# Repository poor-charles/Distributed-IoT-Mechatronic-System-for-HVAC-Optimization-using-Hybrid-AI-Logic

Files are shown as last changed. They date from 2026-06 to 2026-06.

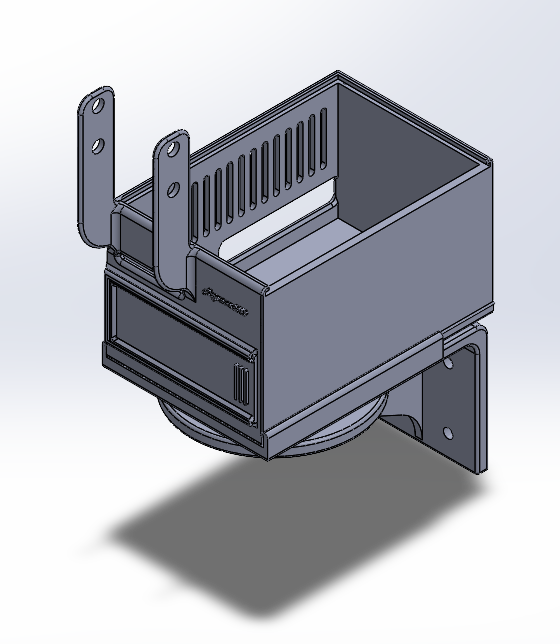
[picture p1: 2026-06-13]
Hardware System Files/Enclosures/Raspberry Pi 5/Raspberry Pi 5 Enclosure Assembly.png

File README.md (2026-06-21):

# Distributed-IoT-Mechatronic-System-for-HVAC-Optimization-using-Hybrid-AI-Logic
A Bayesian Optimized Random Forest model integrated with deterministic physics based safety guardrails to control HVAC operation modes, hunting for the operational settings that minimizes energy consumption while maintaining comfort based on ASHRAE 55 Standards.

--> The Repo contains all the necessary files, programs, and data along with instructions to replicate the system. 

--> Necessary adjustments in the programs such as file locations/directories indicated in the program globals MUST BE CHANGED accordingly.

[AI Model Files]
- To be updated & managed by Charles Vincent Mayaman

[Digital Twin Model Files]
- To be updated & managed by Rissby Arne Cerna

[Hardware System Files]
- Updated & Managed by Paolo Renomeron

General Note: To be updated...

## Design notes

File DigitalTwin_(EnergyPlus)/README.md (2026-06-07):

# Digital Twin (EnergyPlus) Framework for HVAC Energy Performance Assessment

## Overview

This repository contains the complete implementation of an EnergyPlus-based Digital Twin developed for HVAC energy performance assessment through virtual parallel operation. The framework integrates Building Energy Modeling (BEM), Bayesian calibration, independent validation, MQTT-based real-time telemetry, and operational dashboard visualization.

The Digital Twin was developed to reproduce the operational behavior of the target conference room and enable continuous comparison between measured and simulated building performance. The framework supports both energy-performance assessment and comfort-related evaluation through real-time monitoring of indoor temperature, relative humidity, and Predicted Mean Vote (PMV).

---

## Technologies Used

* EnergyPlus 25.1
* Python
* Eppy
* Pandas
* NumPy
* Scikit-Optimize (Bayesian Optimization)
* MQTT
* Streamlit
* SQLite

---

## Digital Twin Development Workflow

### Script 1 – Data Preprocessing

Prepares and cleans the measured datasets collected from the physical building. Sensor data are synchronized, formatted, and converted into analysis-ready datasets.

### Script 2 – EnergyPlus Schedule Generation

Generates occupancy, thermostat setpoint, and workshop temperature schedules required for EnergyPlus simulation.

### Script 3 – Baseline Model Assessment

Evaluates the performance of the uncalibrated Building Energy Model by comparing simulated results against measured building data.

### Script 4 – Bayesian Optimization Parameter Space Definition

Defines the calibration parameters and allowable search ranges used by the Bayesian optimization framework.

### Script 5 – EnergyPlus Parameter Injection and Simulation Run

Automatically modifies EnergyPlus model parameters based on candidate solutions generated by the optimizer and executes simulation runs.

### Script 6 – Calibration Scoring and Model Performance Evaluation

Calculates calibration metrics including RMSE, CV(RMSE), and NMBE for HVAC energy consumption, indoor temperature, and relative humidity.

### Script 7 – Bayesian Calibration Optimization Loop

Implements Gaussian Process Regression (GPR)-based Bayesian Optimization to identify the parameter set that best matches measured building performance.

### Script 8 – Calibration Results Extraction and Visualization

Extracts the champion calibrated model and generates calibration comparison plots, scatter plots, and residual analyses.

### Script 9 – Independent Validation Data Preparation

Processes unseen operational data and prepares validation schedules and measured datasets.

### Script 10 – Independent Validation Simulation

Executes the calibrated Digital Twin using independent validation data.

### Script 11 – Validation Results Analysis and Visualization

Calculates validation metrics and generates validation time-series plots, scatter plots, and residual histograms.

### Script 12 – Operational Digital Twin Dashboard

Provides a Streamlit-based dashboard for real-time visualization of building performance and Digital Twin outputs.

### Script 13 – Real-Time Operational Digital Twin Engine

Implements live synchronization between the physical asset and EnergyPlus through MQTT communication, enabling real-time virtual parallel assessment.

### Operational Digital Twin Launcher

Automatically launches the Operational Digital Twin Dashboard and Real-Time Digital Twin Engine to support deployment and real-time virtual parallel assessment.

---

## Calibration and Validation Metrics

Calibration Performance:

* HVAC Energy CV(RMSE): 29.96%
* HVAC Energy NMBE: 9.96%

Validation Performance:

* HVAC Energy CV(RMSE): 28.23%
* HVAC Energy NMBE: 7.64%

Both calibration and validation satisfied the ASHRAE Guideline 14 acceptance criteria for hourly energy calibration.

---

## Operational Digital Twin Capabilities

The operational Digital Twin supports:

* Real-time occupancy integration
* Real-time thermostat updates
* Indoor temperature monitoring
* Indoor relative humidity monitoring
* PMV monitoring
* HVAC energy assessment
* Virtual parallel assessment
* Dashboard-based visualization

---

## Research Contribution

This work demonstrates the feasibility of developing a calibrated and validated EnergyPlus-based Digital Twin using open-source technologies for building energy performance assessment, operational monitoring, and future intelligent building applications.

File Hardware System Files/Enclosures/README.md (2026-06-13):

eto yung mga enclosures and shii

mor instructions inside

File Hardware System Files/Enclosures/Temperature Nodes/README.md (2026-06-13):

ESP 1 (Dynamic Inside Sensor) and ESP 3 (Outside Sensor) Enclosure Folder:

-----------------------------------------------------------------------------------

Use the attached .gcode to directly print the enclosure and and its covers.

Feel free to modify the .SLDPRT version if you want to add or edit features.

-----------------------------------------------------------------------------------

Setting:
  Bambu Lab A1 Mini, PLA Lite

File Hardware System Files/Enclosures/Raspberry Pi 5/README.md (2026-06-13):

Raspberry Pi 5 Enclosure and Platform Folder:

-----------------------------------------------------------------------------------

Refer to the .png file included for the enclosure assembly.

Use the attached .gcode to directly print the enclosure and its platform.

Feel free to modify the .SLDPRT version if you want to add or edit features.

-----------------------------------------------------------------------------------

Setting:
  Bambu Lab A1 Mini, PLA Lite

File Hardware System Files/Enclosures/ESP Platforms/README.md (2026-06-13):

ESP Node Platform Folder:

-----------------------------------------------------------------------------------

Setting:
  Bambu Lab A1 Mini, PLA Lite

  ESP 2, ESP 4, and ESP 5 uses Stand v1
  
  ESP 3 uses Stand v3
  
  ESP 1 does not need a platform

-----------------------------------------------------------------------------------

Refer to the .png files included for the platform orientation.

Use the attached .gcode to directly print the enclosure and and its covers.

Feel free to modify the .SLDPRT version if you want to add or edit features.

-----------------------------------------------------------------------------------

Setting:
  Bambu Lab A1 Mini, PLA Lite

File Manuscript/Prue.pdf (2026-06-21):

DEVELOPMENT OF A DISTRIBUTED IOT MECHATRONIC SYSTEM FOR HVAC OPTIMIZATION USING HYBRID AI LOGIC

A Thesis Manuscript
Presented to the Faculty of the Department of Mechanical Engineering Visayas State University
Visca, Baybay City, Leyte

In Partial Fulfillment
of the Requirements for the Degree of Bachelor of Science in Mechanical Engineering

RISBBY ARNE P. CERNA
CHARLES VINCENT MAYAMAN
PAOLO L. RENOMERON
June 2026

i

APPROVAL SHEET

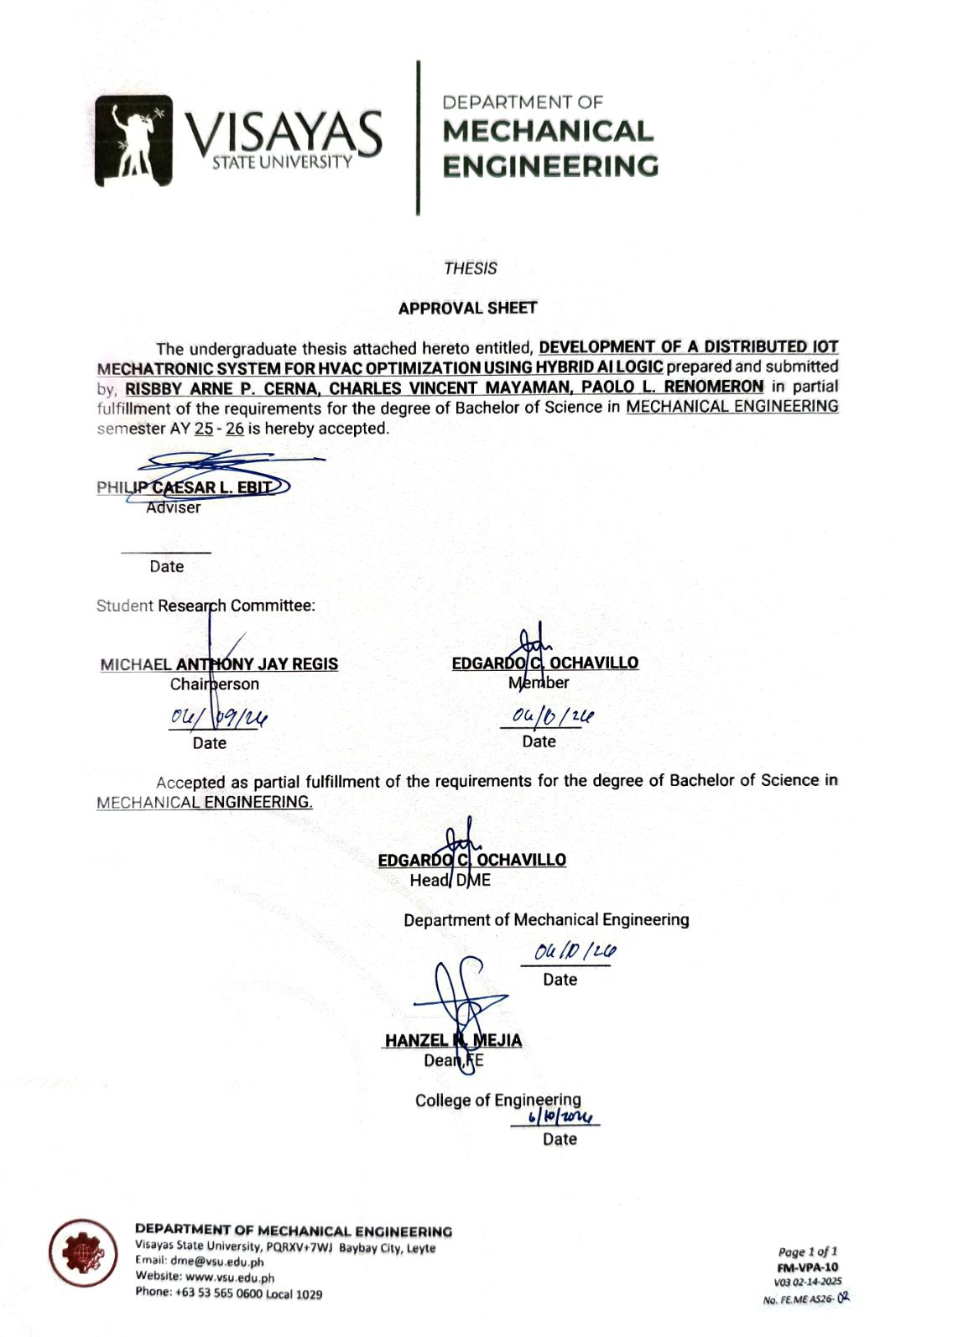
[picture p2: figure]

ii

ENGLISH CRITIC CERTIFICATION

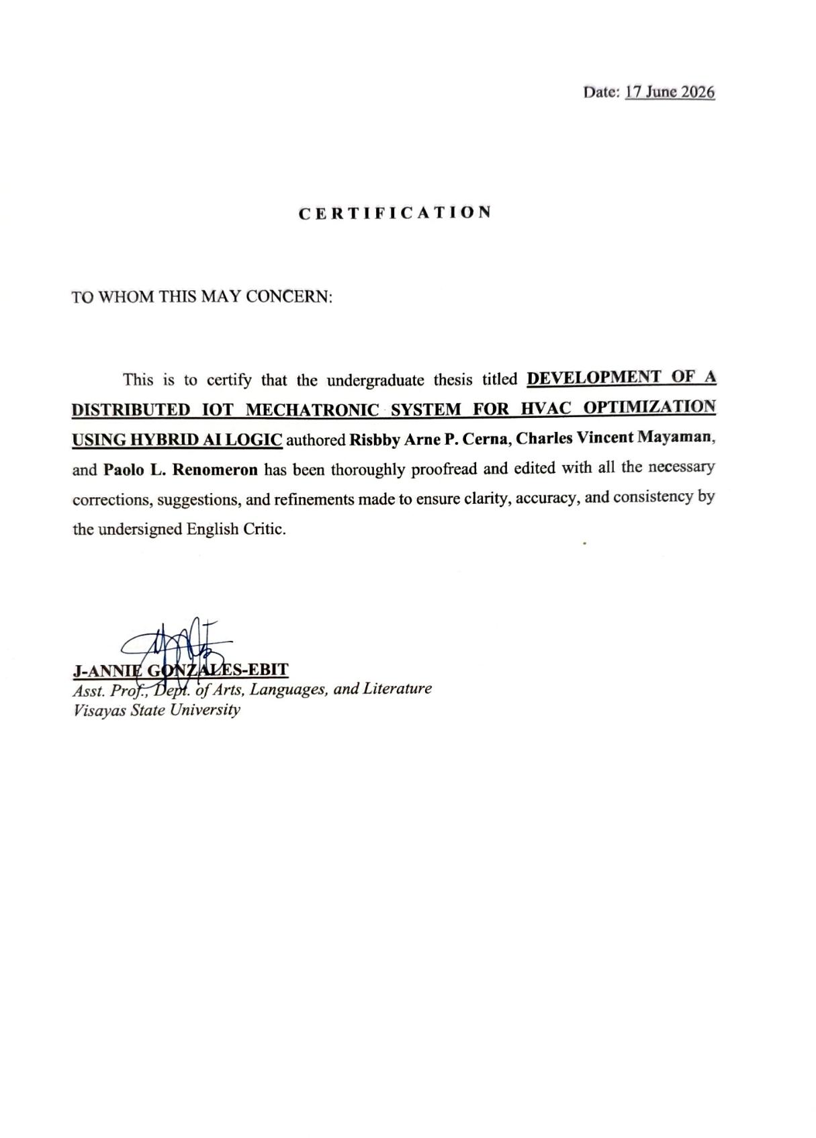
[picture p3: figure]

iii

ACKNOWLEDGMENT

The successful completion of this manuscript would not have been possible

without the invaluable support, guidance, and participation of the following individuals.

The authors would like to take this opportunity to express their sincerest gratitude.

First and foremost, the authors express their deepest gratitude to their research

adviser, Engr. Philip Caesar L. Ebit, and to the chairperson of the Student Research

Committee (SRC), Mr. Michael Anthony Jay Regis, for the invaluable technical

insights, academic mentorship, and profound knowledge they generously shared

throughout this study. Their guidance was instrumental in transforming this research

concept into a reality.

The authors gratefully acknowledge the Department of Science and Technology

- Science Education Institute (DOST-SEI) for providing financial and academic support

to the scholar within the research group, which proved vital to the development of this

project under the RA 7687 Science and Technology Scholarship Act.

Special thanks are due to JASCad for their technical assistance during the

fabrication phase. Their expertise in designing and manufacturing the custom printed

circuit boards (PCBs) is highly appreciated, as these high-fidelity modules ensured

hardware node stability and minimized environmental signal noise during data

collection.

The authors extend their appreciation to the research participants, specifically

the PSME-VSUSC officers and members, whose consistent presence and active

iv

utilization of the target study room facilitated the reliable aggregation of dynamic

occupancy and environmental data. Their cooperation was essential to the completion

of the physical field testing.

Heartfelt thanks go to the researchers’ peers and friends who assisted in various

logistical tasks, ranging from data organization to providing moral support throughout

the data-gathering phase.

The authors are profoundly thankful to their families for their unwavering

patience, understanding, and encouragement during periods of intense academic

pressure. Their constant support and sacrifices served as a vital source of inspiration

throughout this journey.

Above all, the authors offer their ultimate praise and gratitude to the Almighty

God for providing spiritual strength, wisdom, and clarity during moments of

uncertainty, and for granting the grace and guidance necessary to bring this endeavor

to a successful completion.

v

TABLE OF CONTENTS

vi

Multi-Objective Optimization and Digital Twin Applications | 37
The Role of BEM in Digital Twin Architecture | 39
Edge-Hosted Digital Twins | 41
Machine Learning and Data-Driven Optimization | 41
Implementing Digital Twin to Quantify Energy Consumption | 43
Open-Source Building Energy Modeling | 45
OpenStudio Software | 45
OpenStudio Plugin | 46
EnergyPlus Engine | 48
HVAC System in EnergyPlus Engine | 50
Calibration Frameworks | 52
Automated Parametric Calibration in Building Energy Modeling | 53
Why Bayesian Calibration Method? | 54
Derivative-Free Search via Bayesian Optimization | 56
Surrogate Modeling Using Gaussian Processes | 58
ASHRAE Guideline 14 | 59
Automated Frameworks for Quantitative Evaluation | 61
Standardization of Evaluation Metrics for Environmental Variables | 62
International Organization for Standardization (ISO) 13786:2017 | 63
Dynamic Thermal Characterization of Building Components | 64
Theoretical Framework of ISO 13786:2017 | 64
International Organization for Standardization (ISO) 15099:2003 | 66
Thermodynamic Characterization of Fenestration Systems | 66
Thermodynamic Algorithms | 67
International Organization for Standardization (ISO) 6946:2017 | 68
Thermodynamic Characterization of Interstitial Air Cavities | 69

vii

Thermodynamic Mechanics | 69
IoT Architecture in HVAC Systems | 71
HVAC Automation and Control System Architectures | 71
Internet of Things (IoT) Integration in HVAC Systems | 74
Performance Evaluation of IoT-Based HVAC Controllers | 75
Energy Consumption Measurement Methods | 76
Reliability and Communication Performance Metrics | 77
Control Accuracy Assessment | 78
Scalability Analysis of Distributed IoT Systems | 78
Techno-Economic Evaluation of HVAC IoT Controllers | 79
Economic Performance Metrics | 80
METHODOLOGY | 82
Research Workflow | 82
Planning and Design of the System | 84
Thermodynamic Disturbances and Thermal Loads | 86
Exogenous Thermal Loads (Building Envelope Heat Transfer) | 87
Metabolic Heat Generation (Occupancy Load) | 88
Internal Equipment Loads (Parasitic Heat Gains) | 88
Thermal Comfort Optimization Method Using ASHRAE 55 | 89
Headless Occupancy Detection and Counting (YOLOv8n) | 97
Data Acquisition and Machine Learning Training | 101
Variable Classification and Measurement Parameters | 102
Telemetry Architecture and Data Aggregation | 103
Experimental Boundary Scenarios | 103
Dataset Finalization | 104
Machine Learning Framework and Model Training (BORF) | 105

viii

The Supervisory Controller [Raspberry Pi 5] | 109
Operating System Installation and Configuration | 111
Python Environment and Version Control | 112
Virtual Environment (venv) Initialization | 112
Dependency and Library Installation | 112
MQTT Broker System Integration | 113
The Main Program | 116
The Data Managing Program | 120
The Decision Maker Program | 122
Hybrid Predictive Control and Deterministic Guardrails | 123
Transient Response and Steady-State Monitoring | 125
Dynamic Actuation Timeout Windows | 125
ML Re-Evaluation and Directional Guardrails | 126
Hard-Coded Corrective Actuation | 126
Steady-State Maintenance and Energy Optimization | 127
Weather-Normalized Energy Evaluation (ASHRAE Guideline 14 - CDH) | 127
Experimental Control of Exogenous Heat Loads | 129
Digital Twin Architecture | 130
Site Survey and Architectural Data Acquisition | 132
Acquisition of Archival Blueprints | 132
On-Site Geometric Verification and Manual Auditing | 133
Geometrical and Envelope Modeling | 133
Simulation Environment | 136
Meteorological Data and Environmental Boundary Conditions | 137
Extraction and Temporal Alignment of Simulation Outputs | 138
Control Parameters | 139

ix

Internal Thermal Loads | 140
HVAC System Configuration | 141
Computational Environment Setup and Empirical Data Processing | 143
Software Environment and Dependency Configuration | 144
Empirical Data Acquisition and Pre-processing Pipeline | 144
Temporal Aggregation for Statistical Calibration Validation | 146
Annualization and Formatting of Empirical Boundary Schedules | 146
Automated Parametric Mutation and Simulation Execution | 149
Programmatic IDF Manipulation via eppy | 149
Dynamic Boundary Condition Mapping | 150
Headless Simulation Execution | 151
Parameterization and Definition of the Optimization Search Space | 152
Algorithmic Constraints and Physical Realism | 152
Selection and Justification of Calibration Variables | 153
Search Space Initialization | 154
Statistical Indices for Calibration and Validation | 155
Composite Scoring and Model Selection | 156
Bayesian Optimization Framework and Automated Calibration Loop | 157
Algorithmic Selection: Gaussian Process Minimization | 158
The Iterative Execution Pipeline | 158
ASHRAE Guideline 14 Validation and Early Stopping Criteria | 159
Preparation of Unseen Empirical Data for Model Validation | 160
Purpose of Independent Data Validation | 161
Ingestion and Temporal Synchronization of Unseen Data | 161
Annualization of Validation Boundary Conditions | 162
Formatting Target Ground Truth Data for Scoring | 163

x

Execution of Independent Model Validation and Performance Verification .........164

Integration of Validation Boundaries into the Calibrated Model | 164
Simulation Execution and Output Extraction | 165
Statistical Verification Against Industry Standards | 166
Automated Reporting and Graphical Analysis | 166
Deployment of the Operational Digital Twin for Real-Time Simulation | 167
Architecture of the Co-Simulation Framework and Session Archival | 169
Asynchronous IoT Telemetry and Concurrent State Management | 170
Pre-Run State Synchronization and the Eradication of Data Starvation | 171
Thermodynamic Warmup Stabilization and Boundary Control | 172
Fractional Load Transformation and Dynamic HVAC Translation | 173
Strict Temporal Pacing and Bivariate Data Extraction | 174
Automated Interruption and Diagnostic Performance Reporting | 175

Development of the Real-Time Graphical User Interface and Visualization

Dashboard | 176
Architectural Framework and Dynamic Session Synchronization | 176
Asynchronous Data Ingestion and Operational Shift Aggregation | 177

Programmatic Geometry Parsing and 3D Colorimetric Thermal Mapping.......178

Comparative Interface Topology and Real-Time Delta Tracking | 180
High-Fidelity Time-Series Analytics and Visual Aggregation | 181
Distributed IoT Mechatronic Controller | 182
Main Hub | 183
ESP32 Nodes | 186
Dynamic Inside Sensor and Outside Sensor | 188
Static Inside Sensor | 190
ACU Power Monitoring Nodes | 192

xi

Prototype Testing for Technoeconomic Analysis | 195
Technical Evaluation | 197
Economic Assessment | 199
RESULTS AND DISCUSSIONS | 205
Machine Learning (B.O.R.F.) Training | 205
Comparative Performance Evaluation: BORF vs. Manual Operation | 214
Test A | 215
Test B | 221
Test C | 224
Test N | 228
Test D | 230
Drivers of Energy Savings | 235
Dynamic Actuation of Native HVAC Modes | 236
Partial Loading of Air-Conditioning System | 240
Performance Assessment of the Digital Twin | 242
Baseline Model Assessment Prior to Bayesian Calibration | 243
Times Series Assessment of Baseline Model | 244
Correlation Analysis of Baseline Model | 248
Performance of the Calibrated Model | 251
Correlation Analysis of Calibrated Model | 260
Residual Error Analysis of the Calibrated Model | 263
Validation Performance Metrics Using Unseen Operational Data | 267
Validation Correlation Analysis | 271
Operational Digital Twin Dashboard | 275
Operational Performance Assessment | 277
Technoeconomic Analysis | 281

xii

Technical Metrics | 281
Computational Performance | 282
Communication Reliability | 288
Energy Consumption | 295
System Stability | 300
Economic Analysis | 303
CapEx Calculation | 303
OpEX Calculation | 308
Annual Energy Savings | 309
Payback Period (PBP) and Return of Investment (ROI) | 310
CONCLUSIONS AND RECOMMENDATIONS | 314
Conclusions | 314
Hybrid Machine Learning Model System | 314
Digital Twin | 315
Distributed IoT-Mechatronic Controller | 318
Recommendations | 320
LITERATURE CITED | 326
APPENDICES | 339

xiii

LIST OF TABLES

Table 1. Metabolic rates for typical tasks by ASHRAE 55 | 96
Table 2. YOLOv8n configuration values | 101
Table 3. Bayesian training search range and optimization factors | 107
Table 4. Thermo-physical properties | 135
Table 5. Structural composition of the materials | 136
Table 6. Control Parameters | 140
Table 7. Year-on-Year Inflation Rates by Commodity Group: NCR | 201
Table 8. Bayesian Optimized Random Forest model highest score parameters........207 Table 9. Sample scores hunted by Bayesian Optimizer across different parameters.209
Table 10. Test A Results Summary | 218
Table 11. Test B Results Summary | 222
Table 12. Test C Results Summary | 225
Table 13. Test N Results Summary | 228
Table 14. Test D Results Summary | 230
Table 15. Consolidation of hybrid system’s energy saving performance | 234
Table 16. Baseline Performance Metrics | 244
Table 17. Ten Highest-Performing Parameter Combination | 252
Table 18. Ten Highest-Performing Metrics | 254
Table 19. Interpretation Baseline Assumptions and Final Parameter Values | 257
Table 20. Physical Value | 259
Table 21. Validation Performance Metrics | 267
Table 22. Operational Performance Metrics | 277
Table 23. Excerpt of CPU Utilization % Dataset | 282
Table 24. CPU Utilization Data Summary | 283
Table 25. Excerpt of CPU Temperature (°C) Dataset | 284
Table 26. CPU Temperature Data Summary | 285
Table 27. Excerpt of CPU Utilization % Dataset | 286
Table 28. RAM Percentage and Usage Data Summary | 287
Table 29. Excerpt of Network Load Dataset | 289
Table 30. Network Load Data Summary | 290
Table 31. Excerpt of Latency (ms) Dataset | 291
Table 32. Latency Data Summary | 292
Table 33. Excerpt of Rate of Packet Loss (%) Dataset | 293
Table 34. Packet Loss Data Summary | 293
Table 35. Excerpt of Raspberry Pi 5 Power Dataset | 295
Table 36. Raspberry Pi 5 Power Metrics Summary | 296
Table 37. Excerpt of ESP Nodes Power Dataset | 297
Table 38. ESP Nodes Power Metrics Summary | 298
Table 39. ESP Nodes Power Metrics Summary | 299
Table 40. Logging Completeness Summary | 301
Table 41. Total Equipment Costs | 304
Table 42. Total Deployment Costs | 307
Table 43. Electricity Costs | 308
Table 44. Annual Energy Savings | 310

xiv

LIST OF FIGURES

Figure 1. PID Logic of ACU Systems (Sahu et al., 2025) | 3
Figure 2. Multi-Dimensional System of HVAC Optimization | 4
Figure 3. Conventional Inverter ACU Control Logic | 5
Figure 4. Applied Hybrid AI Predictive Control Logic | 7
Figure 5. Overview of the DME Workshop | 14
Figure 6. DME Conference Room (Room of Study) | 14
Figure 7. Air-conditioning Unit Specifications | 15
Figure 8. Samsung 1.5 HP 1 Ton Inverter | 16
Figure 9. General Royal 1.5 HP 1 Ton Inverter | 16
Figure 10. Digital Twin Maturity Model | 39
Figure 11. Real-time IoT Telemetry and Physics-Based BEM Engines | 42
Figure 12. EnergyPlus Application Programming Interface (API) | 43
Figure 13. OpenStudio Software | 46
Figure 14. Building Energy Modeling (BEM) Digital Twin | 47
Figure 15. EnergyPlus Packaged Terminal Air Conditioning Design | 52
Figure 16. DC Power Monitoring via a Shunt Resistor (Masdani, et al., 2018) | 76
Figure 17. Research Workflow | 83
Figure 18. Locations of Each Node Relative to Test Room | 84
Figure 19. System Architecture | 84
Figure 20. System Design and Communication Protocol | 86
Figure 21. PMV Adjustment Workflow | 91
Figure 22. Thermal Comfort Index – PMV | 92
Figure 23. Derived PMV Parameters | 93
Figure 24. Clothing Factors by ASHRAE 55 Standards | 96
Figure 25. Raspberry Pi Cam 3 Wide Specifications | 98
Figure 26. Image Processing Flowchart | 98
Figure 27. Sample Live View of Calibrated YOLOv8n | 100
Figure 28. Detailed Camera Location | 101
Figure 29. Bayesian Optimized Random Forest Model | 105
Figure 30. BORF Training Chart | 106
Figure 31. Raspberry Pi 5 8Gb | 110
Figure 32. Raspberry Pi 5 Specifications | 110
Figure 33. Main Program Process Flowchart | 114
Figure 34. Hybrid AI Model Decision Process | 117
Figure 35. Detailed Logic Flow for Main Program | 119
Figure 36. Data Managing Program Logic Flow | 120
Figure 37. Machine Learning Algorithm | 122
Figure 38. Deterministic Guardrails for AI Model | 124
Figure 39. Data-driven Computational Framework | 131
Figure 40. Boundary Condition of the Model in OpenStudio Plug-in | 134
Figure 41. Thermal Zoning of the Model in Open Studio Plug-in | 134
Figure 42. Reconfigured Package Terminal Air Conditioner (PTAC) in OpenStudio
| 142
Figure 43. Programmatic IDF Manipulation via Eppy | 150

xv

Figure 44. Operational Digital Twin for Real-Time Simulation Framework | 169
Figure 45. Main Hub Schematic Diagram | 184
Figure 46. Main Hub Assembly, Digital (left) and Actual (right) | 185
Figure 47. Temperature Sensors Schematic Diagram | 188
Figure 48. Temperature Sensors, PCB Design | 189
Figure 49. Dynamic Inside Sensor, Digital (left), Actual (right) | 189
Figure 50. Outside Sensor, Digital (left), Actual (right) | 190
Figure 51. Static Inside Sensor, Schematic Diagram | 191
Figure 52. Static Inside Sensor, PCB Design | 191
Figure 53. Static Inside Sensor, Digital (left), Actual (right) | 192
Figure 54. ACU Power Monitoring Nodes, Schematic Diagram | 193
Figure 55. ACU Power Monitoring Nodes, PCB Design | 194
Figure 56. ACU Power Monitoring Nodes, Digital (left), Actual (right) | 194
Figure 57. Metrics Extraction Layout | 196
Figure 58. Metrics Extraction Flowchart | 196
Figure 59. Manual Calibration of the Raspberry Pi 5 Power Estimator | 198
Figure 60. Training Dataset Structure | 206
Figure 61. BORF Training and Evaluation Results | 207
Figure 62. Model Features Importance Breakdown | 208
Figure 63. 3D Graph of Model Parameters vs Model Performance | 210
Figure 64. True Value vs. Model Predictions | 212
Figure 65. Performance Test A | 215
Figure 66. Performance Test B | 221
Figure 67. Performance Test C | 224
Figure 68. Performance Test N | 228
Figure 69. Performance Test D | 230
Figure 70. Performance Test E | 232
Figure 71. Performance Test F | 233
Figure 72. Performance Test G | 233
Figure 73. Relationship of Temperature and Relative Humidity | 236
Figure 74. Effects of Cool and Dry Modes on Humidity | 238
Figure 75. COP of ACU Across Various Compressor Loads | 241
Figure 76. Simulated vs Measured of Baseline AC Energy Consumption | 247
Figure 77. Simulated vs Measured of Baseline Indoor RH | 247
Figure 78. Simulated vs Measured of Baseline Indoor Temperature | 248
Figure 79. Correlation Analysis of Baseline AC Energy Consumption | 250
Figure 80. Correlation Analysis of Baseline Indoor Temperature | 250
Figure 81. Correlation Analysis of Baseline Indoor RH | 251
Figure 82. Simulated vs Measured of Calibrated AC Energy Consumption | 255
Figure 83. Simulated vs Measured of Calibrated Indoor RH | 256
Figure 84. Simulated vs Measured of Calibrated Indoor Temperature | 256
Figure 85. Correlation Analysis of Calibrated AC Energy Consumptions | 262
Figure 86. Correlation Analysis of Calibrated Indoor Temperature | 262
Figure 87. Correlation Analysis of Calibrated Indoor RH | 263
Figure 88. Residual Analysis of Calibrated AC Energy Consumptions | 265
Figure 89. Residual Analysis of Calibrated Indoor RH | 266
Figure 90. Residual Analysis of Calibrated Indoor Temperature | 266

xvi

Figure 91. Simulate vs. Measured of Validated AC Energy Consumption | 270
Figure 92. Simulate vs. Measured of Validated Indoor Temperature | 270
Figure 93. Simulate vs Measured of Validated Indoor RH | 271
Figure 94. Correlation Analysis of Validated AC Energy Consumption | 273
Figure 95. Correlation Analysis of Validated Indoor RH | 274
Figure 96. Correlation Analysis of Validated Indoor Temperature | 274
Figure 97. Graphical User Interface Live Dashboard | 276
Figure 98. Simulated vs. Measured of Operational Digital Twin of AC Energy
Consumption | 280
Figure 99. Simulated vs. Measured of Operational Digital Twin of Indoor Temperature
| 280
Figure 100. Simulated vs. Measured of Operational Digital Twin of Indoor RH......281 Figure 101. 52PI Low-Profile ICE Tower w/ Heatsink 30-min Bench Test Results.286
Figure 102. Excerpt of the System’s Collected Dataset | 301
Figure 103. Smart HVAC Controller Consumer-Side Assumptions | 311
Figure 104. Consumer Adoption Scenarios | 312
Figure 105. Consumer Cash Flow: Existing HVAC vs Smart HVAC Control | 312

xvii

LIST OF EQUATIONS

(1) PID Logic of ACU Systems (Sahu et al., 2025) | 3
(2) Packet Loss Rate (Qiu et al., 2021) | 77
(3) Packet Failure Rate (Qiu et al., 2021) | 77
(4) Probablity of Failure per Hour (Qiu et al., 2021) | 77
(5) Temperature Root Mean Square Error (Palaić et al. 2025) | 78
(6) CapEX (Belgard et al., 2024) | 80
(7) OpEX (Belgard et al., 2024) | 80
(8) Payback Period (PBP) (Belgard et al., 2024) | 81
(9) Return of Investment (ROI) (Belgard et al., 2024) | 81
(10) Radiant Temperature and Ambient Temperature Assumption | 94
(11) Air Velocity Assumption | 94
(12) Thermal Insulation by Clothing Assumption | 95
(13) Cooling Degree Hour (CDH) | 128
(14) Normalized Energy Consumption | 128
(15) Coefficient of Variation of the Root Mean Square Error | 155
(16) Normalized Mean Bias Error | 155
(17) Coefficient of Determination | 156
(18) Composite Scoring | 156
(19) Capital Expenditures (CapEX) | 200
(20) Operating Expenditures (OpEX) | 200
(21) Annual Energy Savings (AES) | 202
(22) Energy Savings Percentage (ES%) | 202
(23) Electricity Rate Projection | 202
(24) Manual HVAC Consumption Projection | 203
(25) Smart HVAC Consumption Projection | 203
(26) Manual Bill | 203
(27) Smart Bill | 203
(28) Annual Net Savings | 203
(29) Payback Period (PBP) | 204
(30) Return of Investment | 204
(31) Equivalent Manual System Consumption | 220
(32) Energy Saving in kWh | 220

xviii

LIST OF APPENDICES

Appendix A – Software Repository, Libraries, and Database Accessibility | 340
Appendix B – DME Floor Plan | 341
Appendix C – General Royal ACU Specifications | 342
Appendix D – Temperature Nodes PCB Schematic Diagram | 343
Appendix E – IR Transmitter Node PCB Schematic Diagram | 344
Appendix F – ACU Power Monitoring Nodes PCB Schematic Diagram | 345
Appendix G – DME Conference Room Usage Letter for Testing | 346
Appendix H – DME Building Plan Request Letter | 347
Appendix I – DME Conference Room Usage Letter for Deployment | 348
Appendix J – Gantt Chart of Activities | 349
Appendix K – Thesis Proposal Approval Sheet | 350
Appendix L – Documentations | 351

xix

ABSTRACT

This study developed and evaluated a distributed Internet of Things (IoT)

mechatronic framework integrating hybrid artificial intelligence (AI), a Building

Energy Modeling (BEM)-based Digital Twin, and edge-computing control architecture

for Heating, Ventilation, and Air Conditioning (HVAC) optimization. The system was

designed to reduce energy consumption while maintaining thermal comfort in

accordance with ASHRAE Standard 55. A Raspberry Pi 5 served as the supervisory

controller, coordinating ESP32-based sensor nodes through the MQTT protocol to

acquire environmental, occupancy, and energy-consumption data. Occupancy

information was obtained using a headless YOLOv8n computer-vision pipeline, while

all control and processing functions were performed locally through edge computing.

For HVAC optimization, a Bayesian Optimized Random Forest (BORF) model

was developed to learn the nonlinear relationship between thermal comfort and energy

consumption using experimentally collected operational data.

To address the limitations of data-driven models under dynamic real-world

conditions, the machine-learning model was integrated with deterministic physics-

based guardrails that supervised and corrected control actions when necessary.

Although the standalone BORF model achieved modest predictive performance (R² =

0.204 for Predicted Mean Vote and R² = 0.338 for energy prediction), the hybrid

architecture successfully compensated for these limitations during live deployment.

Experimental | results | demonstrated | weather-normalized energy | savings | of

xx

approximately 20% relative to conventional manual operation while maintaining

acceptable occupant comfort conditions.

A physics-based Digital Twin of the target facility was developed using

OpenStudio and EnergyPlus to provide virtual parallel assessment of building

performance. The model underwent automated Bayesian calibration through Gaussian

Process optimization using measured operational data and was evaluated in accordance

with ASHRAE Guideline 14. Following calibration, the Digital Twin successfully

reproduced the thermal and energy behavior of the physical facility and satisfied

established validation criteria. Its deployment enabled continuous comparison between

measured and simulated building conditions, demonstrating its capability as a decision-

support and performance-monitoring platform for HVAC operation.

The distributed IoT-mechatronic controller was implemented using a Raspberry

Pi 5 supervisory hub and ESP32-based sensing and monitoring nodes. Technical

evaluation demonstrated stable computational performance, reliable communication,

minimal packet loss, and low power consumption suitable for long-term deployment.

Economic analysis indicated favorable implementation feasibility through measurable

annual energy savings and positive investment returns. Collectively, the findings

demonstrate that the integration of hybrid AI control, calibrated Digital Twin

technology, and distributed IoT-mechatronic architecture provide a practical, scalable,

and techno-economically viable framework for intelligent HVAC management.

xxi

Keywords: HVAC Optimization; Hybrid Artificial Intelligence; Digital Twin; Building

Energy Modeling (BEM); Internet of Things (IoT); Distributed Mechatronic

Controller; Thermal Comfort (PMV); Bayesian Optimized Random Forest (BORF);

Edge Computing; Technoeconomic Analysis.

CHAPTER 1

INTRODUCTION

This chapter presents the foundation of the study by discussing the need for

intelligent and energy-efficient HVAC control systems in modern buildings. It

introduces the integration of hybrid artificial intelligence, distributed Internet of Things

(IoT) mechatronic architecture, and Digital Twin technology as a unified framework

for optimizing thermal comfort and energy consumption.

Nature and Importance of the Study

Heating, Ventilation, and Air Conditioning (HVAC) systems account for

approximately 30% to 40% of the total energy consumption in residential and

commercial buildings, representing a primary driver of operational expenditures and

greenhouse gas emissions.

Conventional HVAC control frameworks typically rely on static thermal

setpoints and rigid, time-based schedules. Consequently, these systems fail to account

for the dynamic influences of transient occupancy patterns, varying metabolic activity

levels, and fluctuating ambient environmental conditions. This lack of responsiveness

leads to systemic energy inflation, prolonged thermal discomfort, and operational

inefficiencies.

As global demand for energy-efficient, occupant-centric building management

intensifies, a critical requirement has emerged for intelligent control strategies capable

of transitioning from reactive adjustments to predictive and adaptive decision-making.

2

Recent advancements in Artificial Intelligence (AI), the Internet of Things

(IoT), and cyber-physical modeling present a clear opportunity to transform HVAC

operations through integrated, data-driven automation. Machine learning algorithms

such as Random Forest regression and Predicted Mean Vote (PMV)-based thermal

equilibrium models have demonstrated significant efficacy in forecasting thermal

indoor states and optimizing energy expenditure based on multi-dimensional feature

vectors including temperature, relative humidity, CO2 concentration, and occupancy

patterns. Concurrently, IoT-enabled distributed control architectures facilitate real-time

coordination among edge sensors, actuators, and localized computational nodes,

thereby enhancing scalability and fault tolerance compared to legacy centralized

systems.

Complementing these technologies is the emergence of digital twin

frameworks, which create real-time virtual replicas of physical structures for

continuous monitoring, simulation, and operational optimization. Unlike static

Building Information Modeling (BIM) architectures, digital twins coupled with

Building Performance Simulation (BPS) platforms such as EnergyPlus and OpenStudio

enable predictive validation of HVAC strategies prior to physical deployment, thereby

mitigating trial-and-error energy losses and operational risks.

At the local hardware level, modern split-type inverter air-conditioning units,

such as the Samsung and General Royal systems utilized in this study, rely on internal

Proportional-Integral-Derivative (PID) control loops embedded within their factory

printed circuit boards (PCBs) to regulate compressor frequency and thermal output.

Because these proprietary internal feedback loops are closed and governed via

3

consumer infrared (IR) remote protocols, implementing advanced supervisory

optimization requires an external mechatronic interface capable of translating high-

level algorithmic decisions into compatible IR control vectors.

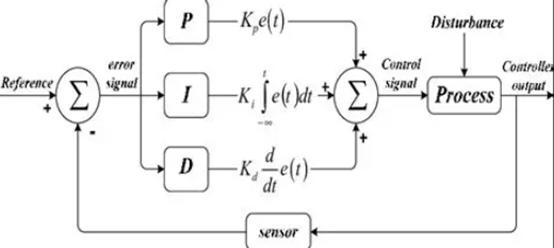
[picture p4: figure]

Figure 1. PID Logic of ACU Systems (Sahu et al., 2025)

Historically, residential cooling systems utilized a binary (On-Off) control

strategy, also known as hysteresis or "bang-bang" control. In this conventional

architecture, the compressor operates at a fixed, maximum angular velocity (ωmax) until

the temperature setpoint is reached, at which point the system undergoes a complete

shutdown.

The compressor remains inactive until the ambient temperature drifts beyond a

predefined threshold, triggering a restart. This cyclic behavior characterized by frequent

inrush current spikes and thermal oscillations results in significant energy inefficiency

and mechanical fatigue due to compressor short cycling.

u(t) = Kpe(t) + Ki ∫ e(τ)dτ + Kd

de(t)
dt

t
0

(1)

In contrast, modern inverter-based systems employ a Proportional-Integral-

Derivative (PID) control logic to achieve variable speed regulation. Rather than binary

states, the PID controller continuously evaluates the system error (e(t)), defined as the

4

instantaneous difference between the user-defined reference (setpoint, Ts
) and the

measured process variable (ambient temperature, To). By modulating the compressor's

RPM in proportion to the magnitude, duration, and rate of change of this error, the

system maintains a state of dynamic equilibrium.

The advantages of this modulated approach are two-fold:

### 1. Energy Conservation. The inverter unit significantly lowers

cumulative power consumption by avoiding the high-torque startup

phases associated with On-Off systems and operating at reduced partial-

load frequencies.

### 2. Mechanical Longevity. The reduction in thermal and mechanical shock

loads extends the operational lifespan of the compressor assembly.

By utilizing this efficient internal PID loop as the foundational layer, this study

seeks to layer a high-level Machine Learning supervisory controller to further optimize

the setpoint inputs, thereby maximizing both energy savings and the comfort of the

occupants.

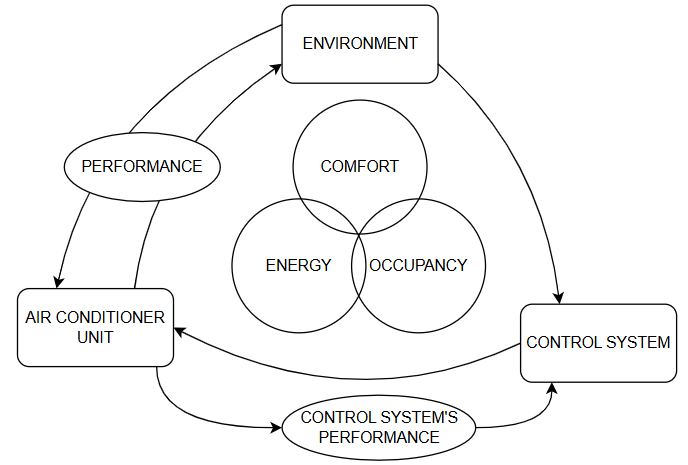
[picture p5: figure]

Figure 2. Multi-Dimensional System of HVAC Optimization

5

While ‘Refrigeration Cycle Theory’ is fundamentally grounded in the second

law of thermodynamics, achieving human thermal comfort introduces a stochastic and

multi-variable layer of complexity. As defined by the ASHRAE Standard 55, comfort

is not a function of dry-bulb temperature alone; it is an equilibrium state influenced by

a synergy of environmental variables including relative humidity, air velocity, and mean

radiant temperature, as well as physiological factors like metabolic rate (met) and

clothing insulation (clo).

The challenge in modern applied physics lies in the integration of these

disparate domains: the fluid dynamics of airflow, the latent heat transfer of humidity,

and the homeostatic regulation of human physiology. Current inverter technology

provides a highly efficient engine for cooling; however, the overall performance of the

system is often throttled by the human-in-the-loop.

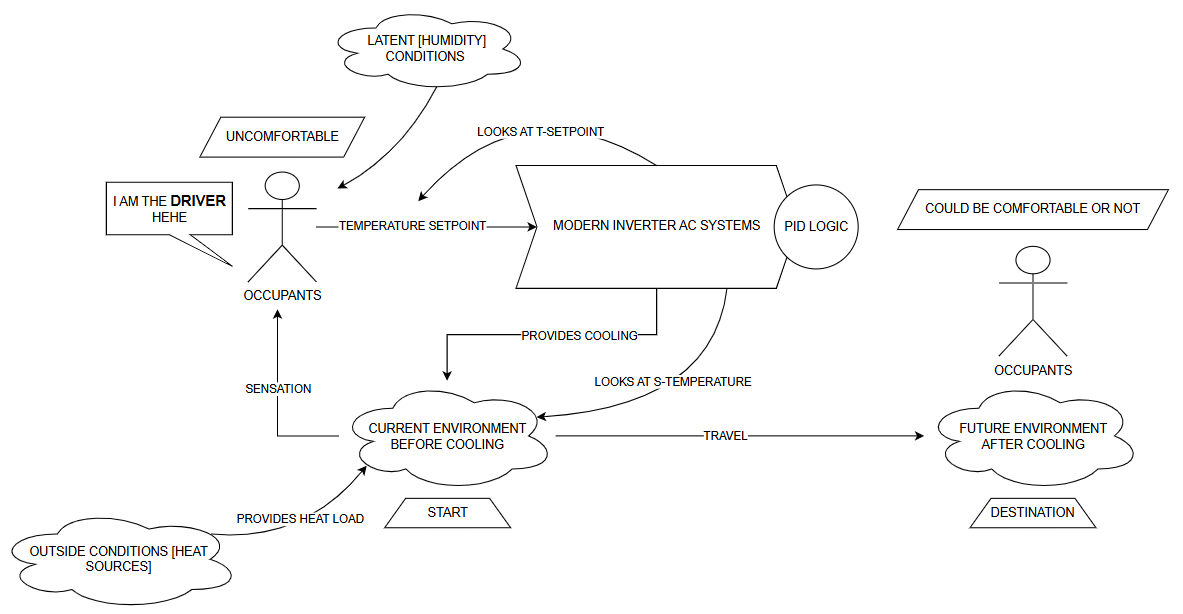
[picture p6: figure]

Figure 3. Conventional Inverter ACU Control Logic

6

To illustrate this systemic limitation, an analogy can be drawn to a high-

performance vehicle optimized for fuel efficiency and precision dynamics. Regardless

of the inherent mechanical and thermodynamic efficiency of the machine, its aggregate

energy consumption and trajectory precision remain fundamentally dictated by the

human operator.

If the driver lacks the high-fidelity technical feedback required to leverage the

advanced powertrain features of the vehicle, the coupled human-machine system

operates in a highly suboptimal state. Analogously, a modern inverter-driven air-

conditioning unit represents a highly efficient thermodynamic tool; however, when

governed by manual human inputs relying on subjective thermal perception rather than

deterministic environmental data, the system fails to achieve its theoretical peak

operating efficiency.

Modern inverter air-conditioning systems are equipped with sophisticated

operational modes and features designed for efficiency; however, there is a significant

discrepancy between system capability and actual user utilization. Empirical

observation suggests that most users bypass advanced settings such as dehumidification

(Dry), sleep curves, or programmable timers and ultra-saving modes, opting instead for

a simplistic interaction model restricted to basic temperature setpoint adjustments. This

manual intervention often results in suboptimal performance, as users lack the real-time

technical data required to align AC settings with dynamic environmental changes.

Furthermore, conventional AC units operate on a closed-loop feedback system

localized primarily to air temperature. This "single-variable" approach is fundamentally

limited, as it ignores critical parameters of human thermal comfort, such as relative

7

humidity, mean radiant temperature, and external ambient fluctuations. By relying

solely on a thermostat, the system fails to achieve true thermal neutrality as defined by

ASHRAE standards. Consequently, the burden of regulation is placed on the user, who

must constantly and inaccurately adjust the unit to compensate for a lack of

comprehensive environmental awareness within the native control logic of the AC unit.

This research proposes the implementation of a Machine Learning supervisory

layer to act as the professional driver. By synthesizing complex environmental inputs

that the average user ignores, the proposed controller can navigate the operational states

of the inverter to achieve a precise destination which is the optimal thermal comfort

with minimal energy expenditure.

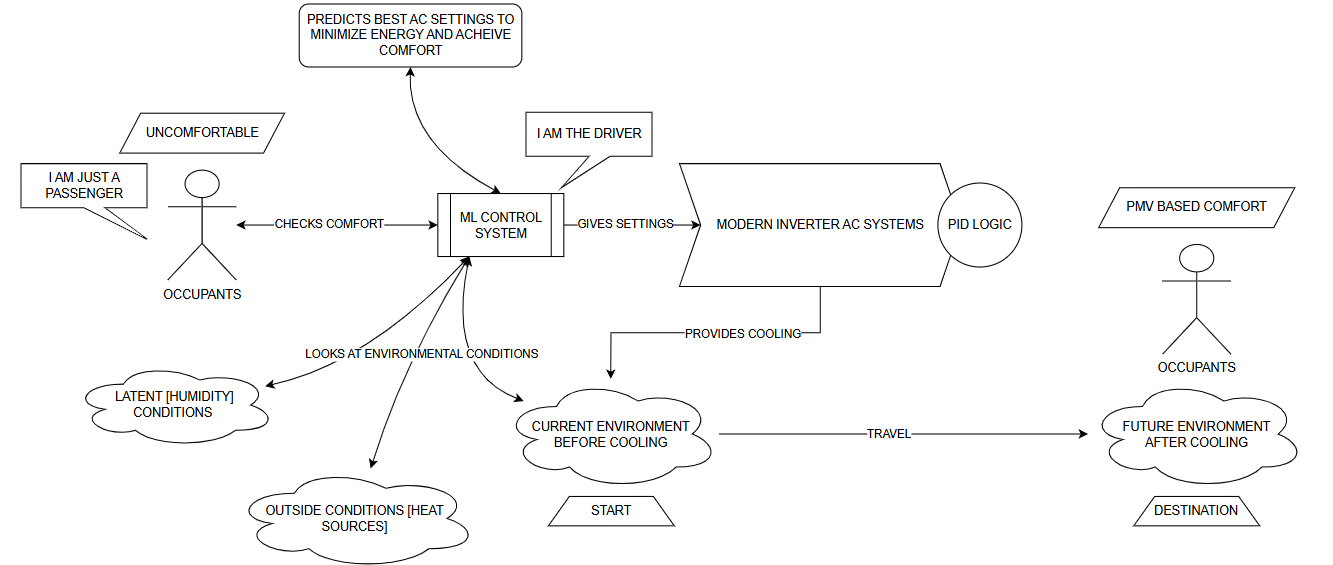
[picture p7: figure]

Figure 4. Applied Hybrid AI Predictive Control Logic

While existing literature extensively explores integrated control strategies for

centralized HVAC systems, such implementations typically necessitate direct

modification of the unit's internal firmware or proprietary hardware. This research

diverges from traditional centralized approaches by proposing a non-invasive,

exogenous control architecture.

8

As illustrated in Figure 4, the system utilizes an external sensor suite to monitor

multi-dimensional environmental factors influencing thermal comfort. These data

points are processed via a Machine Learning (ML) optimizer, which dynamically

determines the ideal operational parameters. These setpoints are then transmitted to the

air conditioning (AC) unit via an Infrared (IR) interface. This method ensures that the

external controller acts as a high-level supervisor analogous to a pilot providing

navigation inputs, while the unit’s internal PID (Proportional-Integral-Derivative) logic

remains responsible for low-level compressor modulation and frequency control.

By decoupling the comfort-seeking logic (ML) from the hardware-level

efficiency logic (PID), the system achieves a dual-optimization state:

### 1. Environmental Optimization. The ML layer ensures the space adheres

to ASHRAE-based thermal comfort standards.

### 2. Operational Efficiency. The native PID controller continues to manage

the inverter’s duty cycle without interference, maintaining high energy-

efficiency ratios (EER).

Ultimately, this design transitions the human occupant from an active controller

to a passive recipient, automating the pursuit of thermal comfort while leveraging the

inherent efficiency of modern inverter technology.

Statement of the Problem

Despite the individual progress in AI-based control, IoT automation, and digital

twin modeling, few studies attempt to unify these three domains under a single techno-

9

economically validated framework. Existing implementations often focus solely on

either control accuracy or simulation fidelity without addressing long-term feasibility

in terms of hardware cost, energy savings, or return on investment.

To address this gap, this study introduces an integrated smart HVAC control

framework combining (1) machine learning-driven adaptive thermal regulation, (2) an

IoT-enabled hierarchical distributed mechatronic controller, and (3) a digital twin-based

simulation environment for pre-deployment validation. The system learns comfort-

energy trade-offs through real-time data acquisition, execute control logic through a

modular distributed network, and be benchmarked through both experimental testing

and techno-economic analysis.

The expected outcome is a practical yet scalable blueprint for intelligent HVAC

automation that achieves measurable energy reduction without compromising occupant

comfort. By utilizing low-cost microcontrollers, open-source AI libraries, and

accessible simulation platforms, the study aims to demonstrate that advanced smart

building technologies can be realistically implemented even in resource-constrained

settings. Ultimately, the research intends to contribute to the progression of sustainable

building management practices by bridging the gap between academic innovation and

real-world applicability.

Objectives of the Study

To design, develop, and implement a distributed mechatronic controller

compatible with IR supported AC Systems with the goal to reduce energy consumption

while maintaining thermal comfort acceptable by ASHRAE Standards.

10

Specifically, the study aims to:

1. Develop a machine learning algorithm capable of learning non-linear

relationships between energy and comfort;

2. Develop a digital twin model of the case study building using an open-

source simulation platform to validate energy and comfort of the target

building through virtual parallel assessment; and

3. Design and implement an IoT distributed mechatronic controller,

compatible with IR-supported air-conditioning units and perform

techno-economic analysis.

Scope and Limitations of the Study

This section delineates the operational scope and inherent technical limitations

of the study, establishing the boundaries that guided the researchers throughout the

execution of this study.

Scope of the Study

To establish clear operational parameters, the scope of this study was explicitly

defined. The following boundaries were strictly observed and enforced throughout the

execution of the research:

1. The machine learning framework utilized Random Forest Regression

optimized via Bayesian Optimization to characterize the non-linear

trade-offs between indoor thermal comfort and HVAC energy

consumption within the target thermal zone.

11

2. The model incorporated the following variables: outside temperature,

outside humidity, inside temperature, inside humidity, occupant count,

electrical energy consumption, and time of day.

3. A distributed mechatronic controller prototype was engineered and

developed for this study, utilizing hardware including, but not limited

to, the Raspberry Pi 5 and ESP32 microcontrollers.

4. The physical deployment encompassed a hybrid control architecture

designed to support the machine learning model and ensure operational

safety. A physics-informed, rule-based supervisory logic was integrated

alongside the BORF model to govern final HVAC operational settings

during live edge computing execution.

5. The development of a digital twin capable of reproducing the

operational behavior of the target facility through virtual parallel

assessment, utilizing an open-source building performance simulation

platform.

6. The research prioritized the representation of measured building

performance and operational responses within the digital twin

environment to facilitate continuous comparison between the physical

asset and its virtual counterpart.

Limitations of the Study

To establish the boundary conditions of this research, the operational and

methodological limitations were explicitly defined. The framework was governed by

12

the following constraints throughout its development, deployment, and evaluation

phases:

1. Control Interface and Integration. The physical execution of the control

system was limited to interfacing with split-type or window-mounted air-

conditioning (AC) units equipped with infrared (IR) remote-control

capabilities. The prototype operated strictly as an external supervisory

overlay without modifying the internal circuitry, hardware components, or

the native proportional-integral-derivative (PID) control loops embedded by

the manufacturer.

2. Spatial and Thermal Zone Configuration. The applicability of the control

system was restricted to single-zone office or classroom environments

characterized by open, unpartitioned layouts. This study excluded spaces

serviced by centralized air-handling units (AHUs) or variable air volume

(VAV) air-distribution cooling networks.

3. Dataset Volumetric Constraints. Due to physical operational constraints,

the machine learning model was trained on a bounded dataset of

approximately 3,000 steady-state data points. Consequently, the standalone

mathematical extrapolation of the predictive model outside this baseline

training envelope is constrained, necessitating the integration of a

deterministic supervisory layer to ensure operational safety under real-world

conditions.

4. Digital Twin Boundary Conditions. The developed digital twin was

engineered to replicate the operational response of the target facility based

strictly on empirical sensor data. The analytical validity of the virtual model

13

was measured by its capacity to reproduce observed building performance

under specific, localized ambient conditions experienced during the testing

window.

5. Calibration Target Limitations. In accordance with ASHRAE Guideline

14, calibration and validation protocols focused primarily on whole-

building HVAC electrical energy consumption. While thermal comfort

indicators such as indoor temperature, relative humidity, and Predicted

Mean Vote (PMV) were calculated and monitored via virtual parallel

assessment, they did not serve as primary objective functions during the

automated mathematical calibration phase.

6. Digital Twin calibration method. Model calibration was performed using

a Bayesian optimization framework based on Gaussian Process Regression.

Consequently, the resulting calibrated parameter set represents the optimal

solution identified within the calibration objectives, parameter ranges, and

search space defined in this study and should not be interpreted as the

definitive physical characteristics of the target building.

Selected Room of Study and Technical Specifications

The physical deployment and empirical data collection for this study were

conducted inside the Department of Mechanical Engineering (DME) Conference

Room. This specific facility was selected due to its representative single-zone thermal

configuration, the presence of a target split-type inverter air-conditioning unit (ACU),

and its high variability in dynamic occupant density. A comprehensive architectural

overview and geometric modeling of the space are detailed in Appendix A.

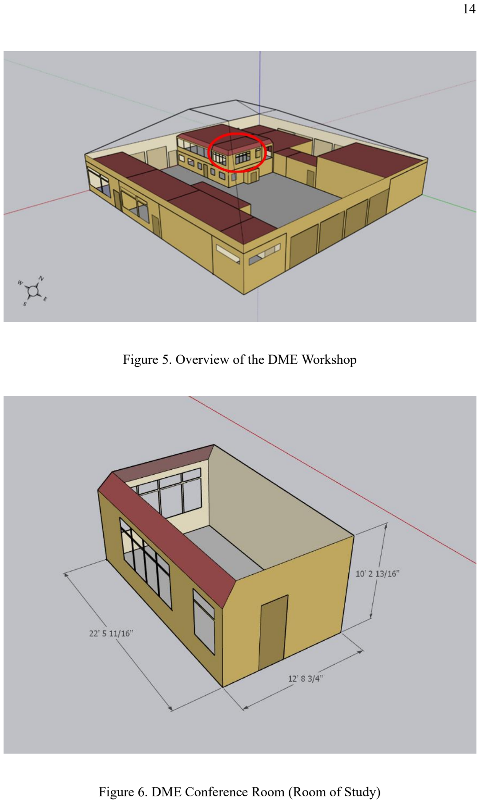
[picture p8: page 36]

14

Figure 5. Overview of the DME Workshop

Figure 6. DME Conference Room (Room of Study)

15

The DME Conference Room is situated within the Department of Mechanical

Engineering Workshop, as demarcated in Figure 1. Serving primarily as a dual-purpose

lecture and academic assembly facility, the zone's thermal environment is regulated by

two independent, wall-mounted split-type inverter air-conditioning units (ACUs): a

Samsung 1.5 HP (1 TR) unit and a General Royal 1.5 HP (1 TR) unit. Comprehensive

technical specifications and electrical profiles for these cooling assets are documented

in Appendix C.

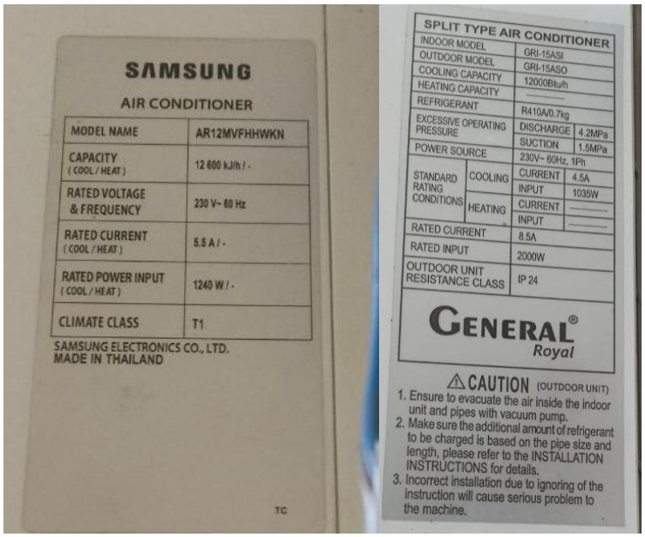
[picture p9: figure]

Figure 7. Air-conditioning Unit Specifications

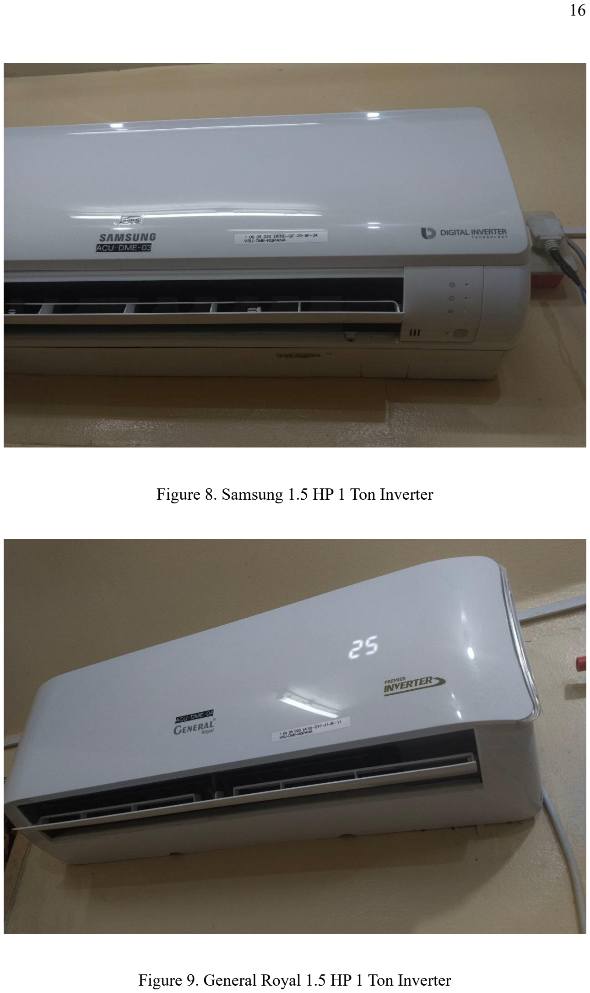
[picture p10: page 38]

16

Figure 8. Samsung 1.5 HP 1 Ton Inverter

Figure 9. General Royal 1.5 HP 1 Ton Inverter

CHAPTER 2

REVIEW OF RELATED LITERATURE

This chapter presents the body of literature and related studies relevant to

intelligent HVAC control, thermal comfort optimization, Digital Twin technology, and

distributed IoT-based automation systems. It establishes the theoretical and technical

foundations of the study by examining existing methodologies, frameworks, standards,

and research gaps that support the development of the proposed system.

Intelligent HVAC Control and Optimization Systems

The optimization of heating, ventilation, and air conditioning (HVAC) systems

has become an important research domain in response to the need for energy efficiency

and occupant comfort in modern buildings. Various approaches have been developed,

ranging from model-based control to machine learning and reinforcement learning

techniques. This section presents selected works relevant to the proposed study,

highlighting their methods, formulations, outcomes, contributions, recommendations,

and research gaps.

IoT-Based and Intelligent HVAC Control Systems

Carli et al. (2020) introduced an Internet of Things (IoT)-based architecture that

integrates Model Predictive Control (MPC) for HVAC systems in smart buildings.

Their method formulated HVAC optimization as a quadratic optimization problem,

where the objective function minimized both energy consumption and deviations from

the desired Predicted Mean Vote (PMV) comfort levels.

18

To address the nonlinearity of PMV, they applied linearized approximations,

enabling real-time computations. The architecture included a network of environmental

sensors, actuators, a control unit executing the MPC algorithm, and a user interface

connected through the Internet.

Outcomes showed that the system achieved significant energy savings while

maintaining thermal comfort, outperforming classical thermostat control. Their main

contribution lies in demonstrating that IoT integration makes advanced control

strategies feasible in real environments, not just simulations. They recommended

further work in scaling MPC for multi-zone buildings and incorporating renewable

energy integration. However, the gap remains in the computational intensity of MPC

and its dependence on accurate thermal models, limiting its application in resource-

constrained or smaller-scale settings.

Javed et al. (2017) proposed a smart controller for HVAC systems using

Random Neural Networks (RNNs) combined with wireless sensor networks (WSNs)

and cloud computing. Their formulation involved two neural models, with one

estimating the number of occupants and the other estimating the PMV-based comfort

setpoints

The models were trained using a hybrid Particle Swarm Optimization–

Sequential Quadratic Programming (PSO-SQP) algorithm, which optimized network

weights for better convergence. They compared three architectures: (1) cloud-only

computation, (2) base station-only processing, and (3) distributed computation between

nodes and base stations.

19

Results revealed that the distributed approach reduced power consumption by

4.4% compared to the cloud-only method and by 19.23% compared to base-station-

only processing. Their contribution lies in proving that intelligent controllers embedded

in local infrastructure can save energy while maintaining comfort. They recommended

designing future Building Energy Management Systems (BEMS) to distribute

intelligence across nodes for scalability and robustness.

Namatēvs (2018) explored HVAC optimization using Deep Reinforcement

Learning (DRL), combining Q-learning with deep neural networks (DNN). The HVAC

system was modeled as a Markov Decision Process (MDP), where the state space

included indoor and outdoor parameters (temperature, airflow, humidity, occupancy),

the action space represented control signals (heating or cooling intensity, airflow

levels), and the reward function balanced energy consumption against occupant comfort

indices such as PMV.

The DNN was trained to approximate the Q-function, allowing the agent to learn

optimal control policies through trial and error. Outcomes showed that DRL can

dynamically adapt to uncertain and nonlinear environments, offering potential for long-

term energy cost minimization.

The contribution of this study lies in presenting the DRL as an adaptive, model-

free method that avoids reliance on explicit thermal models. However, the research was

limited to simulations, and the computational requirements of the DRL remain a barrier

to real-time embedded implementation. Namatēvs recommended exploring hybrid

approaches that combine predictive models with reinforcement learning to reduce

computational overhead.

20

Trivedi et al. (2017) developed iSchedule, a campus-scale HVAC scheduling

system that leverages Wi-Fi connectivity logs as a proxy for occupancy detection. Their

method applied an ensemble gradient boosting regressor to learn occupancy patterns

for different zones and generate adaptive HVAC schedules.

The formulation used Wi-Fi association and dissociation events from thousands

of access points across 112 campus buildings, treating device counts as soft sensors for

occupancy. The outcomes indicated a 37% reduction in energy waste and a 3%

improvement in comfort levels compared to static scheduling. Their main contribution

is showing that existing infrastructure can be repurposed for scalable HVAC scheduling

without requiring additional hardware. They recommended applying such learning-

based schedules to other large-scale facilities with dense network infrastructures.

However, gaps exist in terms of granularity, as Wi-Fi cannot precisely track occupancy

counts or occupant comfort, and the approach is limited to institutions with pervasive

Wi-Fi coverage.

Fuzzy Logic-Based HVAC Optimization

A study by Abuhussain et al. (2023) proposed an adaptive HVAC system

employing a fuzzy controller approach, utilizing a Mamdani Fuzzy Inference System

with automatic rule generation to optimize energy consumption based on inputs such

as occupancy status, ambient temperature, humidity, and real-time electricity tariffs.

Simulations conducted via EnergyPlus software, incorporating local weather data from

Saudi Arabia and evaluated through the Fanger thermal comfort model, demonstrated

up to 50% energy savings compared to the baseline IoFClime system when prioritizing

21

energy over comfort, with the controller maintaining satisfactory predicted mean vote

(PMV) ranges across varying scenarios.

The authors discussed the limitations of traditional inputs like ambient

temperature and humidity for precise comfort management, emphasizing the benefits

of occupancy-based controls and demand response for handling thermal inertia, though

the approach relies on simulation-only validation and a narrow input set, potentially

overlooking real-world sensor inaccuracies and broader parameters such as CO2 levels.

Complementing this fuzzy logic emphasis, Acquaah et al. (2020) explore

occupancy detection for smart HVAC efficiency using a deep learning neural network

framework with thermal imagery, comparing a pre-trained ResNet-50 model for feature

extraction combined with multi-class Support Vector Machine classification against a

pre-trained AlexNet with transfer learning.

Data acquisition involved thermal cameras and sensors in a laboratory setup,

achieving accuracies of approximately 96% for ResNet-50 + SVM and over 98% for

AlexNet, with the latter performing better on larger datasets despite increased

computational time. The discussion highlights the privacy advantages of thermal

imaging over RGB cameras and its potential to reduce HVAC energy loads by

conditioning occupied zones only, outperforming prior methods like ThermoSense, yet

the study is limited to small-scale detection (up to three occupants) without full HVAC

integration or energy quantification, restricting its applicability to dynamic, multi-room

environments.

22

Further advancing fuzzy-based alternatives to conventional controls, Chojecki

et al. (2023) advocate replacing proportional-integral-derivative (PID) controllers in air

handling units with fuzzy logic controllers structured to mimic PID functions without

requiring tuning, validated through Simulink simulations using real building data and

implemented on a custom hardware control board. The fuzzy controller improved

integral control quality indicators by at least 27.4%, reduced supply air temperature

variations, and achieved 12.7% energy savings compared to untuned PIDs, with

discussions underscoring the prevalence of sub-optimal PID tuning in over 50% of

installations leading to oscillations and waste. However, the method neglects advanced

inputs like occupancy or PMV, focusing solely on temperature, and assumes no initial

fuzzy rule adjustments, which may limit its plug-and-play feasibility in diverse building

contexts.

PMV and Thermal Comfort-Oriented HVAC Control

In a practical experimental context, Kim et al. (2020) introduced an optimal

control method for HVAC systems in offices using algorithms based on thermal

environment factors, regulating temperature and humidity ranges (18-21°C and 40-60%

RH) alongside PMV control (-0.5 to +0.5) in a real South Korean office setting over

three days.

Surveys indicated enhanced occupant comfort and productivity, with PMV

control effectively addressing temperature-humidity coupling and energy regulations,

though energy savings were implied rather than precisely quantified. The authors

emphasize balancing energy conservation with comfort to mitigate productivity losses

23

(thermal environment impacting 44.1% of efficiency), but the single-case, short-

duration experiment is vulnerable to weather dependencies and lacks automated sensors

for real-time PMV, highlighting a need for broader scalability.

Addressing more complex system dynamics, Homod (2018) presents a

feedforward hybrid layers control for HVAC optimization in smart buildings,

hybridizing Takagi-Sugeno-Kang fuzzy inference with neural networks trained offline

via Gauss-Newton regression and tuned online with gradient descent, controlling five

parameters (valves, dampers, and fan speed) in variable water and air volume systems

while leveraging PMV sensors to handle nonlinearity, inertia, and coupling. Compared

to hybrid PID-cascade benchmarks, the approach yielded superior precision,

disturbance rejection, and over 30% energy savings versus on/off controls, with

discussions noting its ability to decouple temperature and humidity without additional

hardware. Nonetheless, the simulation-based validation assumes PMV sensor

availability, overlooks occupancy integration, and may be computationally intensive

for legacy systems, underscoring opportunities for hardware simplification.

Data-Driven and Machine Learning-Based Optimization

Building on black-box optimization techniques, Lin et al. (2023) propose a

Bayesian optimization framework for HVAC system control, modeling the problem as

a contextual optimization task with Gaussian process regression as the surrogate model

for energy efficiency (negative total power) and employing an upper confidence bound

acquisition function enhanced with noise-based exploration and dual constraint

handling (feedforward optimization via genetic algorithms and feedback correction).

24

The framework automates sample construction from time series trending data,

excluding transition periods through algorithmic identification, and was evaluated on a

simulated data center system calibrated with real data, achieving over 10% energy

savings within weeks compared to baseline building automation controls.

The discussions emphasized on the efficiency and stability of the framework for

large-scale deployment, surpassing data-intensive methods like model predictive

control and reinforcement learning in practical applications, although it relies on

quasistatic setpoints for near-optimal rather than fully dynamic performance, with

manual feedback rules and simulation-based validation potentially limiting

generalization to diverse HVAC systems.

The study by Manjarres et al. (2017) aimed to automate energy-efficient HVAC

strategies in tertiary buildings through the Next24h-Energy framework, targeting a

reduction in HVAC energy consumption, which typically accounts for 30-50% of

building energy use, while maintaining indoor temperature margins for user comfort.

Their methodology involved Random Forest regression for predictive modeling of

indoor and outdoor conditions, enabling daily adaptive optimization of HVAC ON/OFF

schedules and mechanical ventilation to address dynamic variability in occupancy and

environmental factors, utilizing a black-box approach that decreases computational

complexity and engineering knowledge requirements compared to physical or grey-box

models.

The framework included integration with Building Energy Management

Systems (BEMS) for two-way communication, a dedicated database for storing sensor

data on temperature, humidity, and occupancy, and simulation software likely based on

25

MATLAB or Simulink, validated using real sensors deployed in the Mikeletegi 1 office

building in Donostia-San Sebastian, Spain. The results demonstrated substantial

savings of 48% in heating energy and 39% in cooling energy over the test period, with

no compromise to comfort as indoor temperatures remained consistently within

predefined margins.

The discussions emphasized the superiority of Random Forest in handling

nonlinear dynamics over static physical or grey-box models, reducing reliance on

human intervention through automated daily parameter adaptation and facilitating

generalization across varying building conditions.

The authors concluded that this framework offers a practical solution for

bridging the gap between sensor infrastructures and facility management actions,

yielding median energy savings of 15% from building commissioning.

Recommendations include extending the approach to incorporate additional

environmental variables and testing in diverse climatic zones to enhance robustness.

However, gaps in their study are notable, including the absence of Predictive Mean Vote

(PMV) integration for a more comprehensive thermal comfort assessment beyond

simple temperature margins, which overlooks factors like humidity, air velocity, and

metabolic rates; a heavy reliance on simulations that limits empirical validation in

varied real-world scenarios, potentially underestimating practical implementation

challenges such as sensor inaccuracies or network delays; assumptions of detailed

building structural knowledge, which restrict scalability to buildings without extensive

prior data and may not account for retrofitting older structures; and a lack of cost-

26

benefit analysis for hardware deployment, ignoring economic feasibility in resource-

constrained environments.

Ait Tchakoucht et al. (2024) focused on predicting electrical and thermal

efficiencies in air-based photovoltaic-thermal (PV/T) systems to optimize energy

performance and reduce dependency on traditional HVAC components, emphasizing

the simultaneous generation of electricity and heat for cost-effective and

environmentally friendly solar energy solutions.

Their method employed Random Forest with feature selection, such as

temperature and humidity, combined with 10-fold cross-validation to model nonlinear

thermal exchanges, facilitating pre-cooling strategies for HVAC integration through an

automatic fuzzy rule generation method that simplifies inference system design.

The tools include EnergyPlus for conducting simulations based on local weather

data, Python with Scikit-learn libraries for implementing Random Forest and cross-

validation processes, and implicit basic sensors for integrating weather data like

ambient temperature and solar irradiance.

The results yield exceptional accuracy with R-squared values of 99.9996% for

electrical efficiency and 81.2% for thermal efficiency, alongside a mean absolute error

of 0.0034 for electrical and 2.64 for thermal predictions, and a 50% reduction in

processing time through feature selection.

The discussions highlight the outperformance of Random Forest over artificial

neural networks, support vector machines, and linear regression in predictive accuracy

and stability, enabling scalable solutions with potential 50% energy savings when

27

comfort is not prioritized, though the focus remains PV/T-specific and demonstrates

robust generalization across validation folds.

The authors concluded that this approach serves as a viable alternative to

traditional physical modeling for electrical and thermal performance estimation,

offering impressive metrics that underscore its utility in renewable energy systems.

Recommendations involve exploring hybrid models with additional machine

learning techniques and validating in real-world PV/T installations to bridge

simulation-reality gaps.

The limitations encompass the lack of direct HVAC control mechanisms, as the

predictions do not extend to real-time system adjustments like setpoint modulation;

exclusive reliance on simulations without incorporation of physical sensors, which may

overlook practical issues such as sensor drift or environmental noise; high data

requirements for effective cross-validation, potentially straining computational

resources and limiting applicability in scenarios with sparse datasets; and a narrow

PV/T focus that neglects broader HVAC integration, such as occupancy-driven

adaptations or PMV-based comfort evaluations, thereby restricting its relevance to full

building energy management.

Razzano et al. (2025) sought to optimize centralized Air Handling Units (AHU)

in multi-zone buildings for energy efficiency and indoor temperature control by

leveraging deep reinforcement learning (DRL) and rule extraction techniques,

addressing the substantial energy demand of HVAC systems while ensuring occupant

comfort and health.

28

The methodology involved DRL for learning multi-action policies, such as

adjusting supply water temperature, chiller valve positions, and economizer dampers,

followed by decision tree-based rule extraction using regression trees for

interpretability, compared against ASHRAE 2006 and Guideline 36 standards via high-

fidelity co-simulation that models building envelope, loads, and HVAC components.

The tools comprised Spawn of EnergyPlus integrated with Modelica for

equation-based dynamic modeling, Python libraries like Stable Baselines for DRL

implementation, and virtual sensors for real-time data on occupancy, thermal loads, and

environmental conditions.

The results indicated that the extracted rules achieve only 3% higher energy

consumption than pure DRL but surpass ASHRAE sequences in reducing chiller and

fan energy while minimizing temperature violations, with the co-simulation validating

the framework's ability to approximate DRL policies effectively.

The discussions underscored the transparency of rule extraction in making

complex DRL decision-making actionable for building automation systems, with a

mechanical emphasis on Variable Air Volume (VAV) efficiency in multi-zone setups

and the potential for integrating AI-driven methods with interpretable rules to facilitate

adoption in real-world scenarios.

The authors concluded that this hybrid approach bridges the gap between

advanced control technologies and practical implementation, demonstrating superior

energy management over conventional rule-based systems.

29

The recommendations included extending the framework to incorporate real-

time occupant feedback and testing in physical buildings to validate simulation

assumptions.

The gaps included high computational demands for DRL training and execution,

which require significant processing power and specialized programming expertise,

making it inaccessible for low-resource applications; simulation exclusivity without

hardware validation, potentially failing to account for real-world variabilities like

sensor inaccuracies, equipment wear, or unforeseen environmental disturbances;

omission of occupant behavior inference, such as activity levels or preferences, which

limits the model's ability to adapt to dynamic human factors beyond basic occupancy;

and a lack of economic analysis, including implementation costs and payback periods,

overlooking feasibility in budget-constrained contexts.

Xu et al. (2024) aimed to predict daily heating energy consumption in residential

buildings to enhance efficiency through a hybrid Random Forest model optimized by

meta-heuristic algorithms, addressing key variables like architectural characteristics,

occupancy, and ambient temperature.

The approach integrated Random Forest with optimizers like the Arithmetic

Optimization Algorithm (AOA) and Ant Lion Optimizer (ALO) for hyperparameter

tuning, employing K-fold cross-validation on features such as building envelope

properties, occupant density, and external weather conditions to ensure model

robustness and prevent overfitting.

30

The tools involved were Python with Scikit-learn for Random Forest

implementation and optimizer libraries for meta-heuristics, alongside simulated

datasets implying standard sensors for temperature, occupancy, and energy monitoring.

Results show superior performance with an R-squared of 0.977, root mean squared

error of 0.118, mean absolute error of 0.057, and AOA-RF as the optimal variant,

demonstrating convergence after 101 iterations for ALO with a Theil Inequality

Coefficient of 0.015.

The discussions noted the superiority of the hybrid over the standalone models,

like artificial neural networks or support vector machines, mechanically enabling

reductions in over-heating by 15-25% through accurate load forecasts that inform

heating system operations.

The authors concluded that the hybrid framework provides a robust tool for

energy consumption modeling, outperforming traditional methods in accuracy and

generalization. Recommendations included applying the model to commercial

buildings and incorporating real-time data streams for enhanced predictive capabilities.

The limitations included a prediction-only focus without a closed-loop control

mechanism, restricting its utility to forecasting rather than active system modulation;

residential specificity that does not extend to office or multi-zone environments,

potentially overlooking complexities like varying occupancy patterns; computational

intensity for meta-heuristics, which demands significant processing time and expertise,

posing challenges for real-time applications; and reliance on simulated datasets without

physical sensor validation, which may not capture nuances like sensor noise or

environmental interferences.

31

Personalized Thermal Comfort and Occupant-Centric Approaches

Qi et al. (2023) investigated factors influencing thermal sensation vote (TSV)

to develop a personalized regression model for HVAC setpoint optimization, using local

skin temperature as a key indicator in moderate summer conditions.

The methodology correlated ambient temperature, multiple local skin

temperatures (with emphasis on the forehead due to its strong correlation with TSV and

ease of measurement), and subjective TSV from a survey of 40 subjects aged 20-59,

incorporating individual characteristics like body fat percentage and setpoints to

compensate for personal differences.

The tools included were infrared skin temperature sensors for non-contact

measurements, survey instruments for collecting TSV data, and analytical software like

Python or MATLAB for regression modeling and correlation analysis.

The results revealed a root mean squared error 15.8%, lower than support vector

regression and comparative models by Zhang and Zhou, with the lowest mean absolute

error, demonstrating the ability of the model to capture individual variations.

The discussions affirmed the forehead temperature's strong correlation for non-

intrusive prediction, mechanically supporting adaptive cooling strategies that could

yield 10-20% energy savings by fine-tuning setpoints without compromising

satisfaction.

The authors concluded that this approach offers a practical, scalable solution for

international ergonomic standards, outperforming existing models in accuracy and

32

minimal input requirements. Recommendations involved expanding the study to

diverse climatic conditions and larger sample sizes for broader applicability.

The gaps comprised applicability limited to moderate summer conditions,

failing to address extreme climates or seasonal variations that could alter skin

temperature correlations; neglect of dynamic occupancy factors, such as real-time

changes in occupant numbers or activities, which influence overall thermal loads;

reliance on potentially intrusive surveys for initial data collection, which may introduce

bias or limit real-time deployment; a small sample size of 40 subjects, reducing

generalizability across demographics like age or gender; and absence of energy

consumption metrics, overlooking the direct link between comfort predictions and

HVAC operational efficiency.

Ermis et al. (2025) developed a practical personalized thermal comfort model

by minimizing hard-to-measure features through meta-learning and feature importance

analysis, addressing challenges in traditional models like Predicted Mean Vote that

require complex inputs such as metabolic rate and clothing insulation.

The method used model-agnostic meta-learning (MAML) with a novel

importance technique that outperforms SHAP in handling feature correlations,

leveraging ensembles like Random Forest and support vector machines on minimal

thermal sensation votes pretrained on subsets of the ASHRAE RP-884 database. Tools

encompass Python with SHAP and meta-learning libraries for analysis, and basic

environmental sensors for collecting temperature and humidity data in daily life

environments.

33

The results exhibited higher prediction accuracy than non-personalized general

models, effectively substituting complex personal factors with thermal sensation votes

and providing robust insights into feature importance.

The discussions emphasized reduced measurement complexity for adaptive

HVAC predictions, potentially yielding 10-15% energy savings via personalization

while leveraging techniques like transfer learning to improve efficiency with limited

data. The authors conclude that this methodology offers a parsimonious framework for

thermal comfort modeling, outperforming aggregate models in real-world scenarios.

Recommendations included further exploration of ensemble methods and integration

with additional datasets for enhanced personalization.

Limitations include dependence on user-provided thermal sensation votes,

which can be time-consuming and intrusive, potentially limiting scalability in

automated systems; absence of direct energy integration, focusing solely on comfort

prediction without linking to HVAC consumption metrics; handling of feature

correlations that, while improved, may still overlook interdependent variables in highly

variable environments; reliance on limited personal data, which could introduce bias in

underrepresented demographics; and a lack of validation in extreme conditions,

restricting applicability beyond controlled settings.

Woo et al. (2025) proposed an occupant-centric HVAC control using multi-

modal infrared array sensing for real-time occupancy, counting, and operative

temperature detection in open offices, aiming to enhance energy efficiency while

considering adaptive comfort.

34

The methodology integrated convolutional neural networks for processing

infrared data with two-position control strategies, simulated to evaluate energy-comfort

trade-offs and incorporating multiple heat transfer mechanisms for accuracy.

The tools included infrared arrays with 110-degree vision angles for multi-

modal functionality, EnergyPlus for modeling a 100-square-meter office space using

2023 Michigan weather data, and Python with Keras or TensorFlow libraries for neural

network implementation.

The results indicated 33.7% heating energy savings compared to baseline

controls, an 8.1-year payback period for the infrared sensor, and 95% detection

accuracy, though with a 13.6% adaptive comfort penalized percentage during heating

seasons.

The discussions highlighted the multi-modal robustness for reducing fan and

chiller loads, emphasizing the trade-off between energy efficiency and comfort, and the

potential of edge computing for real-time deployment.

The authors concluded that this framework advances intelligent HVAC systems,

outperforming presence-based controls in energy performance. The recommendations

involved real-world deployments and integration of dynamic occupant behavior to

refine the approach.

The gaps involved inherent comfort trade-offs, where energy savings

compromise thermal satisfaction, potentially unsuitable for high-occupancy spaces;

simulation limitations that may not capture real-world variabilities like sensor

degradation or environmental interferences; lack of behavior inference beyond basic

35

counting, ignoring activity levels that affect metabolic rates and loads; high initial

sensor costs without detailed economic breakdowns for varying building scales; and

focus on open offices, limiting generalizability to enclosed or residential settings.

Moreover, Challa et al. (2025) introduced a multi-modal system for real-time

classroom occupancy detection to enhance HVAC efficiency, combining video analysis

and gas sensors to provide precise data for dynamic control.

The method utilized YOLOv4 for face detection and counting from video feeds,

fused with MS1100 gas sensor data for robustness in low-visibility or obstructed

conditions, trained on a dataset of over 20,000 labeled human face images.

The tools comprised a Logitech C20 webcam for video capture, the MS1100

module for CO₂ and volatile organic compound sensing, OpenCV for stream

processing, and integration frameworks for seamless HVAC optimization.

Th results achieved over 98% accuracy in occupancy detection, demonstrating

significant potential for reducing energy consumption through scalable building

management.

The discussions highlighted the reliability of the fusion in addressing

environmental challenges, offering a practical solution for smart buildings with

enhanced responsiveness.

The authors concluded that the dual-modal approach provided a robust

framework for energy-efficient infrastructure. The recommendations included scaling

to diverse building types and incorporating additional modalities for further reliability.

36

The limitations included specificity to classroom environments, which may not

translate to offices or varying layouts; omission of PMV or occupant behavior

assessments, focusing solely on count without activity or comfort metrics; unaddressed

hardware costs and deployment feasibility, potentially overlooking budget constraints;

reliance on large labeled datasets, which could be resource-intensive to acquire; and

lack of real-world energy savings quantification beyond potential estimates.

Amiri et al. (2025), as a review, synthesized occupancy detection techniques for

HVAC control from over 190 studies between 2017 and 2024, categorizing methods as

direct, indirect, and fusion-based while analyzing machine learning roles in real-time

estimation. Notable studies include Kong et al. (2018) on CO₂-motion fusion achieving

20% office energy savings through sensor integration and Dong et al. (2019) on

convolutional neural networks for 18% counting accuracy in building simulations.

The discussions emphasized the multimodal fusion's prominence for 95%

accuracy and edge computing's potential, concluding that these advances enable

resource-efficient HVAC but highlighted gaps in the standardized benchmarks and real-

world data utilization.

The recommendations involved developing privacy-preserving frameworks and

integrating occupant behavior for validation. The gaps across reviewed studies include

dataset scarcity and bias, limiting model generalization; privacy concerns in camera-

based methods without adequate edge processing; high costs and suboptimal sensor

placement affecting accuracy by up to 20%; algorithmic adaptability issues in varying

buildings; and underutilization of real deployments, often relying on simulations that

overlook practical challenges like data resolution and preprocessing needs.

37

Multi-Objective Optimization and Digital Twin Applications

Latifah et al. (2025) presented a multi-objective genetic algorithm within a

digital twin model to balance thermal comfort and energy efficiency in shared

workspaces, addressing the trade-off between occupant well-being and HVAC

operational costs.

The methodology enhanced genetic algorithms with artificial neural network

surrogates for surrogate-assisted optimization, focusing on real-time setpoint

adjustments and benchmarked against NSGA-II and multi-objective particle swarm

optimization using ASHRAE 55 standards for comfort (20-24°C, 30-60% humidity).

The tools involved were the EnergyPlus integrated with Python for simulations,

feedforward neural networks trained with Adam optimizers on sensor data for

temperature, humidity, and occupancy, and IoT sensors for real-time inputs.

The results showed a 25% reduction in HVAC energy consumption and 78%

occupant comfort satisfaction, outperforming NSGA-II (22% savings, 75% comfort)

and MOPSO (20% savings, 74% comfort) by 3-5%.

The discussions highlighted the Digital Twin's role in predictive mechanical

control for fan speeds, damper positions, and airflow optimization, concluding that this

framework provides actionable insights for building engineers in energy management.

The recommendations included real-world deployments, integration of dynamic

occupant behavior, and generalization across climatic conditions for future validation.

The gaps comprised simulation exclusivity without physical building tests, potentially

38

missing real-world discrepancies like equipment inefficiencies or sensor failures;

neglect of diverse climates, limiting applicability beyond moderate conditions;

omission of occupant behavior details, such as activity variations that influence thermal

loads; high computational demands for genetic algorithms, requiring substantial

resources for population iterations; and lack of cost analyses or scalability assessments

for different building types.

Collectively, these studies underscore the shift toward fuzzy logic, PMV-based

strategies, and deep learning for HVAC optimization, achieving energy reductions of

12-50% through enhanced comfort management, yet common gaps include simulation-

dominant validations, limited input scopes (e.g., excluding multi-modal data like CO2

or weather forecasts), and insufficient quantification of health or productivity impacts.

For the present thesis, integrating deep learning occupancy detection from

Acquaah et al. (2020) as dynamic inputs to fuzzy/PMV controllers from Abuhussain et

al. (2023), Chojecki et al. (2023), and Kim et al. (2020), while adopting the hybrid

fuzzy-neural structure of Homod (2018) for nonlinearity and the efficient Bayesian

framework of Lin et al. (2023) for handling uncertainties, could yield a more robust

framework. Improvements may involve multi-zone real-world testing, adaptive online

learning for uncertainties, and comprehensive metrics encompassing energy, comfort,

and occupant well-being, potentially realizing 20-40% additional savings in variable-

load buildings.

39

The Role of BEM in Digital Twin Architecture

The decarbonization of the built environment has accelerated the need for

sophisticated predictive modeling to optimize facility operations as shown in Figure 10.

While traditional Building Energy Modeling (BEM) has been extensively utilized

during the design phase to forecast thermal dynamics, an acknowledged performance

gap routinely emerges between "as-designed" simulations and "as-operated" energy

consumption.

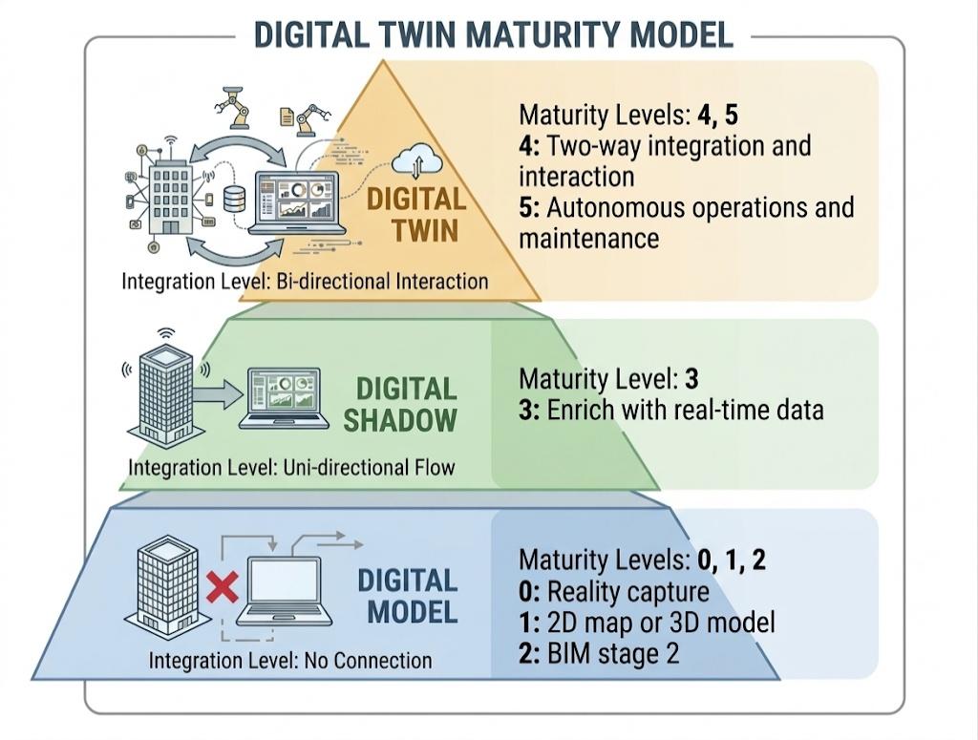
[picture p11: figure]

Figure 10. Digital Twin Maturity Model

To reconcile this operational discrepancy, the transition toward BEM Digital

Twins (DT) has become a focal point in contemporary energy research. By establishing

a bidirectional data flow between physical assets and virtual models, BEM DTs

facilitate real-time monitoring, model predictive control, and dynamic energy

optimization.

40

This review explores the paradigm shift from static modeling to real-time

integration, examines edge-computing architectures, and emphasizes the critical

programmatic validation protocols necessary to ensure the predictive robustness of

these digital environments.

The development of a BEM-based Digital Twin represents a transformative

approach to architectural and systems engineering. By utilizing simulation engines such

as EnergyPlus, IESVE, or eQUEST, stakeholders can generate high-fidelity virtual

models that account for complex geometric and thermodynamic variables. Alpin (2026)

emphasizes that the core strength of BEM lies in its ability to mitigate the "performance

gap" by anticipating energy demands, carbon footprints, and peak loads before a facility

is physically realized. This digital representation serves as a controlled environment

where designers can iterate through various building envelope configurations and

HVAC strategies, thereby identifying energy waste at the design stage rather than

through costly retrospective interventions.

Constructing a precise digital twin requires a multi-stage integration of

architectural and environmental data. Current literature outlines a rigorous

methodological sequence: importing CAD-based geometries into the simulation

environment, defining climate-specific boundary conditions, and inputting granular

material and system properties. Crucially, the validity of these modeling rests on the

comparison of simulated outputs against historical performance benchmarks.

Discrepancies between the virtual model and the actual building performance

necessitate systematic adjustments to the internal variables of the model, such as

internal heat gains and occupancy-dependent schedules. This cyclical process of

41

simulation and calibration is essential for ensuring that the digital twin functions as an

accurate, predictive representation of the physical asset.

Edge-Hosted Digital Twins

Historically, BEM has operated under static, schedule-based assumptions

regarding occupancy, microclimates, and boundary conditions. This inherent rigidity

renders traditional models highly susceptible to performance drift as physical building

usage diverges from design-phase estimates.

The integration of Internet of Things (IoT) sensors enables the continuous

streaming of operational data such as temperature, CO2 concentrations, and spatial

occupancy into virtual replicas. Sayed et al. (2025) demonstrate that deploying a DT

framework dynamically adapts to environmental changes and occupancy patterns,

effectively shifting energy management from reactive to proactive see in Figure 10.

Notably, the authors addressed significant limitations in conventional cloud-

dependent DTs by deploying the virtual replica on edge devices using user-centric

platforms like Home-Assistant. This edge implementation significantly reduces latency,

secures data privacy through localized processing, and maintains the continuous

synchronization necessary to support high-fidelity, real-time energy efficiency

recommendations.

Machine Learning and Data-Driven Optimization

A central component of the recent BEM DT architectures is the integration of

Machine Learning (ML) to process stochastic operational inputs. Accurate modeling of

42

building thermodynamics requires precise knowledge of internal heat gains, which are

profoundly influenced by occupant behavior.

Sayed et al. (2025) utilized ML algorithms to develop a data-driven occupancy

detection mechanism, achieving a testing accuracy of 95.12%. This deterministic

understanding of spatial utilization allows the DT to systematically optimize energy-

intensive systems, such as HVAC and lighting, strictly based on real-time usage patterns

rather than hypothetical schedules. While data-driven models demonstrate high efficacy

in empirical interpolation, the literature indicates that pure black-box models frequently

lack fundamental thermodynamic interpretability and struggle to generalize when

exposed to unseen operational states outside of their initial training datasets.

Consequently, integrating these dynamic inputs into physics-based BEM engines

remains a critical requirement for scalable reliability.

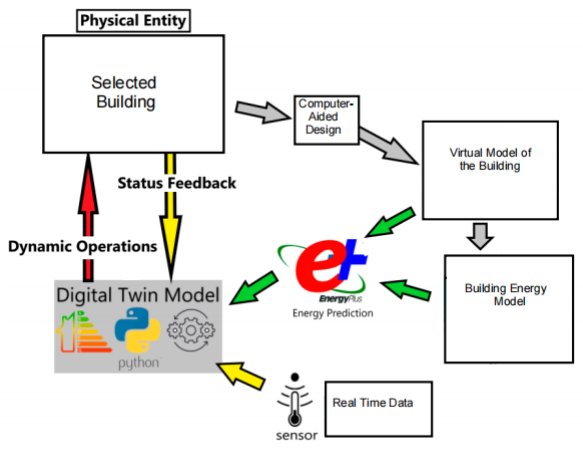
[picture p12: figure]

Figure 11. Real-time IoT Telemetry and Physics-Based BEM Engines

The successful convergence of real-time IoT telemetry and physics-based BEM

engines hinges upon sophisticated, automated interoperability as shown in Figure 11.

43

Manually updating complex simulation input files to reflect shifting operational states

is computationally prohibitive. Consequently, the development of automated

programmatic workflows constitutes a significant methodological advancement in the

field. Utilizing scripting libraries, such as Python's eppy, enables researchers to

programmatically parse and manipulate complex thermodynamic simulation objects.

This programmatic approach allows a script to systematically overwrite initial training

boundary conditions with newly aggregated, dynamic schedules as shown in Figure 12.

By circumventing manual data entry, these environments enable the high-frequency

execution of building physics simulations required to maintain genuine parity between

the physical asset and its digital twin.

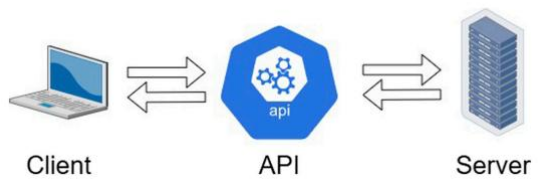
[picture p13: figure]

Figure 12. EnergyPlus Application Programming Interface (API)

Implementing Digital Twin to Quantify Energy Consumption

Guerrero Ramírez et al. (2025) developed a Digital Twin framework based on

calibrated white-box Building Energy Models to reproduce the thermal behavior of a

real building.

The Digital Twin was calibrated using measured indoor environmental

conditions and demonstrated the capability of representing the thermal response of the

building under operational conditions. Through calibration and validation procedures,

44

the study showed that Digital Twins can provide reliable representations of physical

buildings and can support building operation and control strategies through continuous

comparison between simulated and measured data.

A significant contribution of the study is the distinction made between thermal

behavior calibration and energy consumption quantification. Although the developed

Digital Twin successfully reproduced indoor thermal conditions using calibrated

Building Energy Models and Ideal Air Loads systems, the authors acknowledged that

HVAC system calibration was not incorporated into the modeling framework.

Consequently, the study identified HVAC calibration and accurate energy consumption

quantification as a critical direction for future research. The authors specifically stated

that future work should focus on extending the calibrated models to accurately quantify

energy consumption, emphasizing that this step is essential for achieving whole-system

optimization and unlocking the full operational energy management capabilities of

Digital Twins.

This observation highlights an important consideration in Digital Twin

development. A model may successfully reproduce indoor environmental conditions

while still requiring additional HVAC-specific calibration to accurately represent

energy use. Therefore, the ability of a Digital Twin to predict thermal conditions should

not automatically be interpreted as evidence of accurate energy quantification. Instead,

dedicated calibration of HVAC-related parameters is necessary when energy

consumption becomes the primary performance variable.

The distinction identified by Guerrero Ramírez et al. (2025) reinforces the

importance of aligning calibration objectives with the intended application of the

45

Digital Twin, particularly when the objective extends beyond thermal behavior

representation toward operational energy assessment and management.

Open-Source Building Energy Modeling

Open-source Building Energy Modeling (BEM) platforms have become

essential tools for analyzing building energy performance, thermal behavior, and HVAC

system operation. These tools provide researchers and engineers with accessible and

flexible environments for developing virtual building models and evaluating energy

efficiency strategies. Among the most widely used open-source platforms are

OpenStudio and EnergyPlus, which enable detailed simulation of building systems and

support advanced applications such as optimization and digital twin development.

Therefore, the following sections discuss their fundamental concepts, methodologies,

and roles in modern building energy analysis.

OpenStudio Software

The evolution of the built environment toward achieving net-zero energy

consumption relies heavily on the capacity to accurately simulate and predict building

thermal dynamics.

Before the advent of dynamic Building Energy Modeling (BEM) Digital Twins,

the industry required accessible, high-fidelity spatial and thermodynamic modeling

platforms to establish the virtual geometry of physical assets. The integration of 3D

modeling interfaces with advanced simulation engines, such as the coupling of CAD

software with the U.S. Department of Energy’s EnergyPlus via OpenStudio, marked a

46

pivotal democratization of these capabilities as shown in Figure 13. This review

analyzes the foundational methodology of static BEM design, discusses the inherent

limitations of graphical-interface modeling in a continuous-operation context, and

conceptually bridges these early simulation frameworks to the programmatic,

automated architectures required for modern BEM Digital Twins.

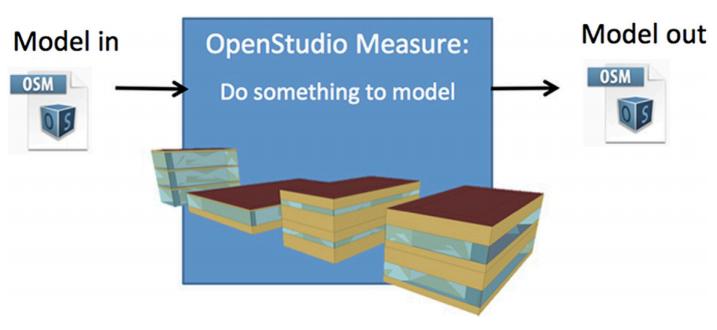
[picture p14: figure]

Figure 13. OpenStudio Software

OpenStudio Plugin

The accurate representation of the physical and thermodynamic properties of

the building is the mandatory first step in constructing any virtual replica.

Al-Zubaydi (2013) detailed a comprehensive methodological workflow for

conceptualizing energy-efficient buildings using the OpenStudio plug-in within CAD

software as shown in Figure 14. This approach facilitates the creation of a building's

spatial geometry by sequentially defining core and perimeter thermal zones,

establishing surface matching for heat transfer calculations, and configuring critical

47

architectural elements such as the Window-to-Wall Ratio (WWR) and exterior

fenestrations. By assigning specific material properties (e.g., U-factors, Solar Heat Gain

Coefficients) and occupancy schedules based on established benchmarks like ASHRAE

Standard 90.1, engineers can execute EnergyPlus simulations to estimate HVAC loads

and overall consumption. This methodology effectively translates physical structural

intentions into a computable mathematical model, establishing the static baseline

necessary for subsequent digital twin integration.

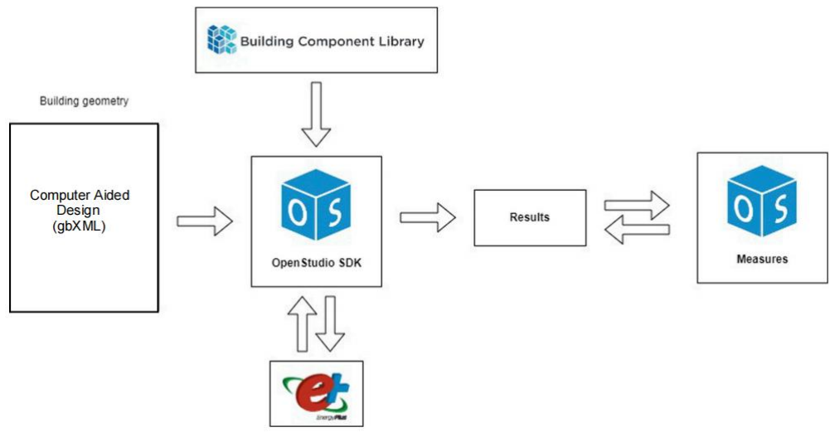
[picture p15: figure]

Figure 14. Building Energy Modeling (BEM) Digital Twin

While graphical user interfaces (GUIs) like SketchUp and OpenStudio are

instrumental during the architectural design phase, the literature highlights their

operational limitations when transitioning toward BEM Digital Twins. Al-Zubaydi

(2013) illustrates a predominantly manual process: adjusting glazing properties,

inserting overhangs, and configuring thermal zones require direct user interaction

within the software's inspector windows. In a true Digital Twin ecosystem, which

48

demands the continuous ingestion of real-time Internet of Things (IoT) telemetry and

stochastic environmental data, relying on manual GUI interventions is computationally

unscalable and methodologically flawed. Static models inherently assume idealized

schedules that quickly diverge from actual building utilization, resulting in a

pronounced performance gap between simulated estimates and empirical energy usage.

EnergyPlus Engine

In the domain of whole-building energy simulation (WBES), the precision of

virtual models is intrinsically tied to the underlying computational engine. EnergyPlus,

developed by the United States Department of Energy (DOE), has established itself as

the preeminent open-source simulation program for modeling building heating,

cooling, lighting, ventilation, and other energy flows. Designed to replace legacy

programs such as DOE-2 and BLAST, EnergyPlus integrates advanced thermodynamic

algorithms to provide sub-hourly, high-fidelity energy analysis. This review focuses

exclusively on the architectural and computational framework of EnergyPlus,

examining its core heat balance methodology, its text-based interoperability, its inherent

limitations in dynamic operational contexts, and its critical role in advanced predictive

modeling and digital twin research.
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

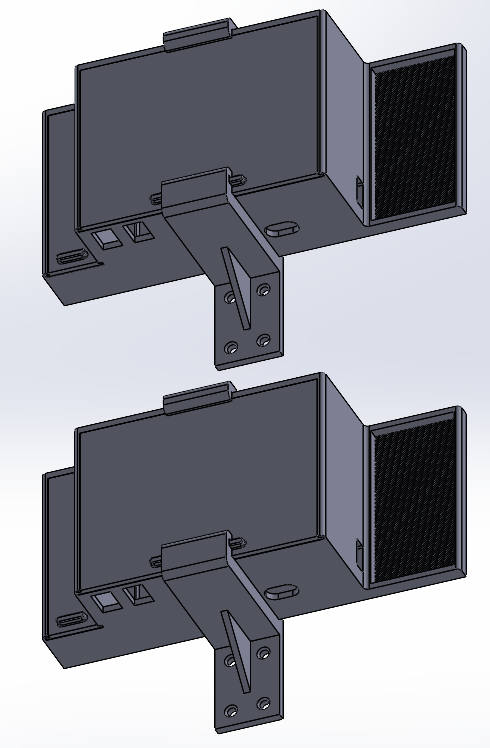
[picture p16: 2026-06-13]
Hardware System Files/Enclosures/ESP Platforms/ESP 4 and ESP 5 Platform Orientations.png

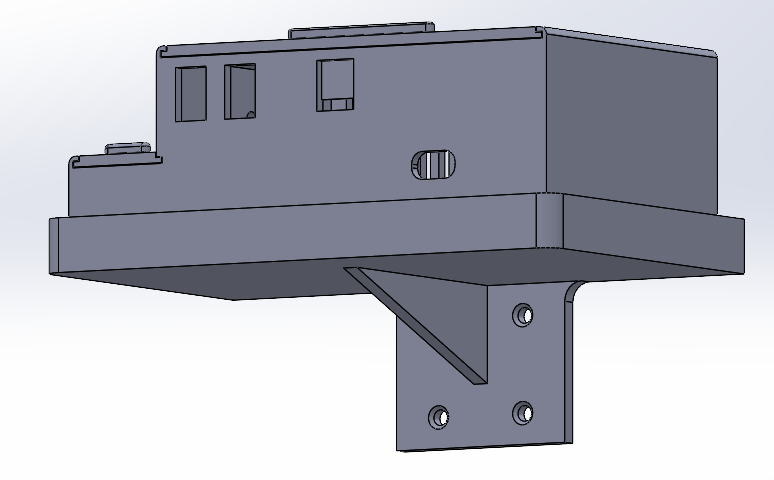
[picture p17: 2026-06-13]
Hardware System Files/Enclosures/ESP Platforms/ESP 3 Platform Orientation.png

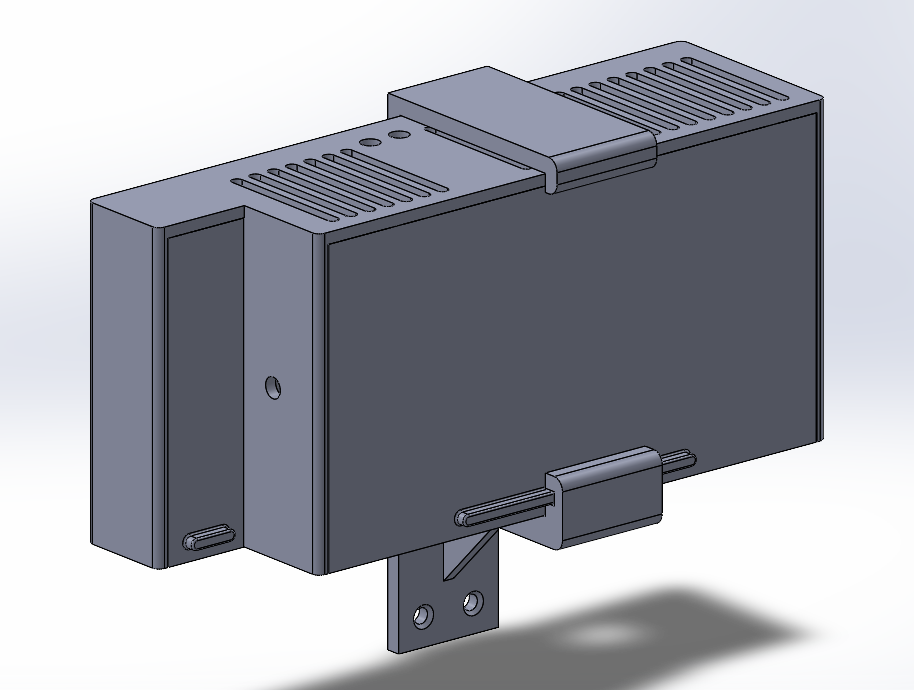
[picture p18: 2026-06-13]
Hardware System Files/Enclosures/ESP Platforms/ESP 2 Platform Orientation.png

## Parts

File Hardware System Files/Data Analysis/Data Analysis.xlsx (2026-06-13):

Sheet: CapEX
 |  | COMPONENT | UNIT | PRICE | TOTAL
1 x Main Hub
 | Raspberry Pi 5 | 8Gb (RedWhite Case Kit - UK Plug) | 1 | ₱9101.93 | ₱9101.93
 | Rpi Camera Module 3 | 12 MP w/ Auto-Focus and Wide Angle Lens | 1 | ₱2271.50 | ₱2271.50
 | Rpi 5 Active Cooler | 52Pi Low-Profile ICE Tower w/ Heatsink | 1 | ₱688.00 | ₱688.00
 | Wi-Fi Access Point | TP-Link WR820N | 1 | ₱599.00 | ₱599.00
 | RTC Module | DS3231 w/ AT24C32 EEPROM | 1 | ₱140.00 | ₱140.00
 | Filament Used | Bambu Lab Filament PLA Lite 1.75mm | 0.15694 | ₱759.00 | ₱119.12
 | Screws | Wood Screw | 4 | ₱0.75 | ₱3.00
ESP 1 - Dynamic Inside Sensor
 | NodeMCU ESP32 | Microcontroller with Expansion Board | 1 | ₱477.90 | ₱477.90
 | Li-ion Battery | PKCell 3.7V NMC 18650 3350 mAh | 2 | ₱205.00 | ₱410.00
 | Battery Holder | Series 18650 Single Cell | 1 | ₱33.00 | ₱33.00
 | Switch | Single Pole Single Throw KCD11 | 2 | ₱7.80 | ₱15.60
 | Supercapacitor | 5.5V 15F | 1 | ₱128.00 | ₱128.00
 | DC Power Monitor | INA226 I2C Interface | 1 | ₱72.00 | ₱72.00
 | Boost-Buck Converter | TPS63070 3.3V Regulator | 1 | ₱105.00 | ₱105.00
 | Air Quality Sensor | SHT31 | 1 | ₱139.00 | ₱139.00
 | RGB LED Module | SMD KY-016 | 1 | ₱40.00 | ₱40.00
 | Resistor | 1/4W 1% 230Ω | 3 | ₱0.37 | ₱1.10
 | Screw Terminal | KF301-2P 5.0mm Straight Pin | 1 | ₱5.50 | ₱5.50
 | Filament Used | Bambu Lab Filament PLA Lite 1.75mm | 0.11461 | ₱759.00 | ₱86.99
 | PCB Costs | JASCad | 1 | ₱400.00 | ₱400.00
 | Screws | Wood Screw | 4 | ₱0.75 | ₱3.00
ESP 2 - Static Inside Sensor
 | NodeMCU ESP32 | Microcontroller with Expansion Board | 1 | ₱477.90 | ₱477.90
 | Li-ion Battery | PKCell 3.7V NMC 18650 3350 mAh | 2 | ₱205.00 | ₱410.00
 | Battery Holder | Series 18650 Single Cell | 1 | ₱33.00 | ₱33.00
 | Switch | Single Pole Single Throw KCD11 | 2 | ₱7.80 | ₱15.60
 | Supercapacitor | 5.5V 15F | 1 | ₱128.00 | ₱128.00
 | DC Power Monitor | INA226 I2C Interface | 1 | ₱72.00 | ₱72.00
 | Boost Converter | TPS61023 5V Regulator | 1 | ₱195.00 | ₱195.00
 | Air Quality Sensor | SHT31 | 1 | ₱139.00 | ₱139.00
 | RGB LED Module | SMD KY-016 | 1 | ₱40.00 | ₱40.00
 | Resistor | 1/4W 1% 230Ω | 3 | ₱0.37 | ₱1.10
 | Screw Terminal | KF301-2P 5.0mm Straight Pin | 1 | ₱5.50 | ₱5.50
 | Transistor | 2N2222 | 2 | ₱5.00 | ₱10.00
 | IR LED | 5mm 940nm Infrared Light Emitter Diode | 2 | ₱4.70 | ₱9.40
 | Resistor | 1/4W 1% 37Ω | 2 | ₱0.37 | ₱0.73
 | Resistor | 1/4W 1% 470Ω | 2 | ₱0.37 | ₱0.73
 | Filament Used | Bambu Lab Filament PLA Lite 1.75mm | 0.17335 | ₱759.00 | ₱131.57
 | PCB Costs | JASCad | 1 | ₱400.00 | ₱400.00
 | Screws | Wood Screw | 4 | ₱0.75 | ₱3.00
ESP 3 - Outside Sensor
 | NodeMCU ESP32 | Microcontroller with Expansion Board | 1 | ₱477.90 | ₱477.90
 | Li-ion Battery | PKCell 3.7V NMC 18650 3350 mAh | 2 | ₱205.00 | ₱410.00
 | Battery Holder | Series 18650 Single Cell | 1 | ₱33.00 | ₱33.00
 | Switch | Single Pole Single Throw KCD11 | 2 | ₱7.80 | ₱15.60
 | Supercapacitor | 5.5V 15F | 1 | ₱128.00 | ₱128.00
 | DC Power Monitor | INA226 I2C Interface | 1 | ₱72.00 | ₱72.00 |  |  |  |  | grams of filament
 | Boost-Buck Converter | TPS63070 3.3V Regulator | 1 | ₱105.00 | ₱105.00 |  |  |  |  | Enclosure | Bracket
 | Air Quality Sensor | SHT31 | 1 | ₱139.00 | ₱139.00 |  |  |  | Main Hub | 156.94 | 0 | 156.94
 | RGB LED Module | SMD KY-016 | 1 | ₱40.00 | ₱40.00 |  |  |  | ESP 1 | 114.61 | 0 | 114.61
 | Resistor | 1/4W 1% 230Ω | 3 | ₱0.37 | ₱1.10 |  |  |  | ESP 2 | 142.69 | 30.66 | 173.35
 | Screw Terminal | KF301-2P 5.0mm Straight Pin | 1 | ₱5.50 | ₱5.50 |  |  |  | ESP 3 | 114.61 | 92.92 | 207.53
 | Filament Used | Bambu Lab Filament PLA Lite 1.75mm | 0.20753 | ₱759.00 | ₱157.52 |  |  |  | ESP 4 | 126.13 | 30.66 | 156.79
 | PCB Costs | JASCad | 1 | ₱400.00 | ₱400.00 |  |  |  | ESP 5 | 126.13 | 30.66 | 156.79
 | Screws | Wood Screw | 4 | ₱0.75 | ₱3.00 |  |  |  |  |  | total grams | 966.01
ESP 4 - ACU Power Monitor 1
 | NodeMCU ESP32 | Microcontroller with Expansion Board | 1 | ₱477.90 | ₱477.90
 | Li-ion Battery | PKCell 3.7V NMC 18650 3350 mAh | 2 | ₱205.00 | ₱410.00 |  |  |  |  | 59 | php/usd
 | Battery Holder | Series 18650 Single Cell | 1 | ₱33.00 | ₱33.00 |  |  |  |  | unit usd | total usd | php
 | Switch | Single Pole Single Throw KCD11 | 2 | ₱7.80 | ₱15.60 |  |  | 1 | rpi kit | $154.27 | $154.27 | ₱9101.93
 | Supercapacitor | 5.5V 15F | 1 | ₱128.00 | ₱128.00 |  |  | 5 | esp32 | $8.10 | $40.50 | ₱2389.50
 | DC Power Monitor | INA226 I2C Interface | 1 | ₱72.00 | ₱72.00 |  |  | 1 | cam | $38.50 | $38.50 | ₱2271.50
 | Boost Converter | TPS61023 5V Regulator | 1 | ₱195.00 | ₱195.00 |  |  | 1 | pzem | $17.25 | $17.25 | ₱1017.75
 | AC Power Monitor | PZEM-004T v3.0 w/ Open CT | 1 | ₱670.00 | ₱670.00
 | RGB LED Module | SMD KY-016 | 1 | ₱40.00 | ₱40.00
 | Resistor | 1/4W 1% 230Ω | 3 | ₱0.37 | ₱1.10 |  |  | Logistics
 | Screw Terminal | KF301-2P 5.0mm Straight Pin | 1 | ₱5.50 | ₱5.50 |  |  | fedex | ship fee | $26.57 | $13.29 | ₱783.82
 | Stranded Wire |  | 1 | ₱25.00 | ₱25.00 |  |  | shopee | ship fee |  |  | ₱315.00
 | Plug |  | 1 | ₱45.00 | ₱45.00 |  |  | fedex | tax |  |  | ₱2600.00
 | Filament Used | Bambu Lab Filament PLA Lite 1.75mm | 0.15679 | ₱759.00 | ₱119.00
 | PCB Costs | JASCad | 1 | ₱400.00 | ₱400.00
 | Screws | Wood Screw | 4 | ₱0.75 | ₱3.00
ESP 5 - ACU Power Monitor 2
 | NodeMCU ESP32 | Microcontroller with Expansion Board | 1 | ₱477.90 | ₱477.90
 | Li-ion Battery | PKCell 3.7V NMC 18650 3350 mAh | 2 | ₱205.00 | ₱410.00
 | Battery Holder | Series 18650 Single Cell | 1 | ₱33.00 | ₱33.00
 | Switch | Single Pole Single Throw KCD11 | 2 | ₱7.80 | ₱15.60
 | Supercapacitor | 5.5V 15F | 1 | ₱128.00 | ₱128.00
 | DC Power Monitor | INA226 I2C Interface | 1 | ₱72.00 | ₱72.00
 | Boost Converter | TPS61023 5V Regulator | 1 | ₱195.00 | ₱195.00
 | AC Power Monitor | PZEM-004T v3.0 w/ Open CT | 1 | ₱670.00 | ₱670.00
 | RGB LED Module | SMD KY-016 | 1 | ₱40.00 | ₱40.00
 | Resistor | 1/4W 1% 230Ω | 3 | ₱0.37 | ₱1.10
 | Screw Terminal | KF301-2P 5.0mm Straight Pin | 1 | ₱5.50 | ₱5.50
 | Stranded Wire |  | 1 | ₱25.00 | ₱25.00
 | Plug |  | 1 | ₱45.00 | ₱45.00
 | Filament Used | Bambu Lab Filament PLA Lite 1.75mm | 0.15679 | ₱759.00 | ₱119.00
 | PCB Costs | JASCad | 1 | ₱400.00 | ₱400.00
 | Screws | Wood Screw | 4 | ₱0.75 | ₱3.00
Other General Components
 | Li-ion Battery Charger | CMOCO Lii-402 Universal Li-ion Charger | 1 | ₱446.00 | ₱446.00
 | Heat Shrink Tubes | LESU PE Insulation Materials Kit (127 pcs) | 1 | ₱56.00 | ₱56.00
 | Jumper Wires | Dupont Wires 2.54mm Assorted | 1 | ₱265.00 | ₱265.00
 | Cable Wires | JST-XH 2.54mm Assorted | 1 | ₱380.00 | ₱380.00
 | Electrical Tape | Medium Size | 2 | ₱45.00 | ₱90.00
 | Soldering Lead |  | 1 | ₱45.00 | ₱45.00
 | Pin Header | 10 pcs 1x40 Single Row Male 2.54mm Strip | 3 | ₱5.60 | ₱16.80
 | USB-C Power Meter | POROMETISTO UT02C Max 12A | 1 | ₱389.00 | ₱389.00
 | Breadboard | ENGLAB MB102 400 Tie Points | 5 | ₱45.00 | ₱225.00
TOTAL MATERIAL COSTS |  |  |  |  | ₱26092.80
 |  |  |  | https://wiki.bambulab.com/en/a1-mini/manual/faq
 | Installation Costs |  |  | 57.00
 | Bambu Lab Printing Operating Hours |  | print hrs | W | kWh | rate | unit | costs
 |  | All Enclosures and Brackets | 28.87 | ₱57.00 | ₱1.65 | 10.50 | Php/kWh | ₱17.28
 | Labor Costs |  | number |  |  | rate
 |  | 1 day installation | 3 |  |  | ₱500.00 | Php/day | ₱1500.00
 | Engineering Costs |  |  |  |  |  |  | ₱1000.00
 | Logistics | Shipping Fees and Taxes (FedEX) |  |  |  |  |  | ₱3698.82
 |  |  |  |  |  |  |  | ₱6216.09
 | Total CapEX | Material Costs | ₱26092.80
 |  | Installation Costs | ₱6216.09
 |  | Sub-Total | ₱32308.89
 |  | Contingency Costs (5%) | ₱1615.44
 |  | Total CapEX | ₱33924.33

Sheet: CapEX 2
 |  | COMPONENT | UNIT | PRICE | TOTAL
1 x Main Hub
 | Raspberry Pi 5 | 8Gb (RedWhite Case Kit - UK Plug) | 1 | ₱9101.93 | ₱9101.93
 | Rpi Camera Module 3 | 12 MP w/ Auto-Focus and Wide Angle Lens | 1 | ₱2271.50 | ₱2271.50
 | Rpi 5 Active Cooler | 52Pi Low-Profile ICE Tower w/ Heatsink | 1 | ₱688.00 | ₱688.00
 | Wi-Fi Access Point | TP-Link WR820N | 1 | ₱599.00 | ₱599.00
 | RTC Module | DS3231 w/ AT24C32 EEPROM | 1 | ₱140.00 | ₱140.00
 | Filament Used | Bambu Lab Filament PLA Lite 1.75mm | 0.15694 | ₱759.00 | ₱119.12
 | Screws | Wood Screw | 4 | ₱0.75 | ₱3.00
ESP 1 - Dynamic Inside Sensor
 | NodeMCU ESP32 | Microcontroller with Expansion Board | 1 | ₱477.90 | ₱477.90
 | Li-ion Battery | PKCell 3.7V NMC 18650 3350 mAh | 0 | ₱205.00 | ₱0.00
 | Battery Holder | Series 18650 Single Cell | 0 | ₱33.00 | ₱0.00
 | Switch | Single Pole Single Throw KCD11 | 1 | ₱7.80 | ₱7.80
 | Supercapacitor | 5.5V 15F | 0 | ₱128.00 | ₱0.00
 | DC Power Monitor | INA226 I2C Interface | 0 | ₱72.00 | ₱0.00
 | Boost-Buck Converter | TPS63070 3.3V Regulator | 0 | ₱105.00 | ₱0.00
 | Air Quality Sensor | SHT31 | 1 | ₱139.00 | ₱139.00
 | RGB LED Module | SMD KY-016 | 1 | ₱40.00 | ₱40.00
 | Resistor | 1/4W 1% 230Ω | 3 | ₱0.37 | ₱1.10
 | Screw Terminal | KF301-2P 5.0mm Straight Pin | 1 | ₱5.50 | ₱5.50
 | Filament Used | Bambu Lab Filament PLA Lite 1.75mm | 0.11461 | ₱759.00 | ₱86.99
 | PCB Costs | JASCad | 1 | ₱400.00 | ₱400.00
 | Screws | Wood Screw | 4 | ₱0.75 | ₱3.00
ESP 2 - Static Inside Sensor
 | NodeMCU ESP32 | Microcontroller with Expansion Board | 1 | ₱477.90 | ₱477.90
 | Li-ion Battery | PKCell 3.7V NMC 18650 3350 mAh | 0 | ₱205.00 | ₱0.00
 | Battery Holder | Series 18650 Single Cell | 0 | ₱33.00 | ₱0.00
 | Switch | Single Pole Single Throw KCD11 | 1 | ₱7.80 | ₱7.80
 | Supercapacitor | 5.5V 15F | 0 | ₱128.00 | ₱0.00
 | DC Power Monitor | INA226 I2C Interface | 0 | ₱72.00 | ₱0.00
 | Boost Converter | TPS61023 5V Regulator | 0 | ₱195.00 | ₱0.00
 | Air Quality Sensor | SHT31 | 1 | ₱139.00 | ₱139.00
 | RGB LED Module | SMD KY-016 | 1 | ₱40.00 | ₱40.00
 | Resistor | 1/4W 1% 230Ω | 3 | ₱0.37 | ₱1.10
 | Screw Terminal | KF301-2P 5.0mm Straight Pin | 1 | ₱5.50 | ₱5.50
 | Transistor | 2N2222 | 2 | ₱5.00 | ₱10.00
 | IR LED | 5mm 940nm Infrared Light Emitter Diode | 2 | ₱4.70 | ₱9.40
 | Resistor | 1/4W 1% 37Ω | 2 | ₱0.37 | ₱0.73
 | Resistor | 1/4W 1% 470Ω | 2 | ₱0.37 | ₱0.73
 | Filament Used | Bambu Lab Filament PLA Lite 1.75mm | 0.17335 | ₱759.00 | ₱131.57
 | PCB Costs | JASCad | 1 | ₱400.00 | ₱400.00
 | Screws | Wood Screw | 4 | ₱0.75 | ₱3.00
ESP 3 - Outside Sensor
 | NodeMCU ESP32 | Microcontroller with Expansion Board | 1 | ₱477.90 | ₱477.90
 | Li-ion Battery | PKCell 3.7V NMC 18650 3350 mAh | 0 | ₱205.00 | ₱0.00
 | Battery Holder | Series 18650 Single Cell | 0 | ₱33.00 | ₱0.00
 | Switch | Single Pole Single Throw KCD11 | 1 | ₱7.80 | ₱7.80
 | Supercapacitor | 5.5V 15F | 0 | ₱128.00 | ₱0.00
 | DC Power Monitor | INA226 I2C Interface | 0 | ₱72.00 | ₱0.00 |  |  |  |  | grams of filament
 | Boost-Buck Converter | TPS63070 3.3V Regulator | 0 | ₱105.00 | ₱0.00 |  |  |  |  | Enclosure | Bracket
 | Air Quality Sensor | SHT31 | 1 | ₱139.00 | ₱139.00 |  |  |  | Main Hub | 156.94 | 0 | 156.94
 | RGB LED Module | SMD KY-016 | 1 | ₱40.00 | ₱40.00 |  |  |  | ESP 1 | 114.61 | 0 | 114.61
 | Resistor | 1/4W 1% 230Ω | 3 | ₱0.37 | ₱1.10 |  |  |  | ESP 2 | 142.69 | 30.66 | 173.35
 | Screw Terminal | KF301-2P 5.0mm Straight Pin | 1 | ₱5.50 | ₱5.50 |  |  |  | ESP 3 | 114.61 | 92.92 | 207.53
 | Filament Used | Bambu Lab Filament PLA Lite 1.75mm | 0.20753 | ₱759.00 | ₱157.52 |  |  |  | ESP 4 | 126.13 | 30.66 | 156.79
 | PCB Costs | JASCad | 1 | ₱400.00 | ₱400.00 |  |  |  | ESP 5 | 126.13 | 30.66 | 156.79
 | Screws | Wood Screw | 4 | ₱0.75 | ₱3.00 |  |  |  |  |  | total grams | 966.01
ESP 4 - ACU Power Monitor 1
 | NodeMCU ESP32 | Microcontroller with Expansion Board | 1 | ₱477.90 | ₱477.90
 | Li-ion Battery | PKCell 3.7V NMC 18650 3350 mAh | 0 | ₱205.00 | ₱0.00 |  |  |  |  | 59 | php/usd
 | Battery Holder | Series 18650 Single Cell | 0 | ₱33.00 | ₱0.00 |  |  |  |  | unit usd | total usd | php
 | Switch | Single Pole Single Throw KCD11 | 1 | ₱7.80 | ₱7.80 |  |  | 1 | rpi kit | $154.27 | $154.27 | ₱9101.93
 | Supercapacitor | 5.5V 15F | 0 | ₱128.00 | ₱0.00 |  |  | 5 | esp32 | $8.10 | $40.50 | ₱2389.50
 | DC Power Monitor | INA226 I2C Interface | 0 | ₱72.00 | ₱0.00 |  |  | 1 | cam | $38.50 | $38.50 | ₱2271.50
 | Boost Converter | TPS61023 5V Regulator | 0 | ₱195.00 | ₱0.00 |  |  | 1 | pzem | $17.25 | $17.25 | ₱1017.75
 | AC Power Monitor | PZEM-004T v3.0 w/ Open CT | 1 | ₱670.00 | ₱670.00
 | RGB LED Module | SMD KY-016 | 1 | ₱40.00 | ₱40.00
 | Resistor | 1/4W 1% 230Ω | 3 | ₱0.37 | ₱1.10 |  |  | Logistics
 | Screw Terminal | KF301-2P 5.0mm Straight Pin | 1 | ₱5.50 | ₱5.50 |  |  | fedex | ship fee | $26.57 | $13.29 | ₱783.82
 | Stranded Wire |  | 1 | ₱25.00 | ₱25.00 |  |  | shopee | ship fee |  |  | ₱315.00
 | Plug |  | 1 | ₱45.00 | ₱45.00 |  |  | fedex | tax |  |  | ₱2600.00
 | Filament Used | Bambu Lab Filament PLA Lite 1.75mm | 0.15679 | ₱759.00 | ₱119.00
 | PCB Costs | JASCad | 1 | ₱400.00 | ₱400.00
 | Screws | Wood Screw | 4 | ₱0.75 | ₱3.00
ESP 5 - ACU Power Monitor 2
 | NodeMCU ESP32 | Microcontroller with Expansion Board | 1 | ₱477.90 | ₱477.90
 | Li-ion Battery | PKCell 3.7V NMC 18650 3350 mAh | 0 | ₱205.00 | ₱0.00
 | Battery Holder | Series 18650 Single Cell | 0 | ₱33.00 | ₱0.00
 | Switch | Single Pole Single Throw KCD11 | 1 | ₱7.80 | ₱7.80
 | Supercapacitor | 5.5V 15F | 0 | ₱128.00 | ₱0.00
 | DC Power Monitor | INA226 I2C Interface | 0 | ₱72.00 | ₱0.00
 | Boost Converter | TPS61023 5V Regulator | 0 | ₱195.00 | ₱0.00
 | AC Power Monitor | PZEM-004T v3.0 w/ Open CT | 1 | ₱670.00 | ₱670.00
 | RGB LED Module | SMD KY-016 | 1 | ₱40.00 | ₱40.00
 | Resistor | 1/4W 1% 230Ω | 3 | ₱0.37 | ₱1.10
 | Screw Terminal | KF301-2P 5.0mm Straight Pin | 1 | ₱5.50 | ₱5.50
 | Stranded Wire |  | 1 | ₱25.00 | ₱25.00
 | Plug |  | 1 | ₱45.00 | ₱45.00
 | Filament Used | Bambu Lab Filament PLA Lite 1.75mm | 0.15679 | ₱759.00 | ₱119.00
 | PCB Costs | JASCad | 1 | ₱400.00 | ₱400.00
 | Screws | Wood Screw | 4 | ₱0.75 | ₱3.00
Other General Components
 | Li-ion Battery Charger | CMOCO Lii-402 Universal Li-ion Charger | 1 | ₱446.00 | ₱446.00
 | Heat Shrink Tubes | LESU PE Insulation Materials Kit (127 pcs) | 1 | ₱56.00 | ₱56.00
 | Jumper Wires | Dupont Wires 2.54mm Assorted | 1 | ₱265.00 | ₱265.00
 | Cable Wires | JST-XH 2.54mm Assorted | 1 | ₱380.00 | ₱380.00
 | Electrical Tape | Medium Size | 2 | ₱45.00 | ₱90.00
 | Soldering Lead |  | 1 | ₱45.00 | ₱45.00
 | Pin Header | 10 pcs 1x40 Single Row Male 2.54mm Strip | 3 | ₱5.60 | ₱16.80
 | USB-C Power Meter | POROMETISTO UT02C Max 12A | 0 | ₱389.00 | ₱0.00
 | Breadboard | ENGLAB MB102 400 Tie Points | 0 | ₱45.00 | ₱0.00
TOTAL MATERIAL COSTS |  |  |  |  | ₱21429.80
 |  |  |  | https://wiki.bambulab.com/en/a1-mini/manual/faq
 | Installation Costs |  |  | 57.00
 | Bambu Lab Printing Operating Hours |  | print hrs | W | kWh | rate | unit | costs
 |  | All Enclosures and Brackets | 28.87 | ₱57.00 | ₱1.65 | 10.50 | Php/kWh | ₱17.28
 | Labor Costs |  | number | days |  | rate
 |  | Hardware | 2 | 1.00 |  | ₱500.00 | Php/day | ₱1000.00
 |  | Software | 1 | 2.00 |  | ₱500.00 | Php/day | ₱1000.00
 | Engineering Costs | PCB Designing |  |  |  |  |  | ₱1000.00
 |  | Contingency Costs (5%) | 5% |  |  |  |  | ₱1071.49
 |  |  |  |  |  |  |  | ₱4088.77
 | Total CapEX | Material Costs | ₱21429.80
 |  | Installation Costs | ₱4088.77
 |  | Sub-Total | ₱25518.56
 |  | Total CapEX | ₱25518.56
 |  | Selling Price | ₱26000.00

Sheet: OpEX
Operation Costs
 | Electricity Costs
 |  |  | Consumption |  | hours per day |  | days per week |  | week per year |  | annual kWh
 |  | Rpi 5 | 2.90 | W | 8 | hrs | 5 | days | 48 | wks | 4.82 | Holidays | 20 | days a year
 |  | ESP1 | 0.29 | W | 8 | hrs | 5 | days | 48 | wks | 0.48 | Maintenance Days | 12 | days a year
 |  | ESP2 | 0.53 | W | 8 | hrs | 5 | days | 48 | wks | 0.87 |  | 256 | hours of no operation
 |  | ESP3 | 0.30 | W | 8 | hrs | 5 | days | 48 | wks | 0.50
 |  | ESP4 | 0.57 | W | 8 | hrs | 5 | days | 48 | wks | 0.94 | Weeks Per Year: | 52 total weeks - 4 weeks downtime due to unforseen events
 |  | ESP5 | 0.54 | W | 8 | hrs | 5 | days | 48 | wks | 0.90
 |  |  |  |  |  |  |  | Annual System Energy Use (kWh) |  |  | 8.51
 |  |  |  |  |  |  |  |  | Rate (Php/kWh) |  | ₱10.50
 |  |  |  |  |  |  |  | Electricity Costs |  |  | ₱89.40
 | Preventive Maintenance Allowance |  |  |  | 5% | of Total CapEX |  |  |  |  | ₱1300.00
 |  |  |  |  | Equivalent Monthly Preventive Maintenance Allocation |  |  |  |  |  | ₱108.33
 |  | method of maintenance: seller gives user manual, user maintains
TOTAL |  | higher usage hours per year, lowers payback period |  |  |  |  |  |  |  |  | ₱1389.40
 |  | lower usage hours per year, higher payback period

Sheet: AES
Annual Energy Savings |  |  |  |  |  |  |  | 56 | hr total testing hours
 | Total Manual Baseline Energy Consumption (56-hr) |  |  |  |  | 106.95 | kWh | 1.91
 | Total B.O.R.F. Energy Consumption (56-hr) |  |  |  |  | 84.98 | kWh | 1.52
 |  | Hourly Energy Savings |  |  |  | 21.97 | kWh | 0.39
 |  | Hourly Savings |  | hours per day |  | days per week |  | week per year |  | annual kWh
 |  | 0.39 | kW | 6 | hrs | 5 | days | 48 | wks | 464.43 | Holidays | 20 | days a year
 |  |  |  |  |  |  |  |  |  |  | Maintenance Days | 12 | days a year
 |  |  |  |  |  |  |  |  |  |  |  | 256 | hours of no operation
 |  | Manual Consumption |  | hours per day |  | days per week |  | week per year |  | annual kWh | Number of Hours | 1664 | usage hours per annum
 |  | 1.91 | kW | 6 | hrs | 5 | days | 48 | wks | 2261.15
 |  |  |  |  |  |  |  | % energy savings |  | 20.5396%
 |  | BORF Consumption |  | hours per day |  | days per week |  | week per year |  | annual kWh
 |  | 1.52 | kW | 6 | hrs | 5 | days | 48 | wks | 1796.72
 |  |  |  |  |  |  |  |  |  | 464.43

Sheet: Links
AC Power Monitor | https://shopee.ph/PZEM-004T-Ac-Multi-function-Electric-Energy-Metering-Power-Monitor-Watt-Meter-i.18252381.18907013159
Air Quality Sensor | https://shopee.ph/GY-SHT30-D-GY-SHT31-D-SHT35-SHT40-SHT41-SHT45-digital-temperature-and-humidity-sensor-module-i.425178766.28155859377
Battery Holder | https://shopee.ph/Series-Battery-Holder-18650-with-Wire-1-Cell-2-Cell-3-Cell-1S-2S-3S-Single-Double-Triple-i.18252381.453473950
Boost Converter | https://shopee.ph/DIYMORE-TPS61023-Mini-Boost-Module-5V-1A-Boost-Regulator-Voltage-from-2-5V-DC-to-5V-Boost-Module-Board-Boost-Voltage-Module-i.173799909.2942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
Boost-Buck Converter | https://shopee.ph/TPS63070-3.3V-5V-9V-USB-Lithium-Battery-Automatic-Lifting-Power-Module-9V-Voltage-Regulator-Module-i.1541768712.42350844285
Breadboard | https://shopee.ph/ENGLAB★MB102-Solderless-Breadboard-Mini-Breadboard-830-400-holes-Experiment-Donut-Board-i.1021339444.25619955031
Cable Wires | https://shopee.ph/10PCS-JST-2.0-PH-2.0-XH2.54-2-3-4-5-6-7-8-9-10Pin-Connector-Plug-With-Wires-Cables-26AWG-Female-Plug-Connector-i.1557777697.56603548505
DC Power Monitor | https://shopee.ph/INA226-CJMCU-226-IIC-I2C-interface-Bi-directional-current-Power-monitoring-sensor-module-For-Arduino-i.580325202.20058025676
Electrical Tape | Mr. DIY
Filament Used | https://shopee.ph/Bambu-Filament-PLA-Lite-1.75mm-1kg-i.18252381.44420717352
Heat Shrink Tubes | https://shopee.ph/LESU-Good-Quality-127-164-328-530-580-pcs-PE-Insulation-Materials-Heat-Shrink-Tube-Kit-i.1191696558.25265128548
IR LED | https://shopee.ph/10-50Pcs-3mm-5mm-Infrared-Emitter-Transmitter-and-IR-Receiver-Diode-940nm-LED-i.720292301.22512102932
Jumper Wires | https://shopee.ph/40pcs-10cm-20cm-30cm-Breadboard-connecting-Jumper-Wires-Dupont-Wire-Cable-Arduino-Prototyping-i.18252381.190149221
Li-ion Battery | https://shopee.ph/PKCell-3.7V-Lithium-ion-NMC-18650-Battery-for-Solar-Electric-Scooter-Mini-Fan-Power-Bank-i.18252381.1670629656
Li-ion Battery Charger | https://shopee.ph/CMOCO-Lii-402-Smart-Universal-Lithium-Li-ion-Battery-Charger-18650-26650-26500-22650-i.450342464.21320325216
NodeMCU ESP32 | https://www.cytron.io/amp-p-esp32-with-expansion-board
PCB Manuacturing | JASCad
Pin Header | https://shopee.ph/10PCS-Header-40-Pin-1x40-Single-Row-Male-2.54-Breakable-Pin-Connector-Strip-For-Arduino-i.1367148707.29135116893
Plug | Utod Hardware
Raspberry Pi 5 | https://www.cytron.io/amp-p-official-red-white-case-kit-with-raspberry-pi-5-8gb-ram-uk-plug
Resistor | https://shopee.ph/1-4W-Resistance-1-Metal-Film-Resistor-Assorted-Kit-Each-20-Total-600pcs-47Ω-220Ω-1K-10K-47K-68K-100-i.18252381.363309195
RGB LED Module | https://shopee.ph/KY-009-SMD-RGB-LED-Module-KY-016-RGB-Module-DIP-type-Sensor-Module-for-Arduino-DIY-Starter-Kit-i.18252381.14114755056
Rpi 5 Active Cooler | https://shopee.ph/52Pi-Low-Profile-ICE-Tower-Raspberry-Pi-5-Cooler-Raspberry-Pi-5-Cooling-Fan-with-Heatsink-i.1045487524.25410402845
Rpi Camera Module 3 | https://www.cytron.io/amp-p-raspberry-pi-camera-module-3-12mp-with-auto-focus-and-wide-angle-lens
RTC Module | https://shopee.ph/DS3231-w-AT24C32-EEPROM-MINI-DS3231-RTC-High-Precision-Real-Time-Clock-Module-i.18252381.243542905
Screw Terminal | https://shopee.ph/10PCS-KF301-2P-KF301-5.0-2P-KF301-Screw-2Pin-5.0mm-Straight-Pin-PCB-Screw-Terminal-Block-Connector-KF301-3P-i.1570973467.51752504327
Screws | Sunshine
Soldering Lead | Mr. DIY
Stranded Wire | Utod Hardware
Supercapacitor | https://shopee.ph/1PCS-New-Super-Capacitor-Farad-Capacitor-Combination-Type-5.5V-0.5F-1F-2F-3.5F-4F-5F-7.5F-10F-15F-i.1130255612.24652455320
Switch | https://shopee.ph/SPST-KCD11-Miniature-Rocker-Switch-5Pcs-i.18252381.2391952164
Transistor | https://shopee.ph/NPN-PNP-Transistor-2N2222-2N3904-2N3906-2N5401-2N5551-S8050-S8550-S9012-S9013-S9014-S9015-DIY-i.172443349.6209768414
USB-C Power Meter | https://shopee.ph/POROMETISTO-UT02C-NEW-ARRIVAL-Multi-function-USB-Type-C-Tester-Maximum-12A-Fast-Charging-Test-CPU-Temp-Monitor-Voltage-Ammeter-Power-Meter-i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
Wi-Fi Access Point | https://shopee.ph/TP-Link-TL-WR820N-Wi-Fi-Extender-Long-Range-Repeater-Wi-Fi-Router-Access-Point-High-Speed-i.117867014.2418564963
(blank)
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

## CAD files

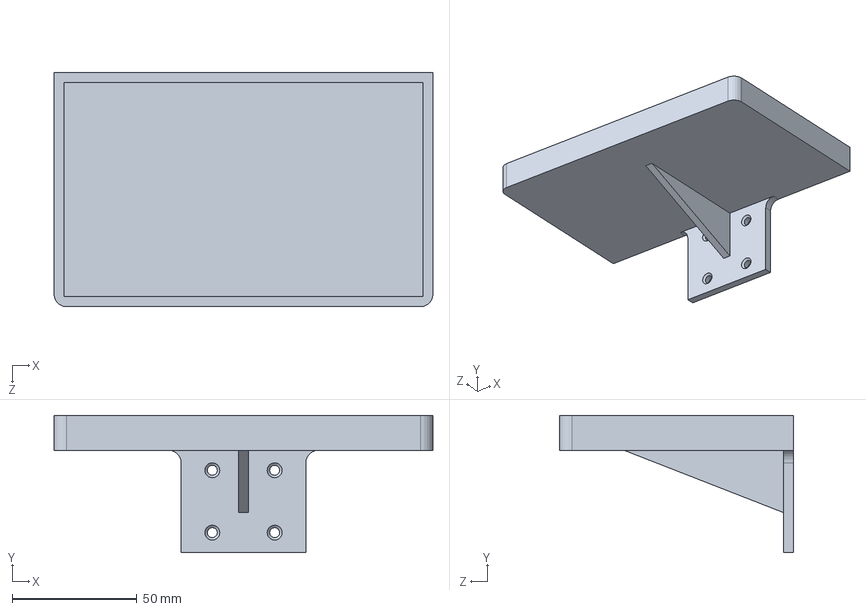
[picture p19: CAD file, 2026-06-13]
Hardware System Files/Enclosures/ESP Platforms/Stand v3.SLDPRT
152.0 x 55.0 x 94.0 mm

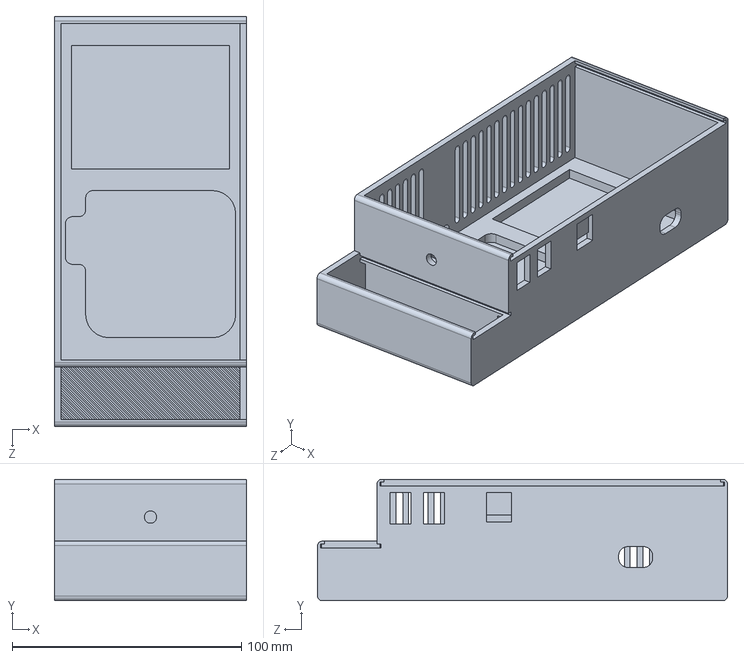
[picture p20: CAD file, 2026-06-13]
Hardware System Files/Enclosures/IR Node/IR Node Enclosure.SLDPRT
84.0 x 53.0 x 179.0 mm

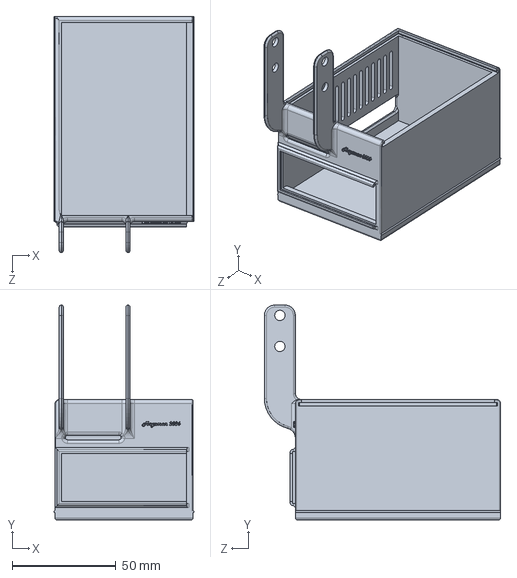
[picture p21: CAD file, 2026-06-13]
Hardware System Files/Enclosures/Raspberry Pi 5/1_BaseBody.sldprt
67.5 x 103.7 x 114.0 mm

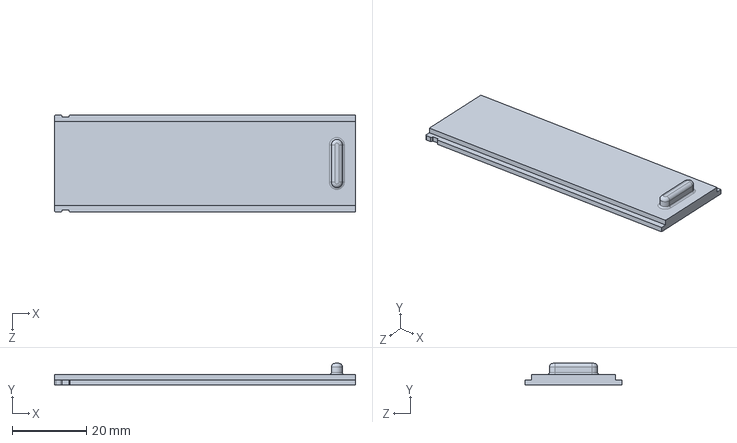
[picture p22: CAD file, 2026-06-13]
Hardware System Files/Enclosures/Temperature Nodes/Sensor Node Battery Cover.SLDPRT
81.0 x 5.80 x 26.1 mm

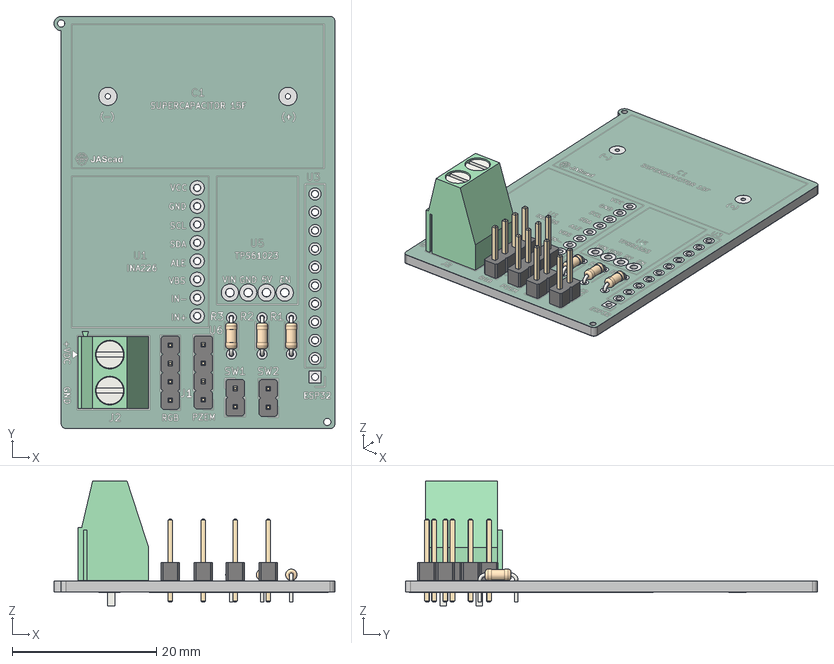
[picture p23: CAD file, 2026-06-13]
Hardware System Files/Printed Circuit Boards/STP Files/ACU Node PCB.step
39.0 x 57.2 x 17.3 mm
PinHeader_1x04_P2.54mm_Vertical x 2
PinHeader_1x02_P2.54mm_Vertical x 2
R_Axial_DIN0204_L3.6mm_D1.6mm_P5.08mm_Horizontal x 3
TerminalBlock_Phoenix_MKDS-1,5-2_1x02_P5.00mm_Horizontal
ACU-Node_copper
ACU-Node_pad
ACU-Node_via
ACU-Node_silkscreen x 2
ACU-Node_soldermask x 2
ACU-Node_PCB

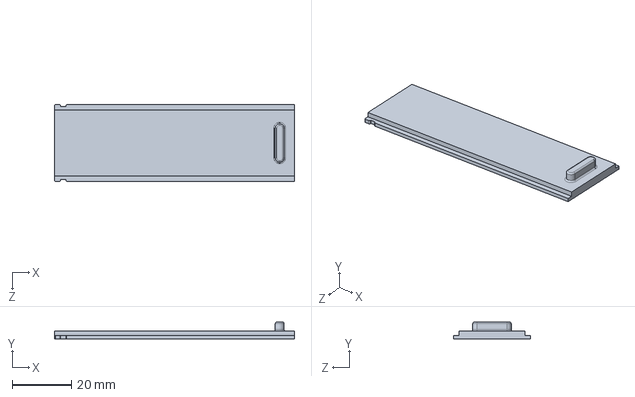
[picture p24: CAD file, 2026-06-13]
Hardware System Files/Enclosures/ACU Nodes/ACU Node Battery Cover 2.SLDPRT
81.0 x 5.70 x 25.9 mm

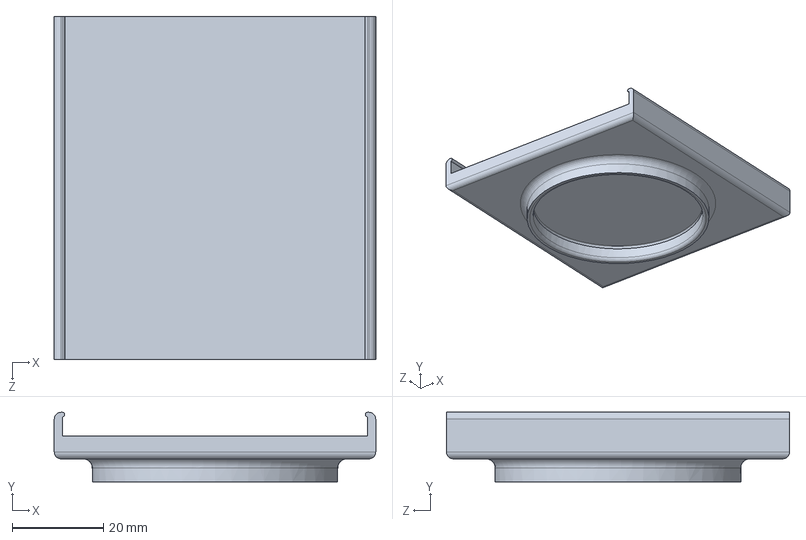
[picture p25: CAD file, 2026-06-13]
Hardware System Files/Enclosures/Raspberry Pi 5/3_Locking1.sldprt
70.3 x 15.2 x 75.0 mm

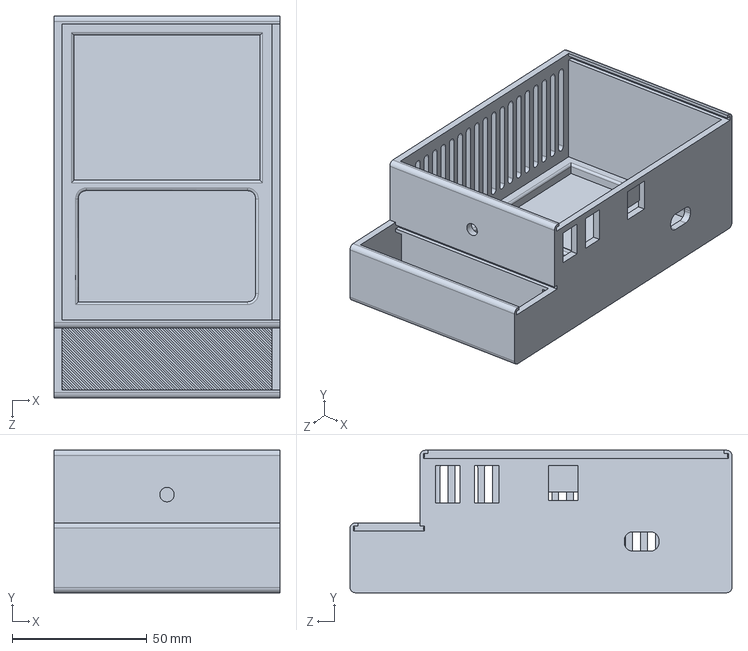
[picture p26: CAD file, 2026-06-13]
Hardware System Files/Enclosures/Temperature Nodes/Sensor Node Enclosure.SLDPRT
84.0 x 53.0 x 142.0 mm

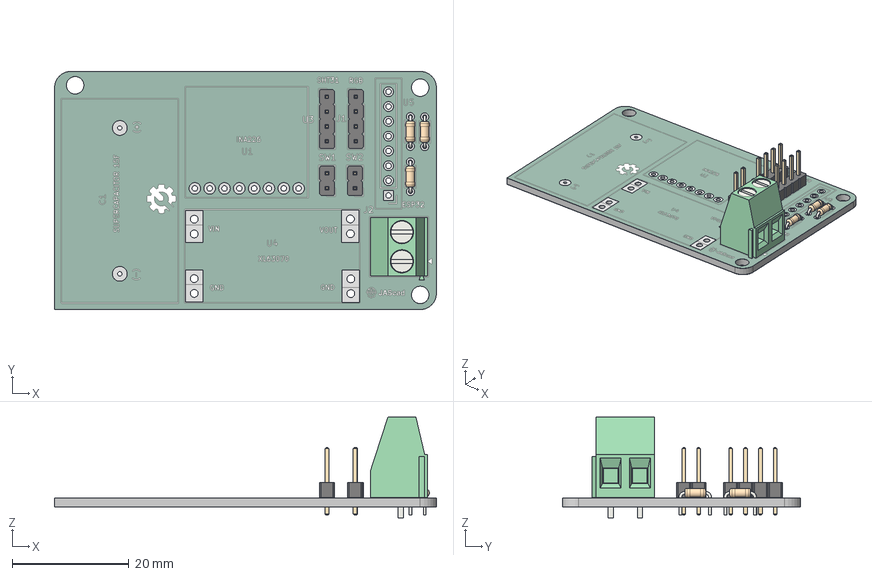
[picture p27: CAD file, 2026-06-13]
Hardware System Files/Printed Circuit Boards/STP Files/Sensor Node PCB.step
65.5 x 40.8 x 17.3 mm
PinHeader_1x04_P2.54mm_Vertical x 2
TerminalBlock_Phoenix_MKDS-1,5-2_1x02_P5.00mm_Horizontal
PinHeader_1x02_P2.54mm_Vertical x 2
R_Axial_DIN0204_L3.6mm_D1.6mm_P5.08mm_Horizontal x 3
Sensor_Node-TH_copper
Sensor_Node-TH_pad
Sensor_Node-TH_via
Sensor_Node-TH_silkscreen x 2
Sensor_Node-TH_soldermask x 2
Sensor_Node-TH_PCB

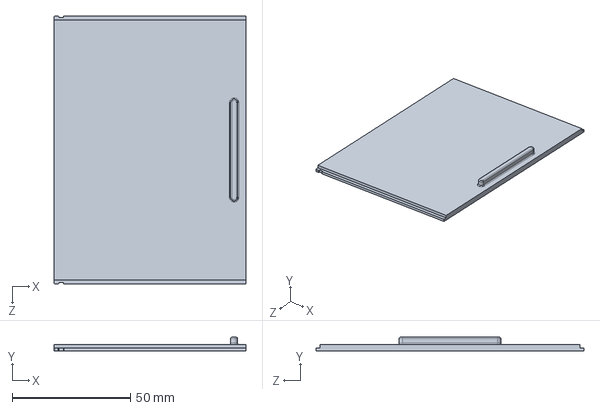
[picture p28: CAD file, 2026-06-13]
Hardware System Files/Enclosures/ACU Nodes/ACU Node Cover 2.SLDPRT
81.0 x 5.70 x 113.1 mm

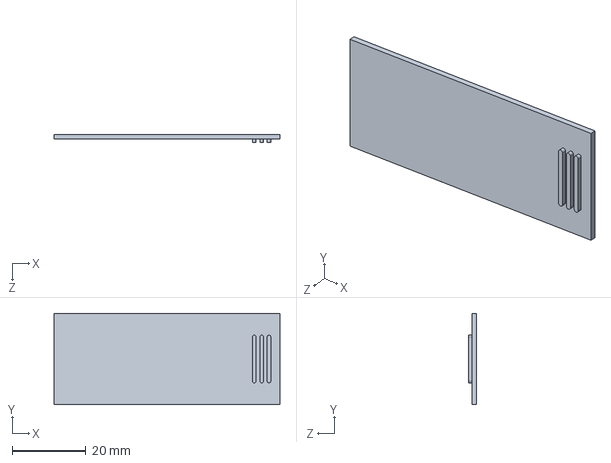
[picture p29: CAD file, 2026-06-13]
Hardware System Files/Enclosures/Raspberry Pi 5/2_Cover1.sldprt
61.5 x 24.8 x 2.30 mm

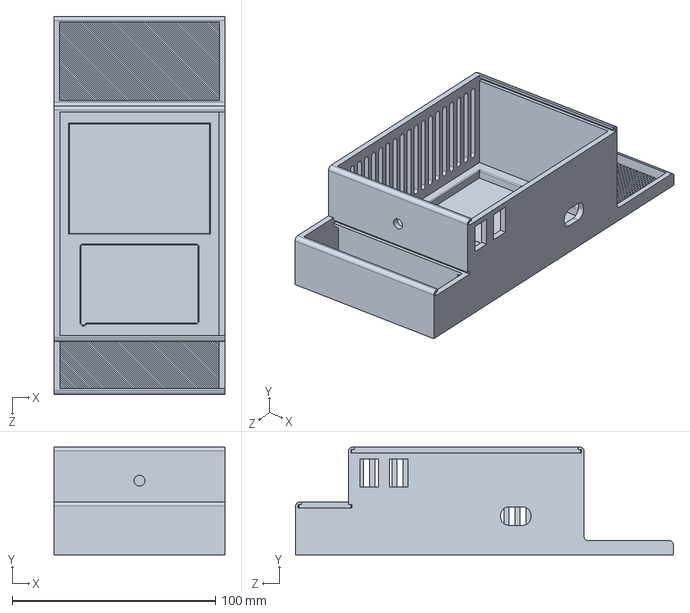
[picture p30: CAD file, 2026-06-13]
Hardware System Files/Enclosures/ACU Nodes/ACU Node Enclosure.SLDPRT
84.0 x 53.0 x 186.0 mm

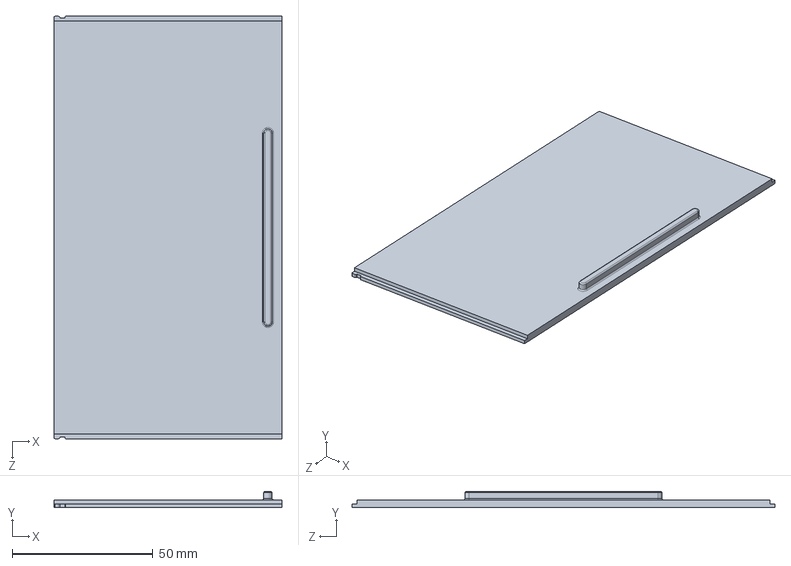
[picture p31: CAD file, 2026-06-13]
Hardware System Files/Enclosures/IR Node/IR Node Cover.SLDPRT
81.0 x 5.80 x 150.1 mm

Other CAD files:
Hardware System Files/Enclosures/ACU Nodes/ACU Node Final.gcode.3mf
Hardware System Files/Enclosures/IR Node/IR Node Battery Cover.SLDPRT
Hardware System Files/Enclosures/IR Node/IR Node Final.gcode.3mf
Hardware System Files/Enclosures/Temperature Nodes/Sensor Node Enclosure v3 Final.gcode.3mf
Hardware System Files/Enclosures/ESP Platforms/Stand v3.gcode.3mf
Hardware System Files/Enclosures/ESP Platforms/Stand v1.SLDPRT
Hardware System Files/Enclosures/ESP Platforms/Stand v1.gcode.3mf
Hardware System Files/Enclosures/Raspberry Pi 5/2_Cover2.sldprt
Hardware System Files/Enclosures/Raspberry Pi 5/3_Locking2.sldprt
Hardware System Files/Enclosures/Temperature Nodes/Sensor Node Cover.SLDPRT

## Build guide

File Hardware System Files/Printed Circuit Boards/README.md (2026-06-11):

tenkyu JASCad 

follow and avail their services vv recommended 

  FB: JASCad

  GMail: jascaddesigns@gmail.com

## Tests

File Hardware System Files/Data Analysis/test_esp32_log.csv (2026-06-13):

timestamp | esp_id | voltage | power | status
2026-02-19 00:54:09 | ESP_1 | 3.54 | 603.75 | OK
2026-02-19 00:54:09 | ESP_3 | 3.47 | 592.5 | OK
2026-02-19 00:55:09 | ESP_1 | 3.54 | 605.63 | OK
2026-02-19 00:55:09 | ESP_3 | 3.46 | 622.5 | OK
2026-02-19 00:56:09 | ESP_1 | 3.55 | 574.38 | OK
2026-02-19 00:56:09 | ESP_3 | 3.48 | 597.5 | OK
2026-02-19 00:57:09 | ESP_1 | 3.54 | 603.75 | OK
2026-02-19 00:57:09 | ESP_3 | 3.47 | 607.5 | OK
2026-02-19 00:58:09 | ESP_1 | 3.55 | 545.62 | OK
2026-02-19 00:58:09 | ESP_3 | 3.46 | 611.88 | OK
2026-02-19 00:59:09 | ESP_1 | 3.54 | 597.5 | OK
2026-02-19 00:59:09 | ESP_3 | 3.49 | 546.87 | OK
2026-02-19 01:00:09 | ESP_1 | 3.53 | 604.38 | OK
2026-02-19 01:00:09 | ESP_3 | 3.48 | 591.88 | OK
2026-02-19 01:01:09 | ESP_1 | 3.55 | 575.62 | OK
2026-02-19 01:01:09 | ESP_3 | 3.47 | 624.38 | OK
2026-02-19 01:02:09 | ESP_1 | 3.54 | 610.0 | OK
2026-02-19 01:02:09 | ESP_3 | 3.48 | 596.25 | OK
2026-02-19 01:03:09 | ESP_1 | 3.55 | 578.12 | OK
2026-02-19 01:03:09 | ESP_3 | 3.49 | 586.88 | OK
2026-02-19 01:04:09 | ESP_1 | 3.53 | 597.5 | OK
2026-02-19 01:04:09 | ESP_3 | 3.49 | 600.0 | OK
2026-02-19 01:05:09 | ESP_1 | 3.55 | 575.62 | OK
2026-02-19 01:05:09 | ESP_3 | 3.47 | 609.37 | OK
2026-02-19 01:06:09 | ESP_1 | 3.54 | 611.25 | OK
2026-02-19 01:06:09 | ESP_3 | 3.5 | 560.0 | OK
2026-02-19 01:07:09 | ESP_1 | 3.54 | 588.75 | OK
2026-02-19 01:07:09 | ESP_3 | 3.49 | 588.12 | OK
2026-02-19 01:08:09 | ESP_1 | 3.54 | 591.25 | OK
2026-02-19 01:08:09 | ESP_3 | 3.48 | 604.38 | OK
2026-02-19 01:09:09 | ESP_1 | 3.55 | 545.62 | OK
2026-02-19 01:09:09 | ESP_3 | 3.48 | 615.62 | OK
2026-02-19 01:10:09 | ESP_1 | 3.54 | 595.62 | OK
2026-02-19 01:10:09 | ESP_3 | 3.49 | 589.37 | OK
2026-02-19 01:11:09 | ESP_1 | 3.56 | 569.37 | OK
2026-02-19 01:11:09 | ESP_3 | 3.47 | 611.88 | OK
2026-02-19 01:12:09 | ESP_1 | 3.54 | 595.0 | OK
2026-02-19 01:12:09 | ESP_3 | 3.5 | 540.0 | OK
2026-02-19 01:13:09 | ESP_1 | 3.55 | 578.12 | OK
2026-02-19 01:13:09 | ESP_3 | 3.47 | 631.87 | OK
2026-02-19 01:14:09 | ESP_1 | 3.55 | 603.12 | OK
2026-02-19 01:14:09 | ESP_3 | 3.48 | 602.5 | OK
2026-02-19 01:15:09 | ESP_1 | 3.55 | 583.75 | OK
2026-02-19 01:15:09 | ESP_3 | 3.48 | 617.5 | OK
2026-02-19 01:16:09 | ESP_1 | 3.55 | 588.75 | OK
2026-02-19 01:16:09 | ESP_3 | 3.49 | 586.25 | OK
2026-02-19 01:17:09 | ESP_1 | 3.55 | 590.62 | OK
2026-02-19 01:17:09 | ESP_3 | 3.48 | 611.88 | OK
2026-02-19 01:18:09 | ESP_1 | 3.57 | 545.62 | OK
2026-02-19 01:18:09 | ESP_3 | 3.48 | 618.75 | OK
2026-02-19 01:19:09 | ESP_1 | 3.55 | 605.0 | OK
2026-02-19 01:19:09 | ESP_3 | 3.48 | 603.75 | OK
2026-02-19 01:20:09 | ESP_1 | 3.56 | 574.38 | OK
2026-02-19 01:20:09 | ESP_3 | 3.47 | 618.13 | OK
2026-02-19 01:21:09 | ESP_1 | 3.54 | 590.62 | OK
2026-02-19 01:21:09 | ESP_3 | 3.49 | 558.75 | OK
2026-02-19 01:22:09 | ESP_1 | 3.56 | 582.5 | OK
2026-02-19 01:22:09 | ESP_3 | 3.49 | 585.63 | OK
2026-02-19 01:23:09 | ESP_1 | 3.57 | 574.38 | OK
2026-02-19 01:23:09 | ESP_3 | 3.48 | 632.5 | OK
2026-02-19 01:24:09 | ESP_1 | 3.55 | 607.5 | OK
2026-02-19 01:24:09 | ESP_3 | 3.48 | 629.38 | OK
2026-02-19 01:25:09 | ESP_1 | 3.55 | 601.87 | OK
2026-02-19 01:25:09 | ESP_3 | 3.49 | 585.63 | OK
2026-02-19 01:26:09 | ESP_1 | 3.56 | 543.13 | OK
2026-02-19 01:26:09 | ESP_3 | 3.48 | 610.63 | OK
2026-02-19 01:27:09 | ESP_1 | 3.56 | 543.13 | OK
2026-02-19 01:27:09 | ESP_3 | 3.48 | 608.12 | OK
2026-02-19 01:28:09 | ESP_1 | 3.54 | 605.63 | OK
2026-02-19 01:28:09 | ESP_3 | 3.49 | 588.75 | OK
2026-02-19 01:29:09 | ESP_1 | 3.55 | 572.5 | OK
2026-02-19 01:29:09 | ESP_3 | 3.48 | 603.12 | OK
2026-02-19 01:30:09 | ESP_1 | 3.55 | 587.5 | OK
2026-02-19 01:30:09 | ESP_3 | 3.48 | 621.87 | OK
2026-02-19 01:31:09 | ESP_1 | 3.54 | 603.75 | OK
2026-02-19 01:31:09 | ESP_3 | 3.5 | 558.12 | OK
2026-02-19 01:32:09 | ESP_1 | 3.55 | 571.25 | OK
2026-02-19 01:32:09 | ESP_3 | 3.5 | 558.12 | OK
2026-02-19 01:33:09 | ESP_1 | 3.55 | 568.75 | OK
2026-02-19 01:33:09 | ESP_3 | 3.48 | 595.62 | OK
2026-02-19 01:34:09 | ESP_1 | 3.54 | 598.75 | OK
2026-02-19 01:34:09 | ESP_3 | 3.47 | 610.0 | OK
2026-02-19 01:35:09 | ESP_1 | 3.59 | 482.5 | OK
2026-02-19 01:35:09 | ESP_3 | 3.48 | 582.5 | OK
2026-02-19 01:36:09 | ESP_1 | 3.54 | 578.12 | OK
2026-02-19 01:36:09 | ESP_3 | 3.47 | 621.87 | OK
2026-02-19 01:37:09 | ESP_1 | 3.54 | 586.25 | OK
2026-02-19 01:37:09 | ESP_3 | 3.48 | 615.62 | OK
2026-02-19 01:38:09 | ESP_1 | 3.55 | 572.5 | OK
2026-02-19 01:38:09 | ESP_3 | 3.48 | 600.0 | OK
2026-02-19 01:39:09 | ESP_1 | 3.55 | 586.25 | OK
2026-02-19 01:39:09 | ESP_3 | 3.48 | 586.88 | OK
2026-02-19 01:40:09 | ESP_1 | 3.54 | 594.37 | OK
2026-02-19 01:40:09 | ESP_3 | 3.48 | 604.38 | OK
2026-02-19 01:41:09 | ESP_1 | 3.55 | 579.38 | OK
2026-02-19 01:41:09 | ESP_3 | 3.47 | 610.0 | OK
2026-02-19 01:42:09 | ESP_1 | 3.55 | 573.13 | OK
2026-02-19 01:42:09 | ESP_3 | 3.48 | 585.63 | OK
2026-02-19 01:43:09 | ESP_1 | 3.54 | 600.0 | OK
2026-02-19 01:43:09 | ESP_3 | 3.46 | 625.62 | OK
2026-02-19 01:44:09 | ESP_1 | 3.55 | 580.0 | OK
2026-02-19 01:44:09 | ESP_3 | 3.47 | 617.5 | OK
2026-02-19 01:45:09 | ESP_1 | 3.55 | 571.87 | OK
2026-02-19 01:45:09 | ESP_3 | 3.48 | 590.62 | OK
2026-02-19 01:46:09 | ESP_1 | 3.54 | 604.38 | OK
2026-02-19 01:46:09 | ESP_3 | 3.47 | 611.88 | OK
2026-02-19 01:47:09 | ESP_1 | 3.54 | 586.25 | OK
2026-02-19 01:47:09 | ESP_3 | 3.47 | 615.0 | OK
2026-02-19 01:48:09 | ESP_1 | 3.55 | 570.0 | OK
2026-02-19 01:48:09 | ESP_3 | 3.48 | 586.25 | OK
2026-02-19 01:49:09 | ESP_1 | 3.54 | 558.75 | OK
2026-02-19 01:49:09 | ESP_3 | 3.47 | 602.5 | OK
2026-02-19 01:50:09 | ESP_1 | 3.54 | 598.13 | OK
2026-02-19 01:50:09 | ESP_3 | 3.47 | 606.87 | OK
2026-02-19 01:51:09 | ESP_1 | 3.54 | 589.37 | OK
2026-02-19 01:51:09 | ESP_3 | 3.48 | 585.63 | OK
2026-02-19 01:52:09 | ESP_1 | 3.54 | 603.75 | OK
2026-02-19 01:52:09 | ESP_3 | 3.47 | 618.13 | OK
2026-02-19 01:53:09 | ESP_1 | 3.54 | 584.37 | OK
2026-02-19 01:53:09 | ESP_3 | 3.47 | 614.37 | OK
2026-02-19 01:54:09 | ESP_1 | 3.53 | 592.5 | OK
2026-02-19 01:54:09 | ESP_3 | 3.47 | 609.37 | OK
2026-02-19 01:55:09 | ESP_1 | 3.54 | 578.12 | OK
2026-02-19 01:55:09 | ESP_3 | 3.47 | 602.5 | OK
2026-02-19 01:56:09 | ESP_1 | 3.56 | 518.75 | OK
2026-02-19 01:56:09 | ESP_3 | 3.47 | 593.13 | OK
2026-02-19 01:57:09 | ESP_1 | 3.53 | 600.62 | OK
2026-02-19 01:57:09 | ESP_3 | 3.48 | 585.0 | OK
2026-02-19 01:58:09 | ESP_1 | 3.54 | 576.87 | OK
2026-02-19 01:58:09 | ESP_3 | 3.47 | 611.25 | OK
2026-02-19 01:59:09 | ESP_1 | 3.56 | 496.25 | OK
2026-02-19 01:59:09 | ESP_3 | 3.48 | 581.87 | OK
2026-02-19 02:00:09 | ESP_1 | 3.53 | 601.87 | OK
2026-02-19 02:00:09 | ESP_3 | 3.48 | 595.0 | OK
2026-02-19 02:01:09 | ESP_1 | 3.53 | 588.75 | OK
2026-02-19 02:01:09 | ESP_3 | 3.46 | 608.75 | OK
2026-02-19 02:02:09 | ESP_1 | 3.54 | 571.87 | OK
2026-02-19 02:02:09 | ESP_3 | 3.49 | 585.63 | OK
2026-02-19 02:03:09 | ESP_1 | 3.53 | 601.25 | OK
2026-02-19 02:03:09 | ESP_3 | 3.47 | 605.0 | OK
2026-02-19 02:04:09 | ESP_1 | 3.52 | 589.37 | OK
2026-02-19 02:04:09 | ESP_3 | 3.46 | 616.88 | OK
2026-02-19 02:05:09 | ESP_1 | 3.52 | 574.38 | OK
2026-02-19 02:05:09 | ESP_3 | 3.47 | 585.63 | OK
2026-02-19 02:06:09 | ESP_1 | 3.53 | 540.0 | OK
2026-02-19 02:06:09 | ESP_3 | 3.46 | 609.37 | OK
2026-02-19 02:07:09 | ESP_1 | 3.51 | 591.88 | OK
2026-02-19 02:07:09 | ESP_3 | 3.48 | 566.88 | OK
2026-02-19 02:08:09 | ESP_1 | 3.51 | 584.37 | OK
2026-02-19 02:08:09 | ESP_3 | 3.47 | 595.62 | OK
2026-02-19 02:09:09 | ESP_1 | 3.52 | 548.13 | OK
2026-02-19 02:09:09 | ESP_3 | 3.46 | 609.37 | OK
2026-02-19 02:10:09 | ESP_1 | 3.5 | 593.75 | OK
2026-02-19 02:10:09 | ESP_3 | 3.47 | 585.0 | OK
2026-02-19 02:11:09 | ESP_1 | 3.52 | 571.87 | OK
2026-02-19 02:11:09 | ESP_3 | 3.46 | 606.25 | OK
2026-02-19 02:12:09 | ESP_1 | 3.51 | 612.5 | OK
2026-02-19 02:12:09 | ESP_3 | 3.46 | 596.87 | OK
2026-02-19 02:13:09 | ESP_1 | 3.51 | 590.62 | OK
2026-02-19 02:13:09 | ESP_3 | 3.46 | 596.87 | OK
2026-02-19 02:14:09 | ESP_1 | 3.53 | 538.12 | OK
2026-02-19 02:14:09 | ESP_3 | 3.45 | 605.63 | OK
2026-02-19 02:15:09 | ESP_1 | 3.5 | 590.0 | OK
2026-02-19 02:15:09 | ESP_3 | 3.47 | 585.0 | OK
2026-02-19 02:16:09 | ESP_1 | 3.51 | 596.87 | OK
2026-02-19 02:16:09 | ESP_3 | 3.46 | 601.25 | OK
2026-02-19 02:17:09 | ESP_1 | 3.5 | 590.0 | OK
2026-02-19 02:17:09 | ESP_3 | 3.46 | 576.25 | OK
2026-02-19 02:18:09 | ESP_1 | 3.51 | 572.5 | OK
2026-02-19 02:18:09 | ESP_3 | 3.46 | 586.25 | OK
2026-02-19 02:19:09 | ESP_1 | 3.49 | 599.38 | OK
2026-02-19 02:19:09 | ESP_3 | 3.45 | 623.13 | OK
2026-02-19 02:20:09 | ESP_1 | 3.51 | 575.0 | OK
2026-02-19 02:20:09 | ESP_3 | 3.46 | 584.37 | OK
2026-02-19 02:53:50 | ESP_1 | 3.46 | 583.12 | OK
2026-02-19 02:53:50 | ESP_3 | 2.56 | 566.88 | OK
2026-02-19 02:53:50 | ESP_5 |  |  | OK
2026-02-19 02:54:50 | ESP_1 | 3.47 | 588.12 | OK
2026-02-19 02:54:50 | ESP_3 | 2.56 | 566.88 | OK
2026-02-19 02:54:50 | ESP_5 |  |  | OK
2026-02-19 02:55:50 | ESP_1 | 3.47 | 584.37 | OK
2026-02-19 02:55:50 | ESP_5 |  |  | OK
2026-02-19 02:56:50 | ESP_1 | 3.48 | 589.37 | OK
2026-02-19 02:56:50 | ESP_5 |  |  | OK
2026-02-19 02:57:50 | ESP_1 | 3.48 | 593.13 | OK
2026-02-19 02:57:50 | ESP_5 |  |  | OK
2026-02-19 02:58:50 | ESP_1 | 3.49 | 571.25 | OK
2026-02-19 02:58:50 | ESP_5 |  |  | OK
2026-02-19 02:59:50 | ESP_1 | 3.49 | 563.12 | OK
2026-02-19 02:59:50 | ESP_5 |  |  | OK
2026-02-19 03:00:50 | ESP_1 | 3.49 | 567.5 | OK
2026-02-19 03:00:50 | ESP_5 |  |  | OK
2026-02-19 03:01:50 | ESP_1 | 3.46 | 624.38 | OK
2026-02-19 03:01:50 | ESP_5 |  |  | OK
2026-02-19 03:02:50 | ESP_1 | 3.47 | 582.5 | OK
2026-02-19 03:02:50 | ESP_3 | 2.58 | 545.62 | OK
2026-02-19 03:02:50 | ESP_5 |  |  | OK
2026-02-19 03:03:50 | ESP_1 | 3.45 | 619.37 | OK
2026-02-19 03:03:50 | ESP_3 | 3.23 | 611.88 | OK
2026-02-19 03:03:50 | ESP_5 |  |  | OK
2026-02-19 03:04:50 | ESP_1 | 3.46 | 603.75 | OK
2026-02-19 03:04:50 | ESP_3 | 2.88 | 634.37 | OK
2026-02-19 03:04:50 | ESP_5 |  |  | OK
2026-02-19 03:05:50 | ESP_1 | 3.46 | 603.75 | OK
2026-02-19 03:05:50 | ESP_3 | 2.53 | 582.5 | OK
2026-02-19 03:05:50 | ESP_5 |  |  | OK
2026-02-19 03:06:50 | ESP_1 | 3.48 | 572.5 | OK
2026-02-19 03:06:50 | ESP_3 | 2.53 | 582.5 | OK
2026-02-19 03:06:50 | ESP_5 |  |  | OK
2026-02-19 03:07:50 | ESP_1 | 3.48 | 567.5 | OK
2026-02-19 03:07:50 | ESP_5 |  |  | OK
2026-02-19 03:08:50 | ESP_1 | 3.46 | 606.25 | OK
2026-02-19 03:08:50 | ESP_5 |  |  | OK
2026-02-19 03:09:50 | ESP_1 | 3.45 | 621.25 | OK
2026-02-19 03:09:50 | ESP_5 |  |  | OK
2026-02-19 03:10:50 | ESP_1 | 3.45 | 571.25 | OK
2026-02-19 03:10:50 | ESP_5 |  |  | OK
2026-02-19 03:11:50 | ESP_1 | 3.48 | 576.25 | OK
2026-02-19 03:11:50 | ESP_5 |  |  | OK
2026-02-19 03:12:50 | ESP_1 | 3.48 | 571.25 | OK
2026-02-19 03:12:50 | ESP_5 |  |  | OK
2026-02-19 03:13:50 | ESP_1 | 3.48 | 571.87 | OK
2026-02-19 03:13:50 | ESP_5 |  |  | OK
2026-02-19 03:14:50 | ESP_1 | 3.48 | 571.25 | OK
2026-02-19 03:14:50 | ESP_5 |  |  | OK
2026-02-19 03:15:50 | ESP_1 | 3.47 | 609.37 | OK
2026-02-19 03:15:50 | ESP_5 |  |  | OK
2026-02-19 03:16:50 | ESP_1 | 3.46 | 608.12 | OK
2026-02-19 03:16:50 | ESP_5 |  |  | OK
2026-02-19 03:17:50 | ESP_1 | 3.44 | 634.37 | OK
2026-02-19 03:17:50 | ESP_5 |  |  | OK
2026-02-19 03:18:50 | ESP_1 | 3.45 | 625.0 | OK
2026-02-19 03:18:50 | ESP_5 |  |  | OK
2026-02-19 03:19:50 | ESP_1 | 3.49 | 524.38 | OK
2026-02-19 03:19:50 | ESP_5 |  |  | OK
2026-02-19 03:20:50 | ESP_1 | 3.47 | 570.62 | OK
2026-02-19 03:20:50 | ESP_5 |  |  | OK
2026-02-19 03:21:50 | ESP_1 | 3.45 | 637.5 | OK
2026-02-19 03:21:50 | ESP_5 |  |  | OK
2026-02-19 04:11:12 | ESP_1 | 3.22 | 595.0 | OK
2026-02-19 04:11:12 | ESP_3 | 3.46 | 610.0 | OK
2026-02-19 04:11:12 | ESP_5 |  |  | OK
2026-02-19 04:23:29 | ESP_1 | 3.34 | 621.87 | OK
2026-02-19 04:23:29 | ESP_3 | 3.51 | 628.12 | OK
2026-02-19 04:23:29 | ESP_5 |  |  | OK
2026-02-19 04:24:29 | ESP_1 | 3.34 | 628.12 | OK
2026-02-19 04:24:29 | ESP_3 | 3.54 | 511.88 | OK
2026-02-19 04:24:29 | ESP_5 |  |  | OK
2026-02-19 04:25:29 | ESP_1 | 3.37 | 582.5 | OK
2026-02-19 04:25:29 | ESP_3 | 3.51 | 623.13 | OK
2026-02-19 04:25:29 | ESP_5 |  |  | OK
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

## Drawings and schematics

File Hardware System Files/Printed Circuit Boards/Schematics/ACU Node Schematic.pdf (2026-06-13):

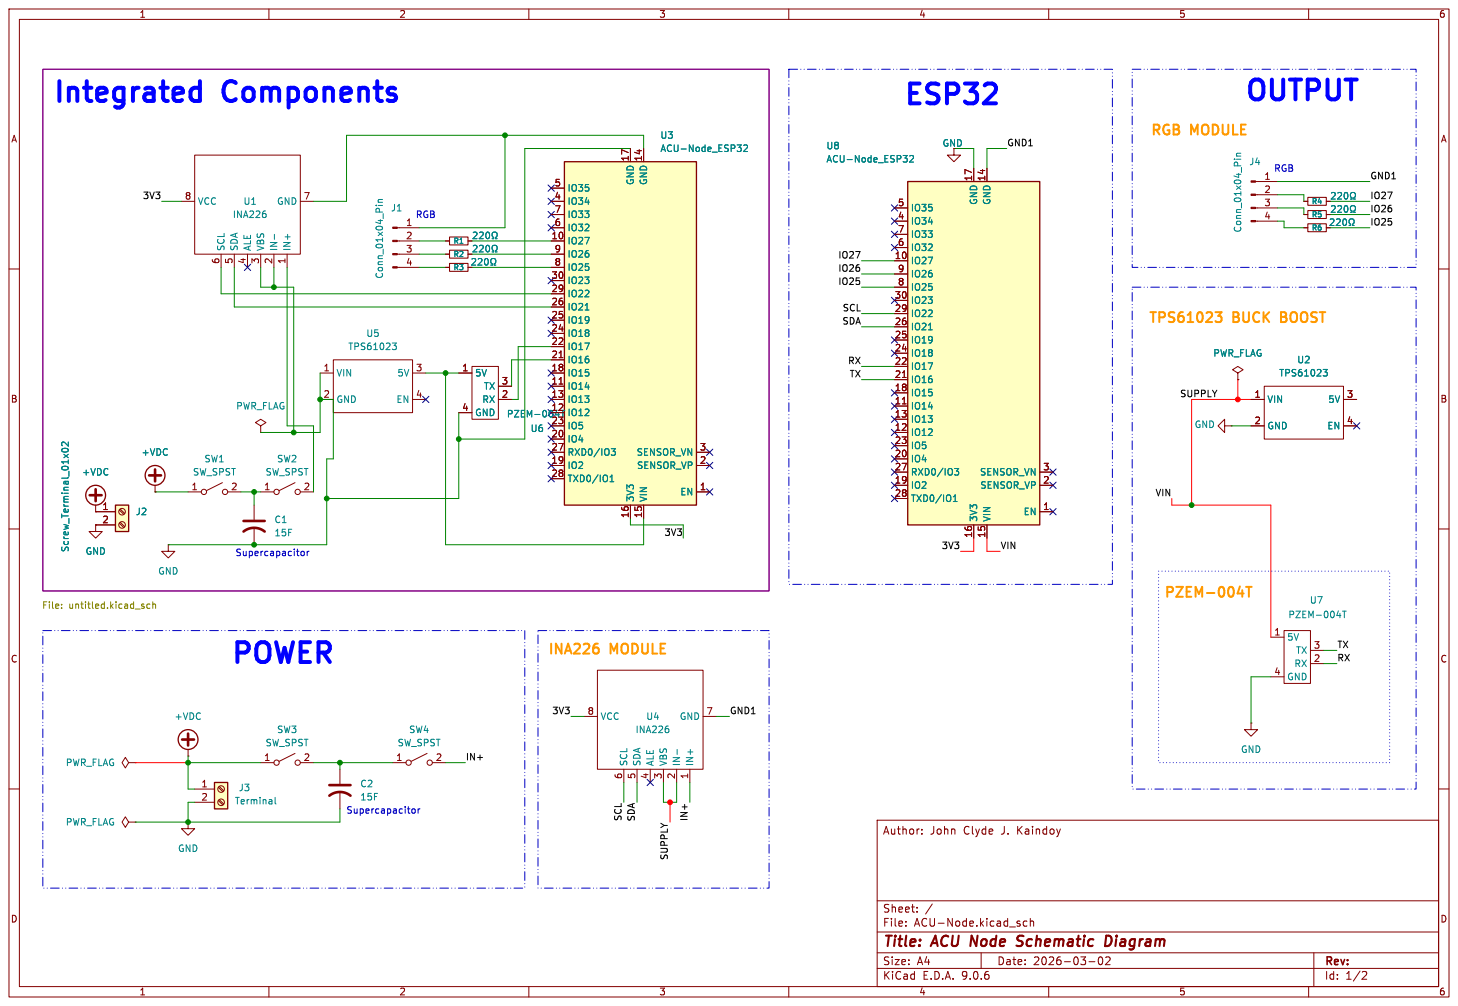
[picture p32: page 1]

Id: 1/2 Title: ACU Node Schematic Diagram

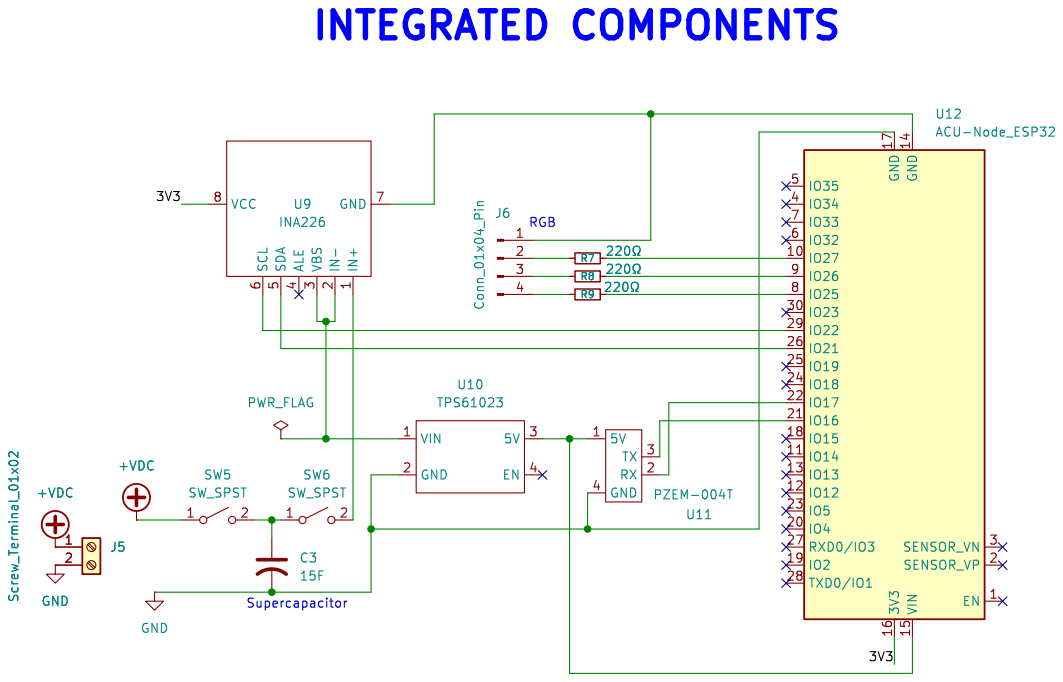
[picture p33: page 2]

5V 3 EN 4 U10 TPS61023 R8 þÿ220© | IO21 26

Id: 2/2 Title: Schematic Diagram for Integrated Components

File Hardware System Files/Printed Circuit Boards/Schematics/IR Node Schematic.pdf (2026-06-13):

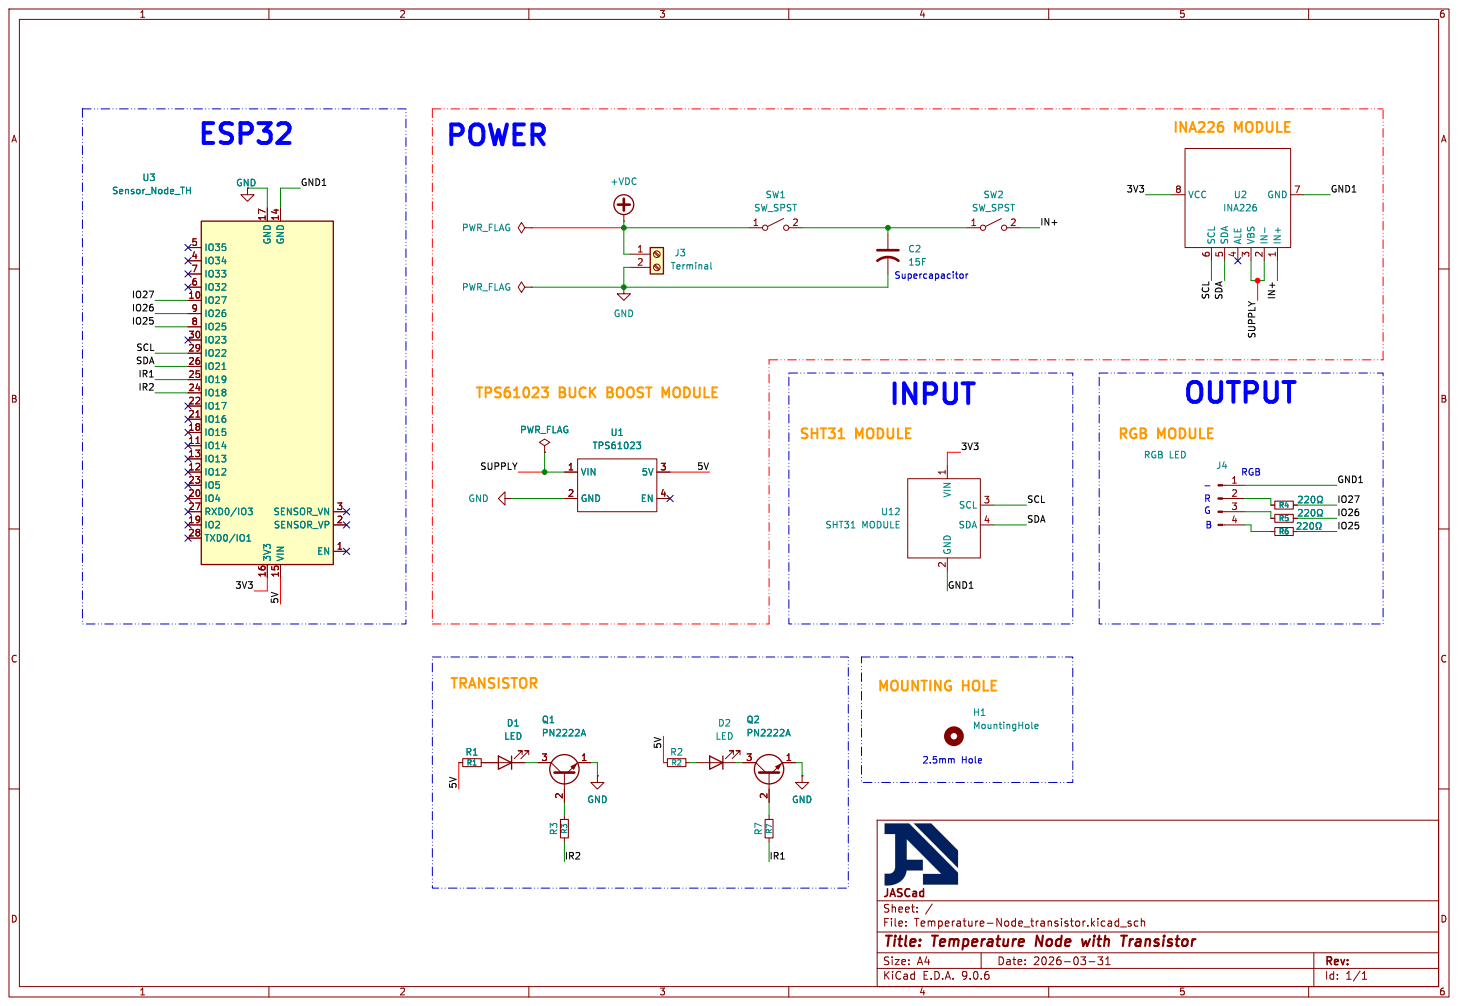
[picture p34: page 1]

2 SCL 3 SDA 4 U12 SHT31 MODULE GND

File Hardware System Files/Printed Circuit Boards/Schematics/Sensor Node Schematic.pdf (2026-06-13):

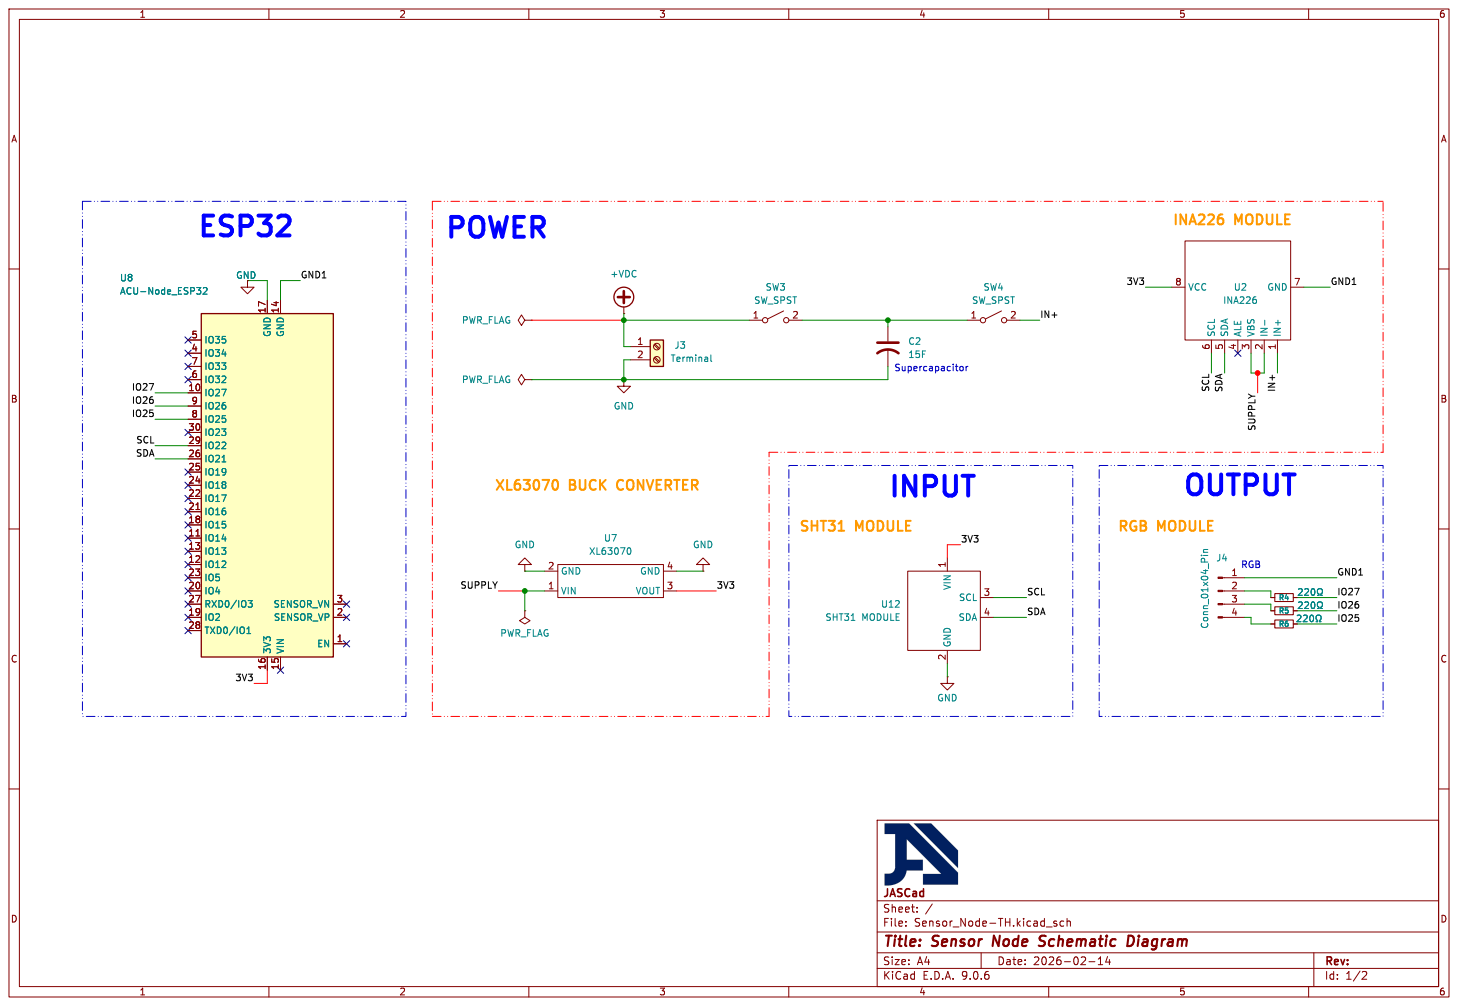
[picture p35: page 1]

File: Sensor_Node-TH.kicad_sch Sheet: / JASCad

Id: 1/2 Title: Sensor Node Schematic Diagram

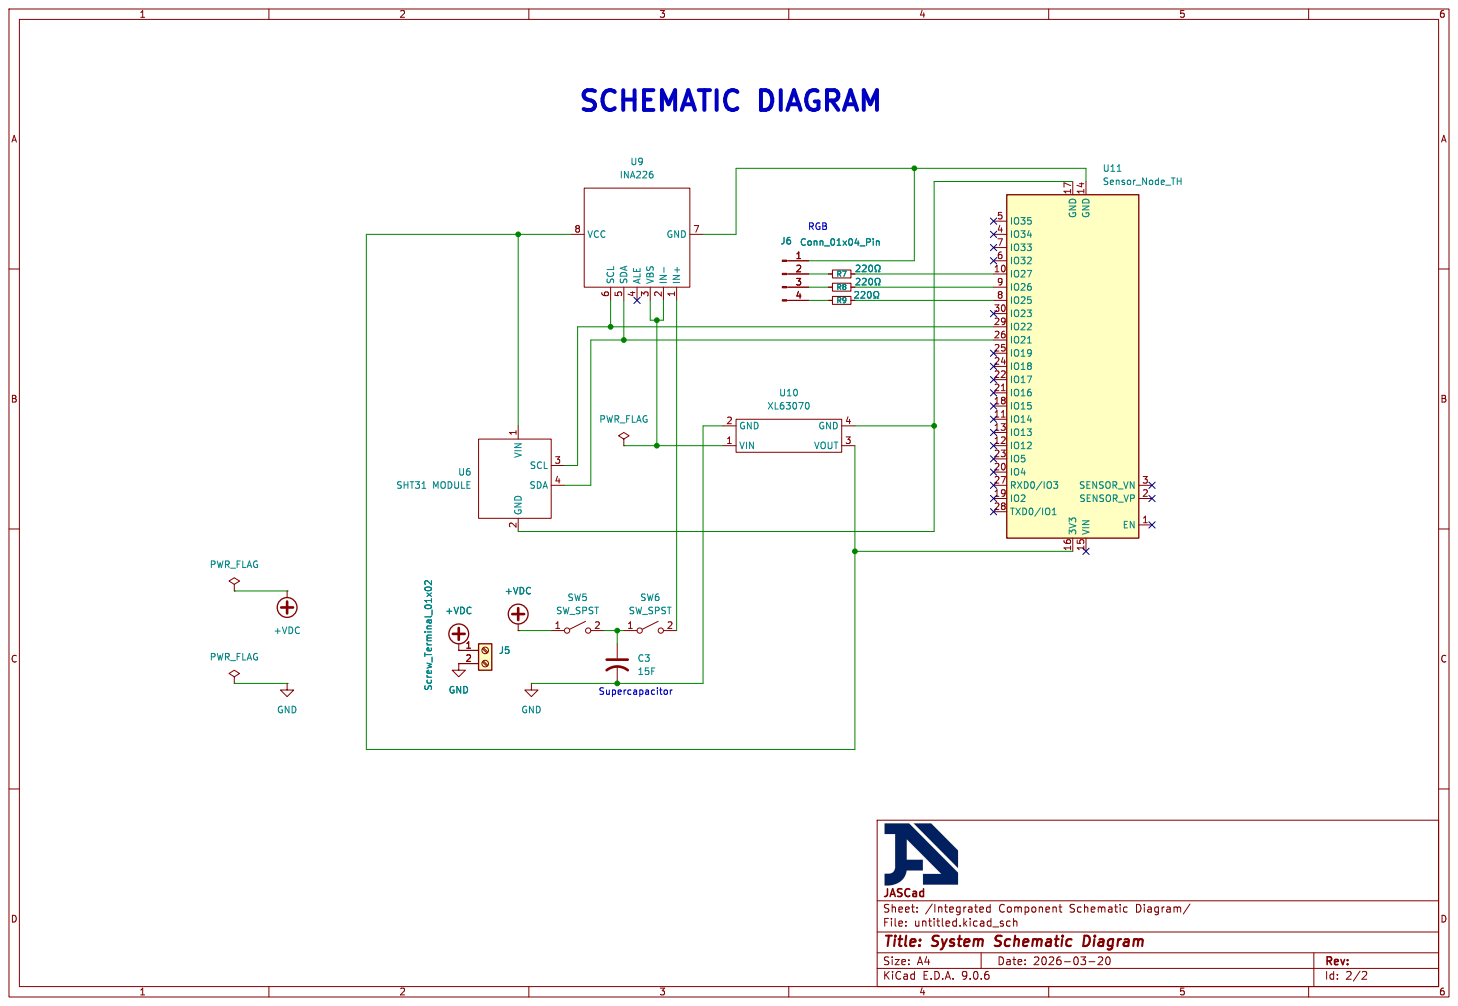
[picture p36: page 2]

2 SCL 3 SDA 4 U6 SHT31 MODULE GND

Id: 2/2 Title: System Schematic Diagram

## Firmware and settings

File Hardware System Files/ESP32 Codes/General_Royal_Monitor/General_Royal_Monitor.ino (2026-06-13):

#include <WiFi.h>
#include <PubSubClient.h>
#include <PZEM004Tv30.h>
#include <INA226_WE.h>
#include <ESPmDNS.h>
#include <Wire.h> 

// ================= WIFI =================
const char* ssid = "TP-Link_95CC";
const char* password = "11018605";

// ================= MQTT =================
const char* mqtt_hostname = "cvmpi";
const int mqtt_port = 1883;
const char* mqtt_client_id = "ESP32_InsideSensor5";

const char* ac_power   = "/ac/power5";
const char* voltage_topic = "/esp/voltage5";
const char* power_topic   = "/esp/power5";
const char* status_topic  = "/esp/status5";

// ✅ ADDED: Heartbeat Topic for LED State Machine
const char* master_heartbeat_topic = "/master/heartbeat";

const unsigned long send_interval = 30000;

// ================= WIFI RETRY =================
const unsigned long WIFI_TIMEOUT_MS = 10000;
const int WIFI_MAX_RETRIES = 2;

// ================= RGB LED =================
#define LED_RED    27
#define LED_GREEN  26
#define LED_BLUE   25

// ✅ ADDED: LED PWM settings for color mixing
#define LED_FREQ 5000
#define LED_RES    8

// ================= INA226 =================
#define INA226_ADDR 0x40
INA226_WE ina226 = INA226_WE(INA226_ADDR);

// ================= PZEM =================
HardwareSerial pzemSerial(2);
PZEM004Tv30 pzem(pzemSerial, 16, 17);

// ================= GLOBALS =================
IPAddress mqtt_server_ip;
WiFiClient espClient;
PubSubClient mqttClient(espClient);

bool pzem_ok = false;
bool ina_ok = false;
bool mqtt_available = false;

unsigned long previousMillis = 0; 

// ✅ ADDED: LED State Machine Variables
float voltage_avg = 0;
unsigned long last_master_heartbeat = 0;
bool master_alive = false;

// ================= FUNCTION DECLARATIONS =================
void setLED(uint32_t color);
void updateLED(float voltage);
void connectWiFi();
void discoverMQTTBroker();
void connectMQTT();

// ================= MQTT LISTENER =================
// ✅ ADDED: Triggers instantly to update master_alive for the LED
void mqttCallback(char* topic, byte* payload, unsigned int length) {
  String msg = "";
  for (int i = 0; i < length; i++) {
    msg += (char)payload[i];
  }

  if (String(topic) == String(master_heartbeat_topic)) {
    if (msg == "ONLINE") {
      last_master_heartbeat = millis();
      master_alive = true;
    } 
    else if (msg == "OFFLINE") {
      master_alive = false; 
    }
  }
}

// ================= SETUP =================
void setup() {

  Serial.begin(115200);
  delay(1000);

  Serial.println("\n=== ESP32 SENSOR SYSTEM STARTING ===");

  // ✅ UPDATED: PWM setup for precise colors instead of basic pinMode
  ledcAttach(LED_RED, LED_FREQ, LED_RES);
  ledcAttach(LED_GREEN, LED_FREQ, LED_RES);
  ledcAttach(LED_BLUE, LED_FREQ, LED_RES);
  setLED(0x000000); // Start OFF

  Wire.begin(); 

  connectWiFi();

  if (MDNS.begin("ESP32Sensor")) {
    Serial.println("[MDNS] Started as ESP32Sensor.local");
  }

  discoverMQTTBroker();
  mqttClient.setServer(mqtt_server_ip, mqtt_port);
  mqttClient.setCallback(mqttCallback); // ✅ ADDED: Link callback

  Serial.println("[SYSTEM] Boot complete\n");
}

// ================= LOOP =================
void loop() {

  // ===== WIFI & MQTT MAINTENANCE (Runs instantly, every loop) =====
  if (WiFi.status() != WL_CONNECTED) {
    Serial.println("[WIFI] Disconnected. Reconnecting...");
    connectWiFi();
    discoverMQTTBroker();
    mqttClient.setServer(mqtt_server_ip, mqtt_port);
  } 
  
  if (!mqttClient.connected() && WiFi.status() == WL_CONNECTED) {
    Serial.println("[MQTT] Not connected. Reconnecting...");
    discoverMQTTBroker();
    mqttClient.setServer(mqtt_server_ip, mqtt_port);
    connectMQTT();
  } 

  mqttClient.loop(); 

  // ✅ ADDED: Check if Master Controller heartbeat flatlined (> 15 seconds)
  if (millis() - last_master_heartbeat > 15000) {
    master_alive = false; 
  }

  // ===== NON-BLOCKING SENSOR TIMER (Runs every 30 seconds) =====
  unsigned long currentMillis = millis();
  
  if (currentMillis - previousMillis >= send_interval) {
    previousMillis = currentMillis;

    Serial.println("\n====== SENSOR READ START ======");

    // ===== SENSOR CHECK =====
    float volt = pzem.voltage();
    float amp  = pzem.current();

    if (!isnan(volt) && !isnan(amp)) {
      if (!pzem_ok) Serial.println("[PZEM] FUNCTIONAL - GOOD");
      pzem_ok = true;
    } else {
      if (pzem_ok) Serial.println("[PZEM] FAILED");
      pzem_ok = false;
    }

    if (!ina_ok) {
      Serial.println("[INA226] Trying to initialize...");
      if (ina226.init()) {
        ina226.setAverage(INA226_AVERAGE_16);
        ina226.setConversionTime(INA226_CONV_TIME_1100);
        ina226.setMeasureMode(INA226_CONTINUOUS);
        ina_ok = true;
        Serial.println("[INA226] FUNCTIONAL - GOOD");
      } else {
        Serial.println("[INA226] INIT FAILED");
      }
    }

    float voltage = NAN;
    float power   = NAN;

    if (ina_ok) {
      voltage = ina226.getBusVoltage_V();
      power   = ina226.getBusPower();

      if (isnan(voltage) || isnan(power)) {
        Serial.println("[INA226] READ FAILED ERROR");
        ina_ok = false;
      } else {
        // ✅ ADDED: Weighted average filter for stable LED colors
        if (voltage_avg == 0) {
          voltage_avg = voltage;
        } else {
          voltage_avg = (voltage_avg * 9 + voltage) / 10;
        }
      }
    }

    // ===== STATUS PRINT =====
    Serial.print("[STATUS] PZEM: ");
    Serial.print(pzem_ok ? "OK" : "FAIL");
    Serial.print(" | INA226: ");
    Serial.print(ina_ok ? "OK" : "FAIL");
    Serial.print(" | MQTT: ");
    Serial.println(mqtt_available ? "OK" : "FAIL");

    // ===== LOGIC =====
    // ❌ REMOVED: Blocking LED calls (blinkGreen, blinkRed, updateLED) from here
    if (mqtt_available) {

      // ===== ALL OK =====
      if (pzem_ok && ina_ok) {
        Serial.println("[MODE] ALL OK");

        float ac_calc_pow = volt * amp;

        Serial.printf("[DATA] AC_V: %.2f | AC_I: %.2f | AC_P: %.2f\n", volt, amp, ac_calc_pow);
        Serial.printf("[DATA] INA_V: %.2f | INA_P: %.2f\n", voltage, power);

        mqttClient.publish(ac_power, String(ac_calc_pow, 2).c_str());
        mqttClient.publish(voltage_topic, String(voltage, 2).c_str());
        mqttClient.publish(power_topic, String(power, 2).c_str());
        mqttClient.publish(status_topic, "OK");

        Serial.println("[MQTT] Published ALL data");
      }

      // ===== PZEM OK, INA FAIL =====
      else if (pzem_ok && !ina_ok) {
        Serial.println("[MODE] INA FAIL, PZEM OK");

        float ac_calc_pow = volt * amp;

        Serial.printf("[DATA] AC_V: %.2f | AC_I: %.2f | AC_P: %.2f\n", volt, amp, ac_calc_pow);

        mqttClient.publish(ac_power, String(ac_calc_pow, 2).c_str());
        mqttClient.publish(status_topic, "ERROR: INA226_FAIL");

        Serial.println("[MQTT] Published PZEM only");
      }

      // ===== INA OK, PZEM FAIL =====
      else if (!pzem_ok && ina_ok) {
        Serial.println("[MODE] PZEM FAIL (But INA OK)");

        mqttClient.publish(voltage_topic, String(voltage, 2).c_str());
        mqttClient.publish(power_topic, String(power, 2).c_str());
        mqttClient.publish(status_topic, "ERROR: PZEM_FAIL");

        Serial.println("[MQTT] Published INA data + PZEM Error");
      }

      // ===== BOTH FAIL =====
      else {
        Serial.println("[MODE] BOTH SENSORS FAIL");
        mqttClient.publish(status_topic, "ERROR: PZEM_FAIL INA226_FAIL");
        Serial.println("[MQTT] Status only (ALL FAIL)");
      }

    } else {
      Serial.println("[MQTT] Not available — skipping publish");
    }

    Serial.println("====== SENSOR READ END ======\n");
  } 

  // ===== VISUAL STATE MACHINE (LED INDICATORS) =====
  // ✅ ADDED: Runs continuously without blocking the ESP32
  
  if (WiFi.status() != WL_CONNECTED || !mqttClient.connected()) {
    // 🔵 BLINK BLUE: Network / MQTT Drop
    static unsigned long lastNetBlink = 0;
    static bool netLed = false;
    if (millis() - lastNetBlink >= 300) {
      lastNetBlink = millis();
      netLed = !netLed;
      setLED(netLed ? 0x0000FF : 0x000000); 
    }
  } 
  else if (!pzem_ok || !ina_ok) { // ✅ UPDATED: tailored to the PZEM/INA226 sensors
    // 🔴 BLINK RED: Physical Hardware / Sensor Failure
    static unsigned long lastHwBlink = 0;
    static bool hwLed = false;
    if (millis() - lastHwBlink >= 300) {
      lastHwBlink = millis();
      hwLed = !hwLed;
      setLED(hwLed ? 0xFF0000 : 0x000000);
    }
  } 
  else if (!master_alive) {
    // 🔵🔌 SLOW ALTERNATING: Master Python Script is DEAD
    static unsigned long lastMasterDeadBlink = 0;
    static bool showBlue = true;
    if (millis() - lastMasterDeadBlink >= 1000) {
      lastMasterDeadBlink = millis();
      showBlue = !showBlue;
      
      if (showBlue) {
        setLED(0x0000FF); 
      } else {
        updateLED(voltage_avg); 
      }
    }
  }
  else {
    // 🔋 SOLID COLOR: System Healthy
    updateLED(voltage_avg);
  }

} // End of loop

// ================= LED NORMAL MODE =================
// ✅ UPDATED: Adapted to the new reference format
void updateLED(float voltage) {
  if (voltage > 3.9) {
    setLED(0x00FF00);   // Green
  }
  else if (voltage > 3.6) {
    setLED(0xFFFF00);   // Yellow
  }
  else if (voltage > 3.4) {
    setLED(0xFF8000);   // Orange
  }
  else {
    setLED(0xFF0000);   // Red
  }
}

// ================= LED FUNCTION =================
// ✅ ADDED: New setLED helper using PWM
void setLED(uint32_t color) {
  uint8_t r = (color >> 16) & 0xFF;
  uint8_t g = (color >> 8) & 0xFF;
  uint8_t b = color & 0xFF;

  ledcWrite(LED_RED, r);
  ledcWrite(LED_GREEN, g);
  ledcWrite(LED_BLUE, b);
}

// ================= WIFI =================
void connectWiFi() {

  int retry_count = 0;

  while (retry_count < WIFI_MAX_RETRIES) {

    Serial.printf("[WIFI] Connecting (%d/%d)...\n", retry_count+1, WIFI_MAX_RETRIES);

    WiFi.begin(ssid, password);

    unsigned long start = millis();

    while (WiFi.status() != WL_CONNECTED &&
           millis() - start < WIFI_TIMEOUT_MS) {
      delay(500);
      Serial.print(".");
    }

    if (WiFi.status() == WL_CONNECTED) {
      Serial.println("\n[WIFI] Connected!");
      Serial.println(WiFi.localIP());
      return;
    }

    Serial.println("\n[WIFI] Failed");
    WiFi.disconnect(true);
    retry_count++;
  }

  Serial.println("[WIFI] Restarting ESP...");
  ESP.restart();
}

// ================= MDNS =================
void discoverMQTTBroker() {

  Serial.printf("[MDNS] Searching '%s.local' ... ", mqtt_hostname);

  IPAddress ip = MDNS.queryHost(mqtt_hostname);

  if (ip) {
    mqtt_server_ip = ip;
    Serial.print("FOUND: ");
    Serial.println(mqtt_server_ip);
  } else {
    Serial.println("NOT FOUND");
    mqtt_server_ip = IPAddress(0,0,0,0);
  }
}

// ================= MQTT =================
void connectMQTT() {

  Serial.print("[MQTT] Connecting... ");

  if (mqtt_server_ip == IPAddress(0,0,0,0)) {
    Serial.println("No broker IP");
    mqtt_available = false;
    return;
  }

  if (mqttClient.connect(mqtt_client_id)) {
    Serial.println("SUCCESS");
    mqtt_available = true;
    
    // ✅ ADDED: Subscribe to master heartbeat
    mqttClient.subscribe(master_heartbeat_topic);
  } else {
    Serial.println("FAILED");
    mqtt_available = false;
  }
}

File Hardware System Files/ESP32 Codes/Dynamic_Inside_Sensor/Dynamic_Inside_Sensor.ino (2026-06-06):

#include <WiFi.h>
#include <PubSubClient.h>
#include <Adafruit_SHT31.h>
#include <INA226_WE.h>
#include <ESPmDNS.h>
#include <Wire.h> // ✅ ADDED: Required for I2C sensors

// ================= WIFI =================
const char* ssid = "TP-Link_95CC";
const char* password = "11018605";

// ================= MQTT =================
const char* mqtt_hostname = "cvmpi";
const int mqtt_port = 1883;
const char* mqtt_client_id = "ESP32_InsideSensor1";

const char* temp_topic    = "/room/temp1";
const char* humid_topic   = "/room/humid1";
const char* voltage_topic = "/esp/voltage1";
const char* power_topic   = "/esp/power1";
const char* status_topic  = "/esp/status1";

// ✅ NEW: Heartbeat Topic
const char* master_heartbeat_topic = "/master/heartbeat";

const unsigned long send_interval = 30000;

// ================= WIFI RETRY =================
const unsigned long WIFI_TIMEOUT_MS = 10000;
const int WIFI_MAX_RETRIES = 2;

// ================= RGB LED PINS =================
#define LED_RED    27
#define LED_GREEN  26
#define LED_BLUE   25

#define CH_RED      0
#define CH_GREEN    1
#define CH_BLUE     2

#define LED_FREQ 5000
#define LED_RES     8

// ================= INA226 =================
#define INA226_ADDR 0x40
INA226_WE ina226 = INA226_WE(INA226_ADDR);

// ================= GLOBALS =================
IPAddress mqtt_server_ip;
Adafruit_SHT31 sht31 = Adafruit_SHT31();
WiFiClient espClient;
PubSubClient mqttClient(espClient);

bool sht_ok = false;
bool ina_ok = false;
bool system_ready = false;
bool mqtt_available = false;

float voltage_avg = 0;

// ✅ ADDED: Timer for non-blocking loop
unsigned long previousMillis = 0; 
unsigned long lastReconnectAttempt = 0;

// ✅ NEW: Master tracking variables
unsigned long last_master_heartbeat = 0;
bool master_alive = false;

// ================= FUNCTION DECLARATIONS =================
void setLED(uint32_t color);
void updateLED(float voltage);
void connectWiFi();
void discoverMQTTBroker();
void connectMQTT();

// ================= MQTT LISTENER =================
// ✅ NEW: This triggers instantly whenever the Python script pulses
void mqttCallback(char* topic, byte* payload, unsigned int length) {
  String msg = "";
  for (int i = 0; i < length; i++) {
    msg += (char)payload[i];
  }

  if (String(topic) == String(master_heartbeat_topic)) {
    if (msg == "ONLINE") {
      last_master_heartbeat = millis();
      master_alive = true;
    } 
    else if (msg == "OFFLINE") {
      master_alive = false; // Python script was manually shut down!
    }
  }
}

// ================= SETUP =================
void setup() {

  Serial.begin(115200);
  delay(1000);

  Serial.println("\n=== ESP32 SENSOR SYSTEM STARTING ===");

  // PWM setup
  ledcAttach(LED_RED, LED_FREQ, LED_RES);
  ledcAttach(LED_GREEN, LED_FREQ, LED_RES);
  ledcAttach(LED_BLUE, LED_FREQ, LED_RES);

  // LED initially off
  setLED(0x000000);

  Wire.begin(); // ✅ ADDED: Starts the I2C bus for SHT31 and INA226

  connectWiFi();

  if (MDNS.begin("ESP32Sensor")) {
    Serial.println("mDNS started");
  }

  discoverMQTTBroker();
  mqttClient.setServer(mqtt_server_ip, mqtt_port);
  mqttClient.setCallback(mqttCallback); // ✅ Tell MQTT to route incoming messages to our callback

  // ===== SENSOR CHECK =====
  if (sht31.begin(0x44)) {
    Serial.println("SHT31 initialized.");
    sht_ok = true;
  } else {
    Serial.println("SHT31 FAILED!");
    sht_ok = false;
  }

  if (ina226.init()) {
    Serial.println("INA226 initialized.");
    ina_ok = true;

    ina226.setResistorRange(0.1, 1.0);  // Calibration
    ina226.setAverage(INA226_AVERAGE_16);
    ina226.setConversionTime(INA226_CONV_TIME_1100);
    ina226.setMeasureMode(INA226_CONTINUOUS);

  } else {
    Serial.println("INA226 FAILED!");
    ina_ok = false;
  }

  if (sht_ok && ina_ok) {
    system_ready = true;
    Serial.println("System READY.");
  } else {
    system_ready = false;
    Serial.println("System NOT READY.");
  }
}

// ================= LOOP =================
void loop() {

  // ===== NETWORK MAINTENANCE =====
  if (WiFi.status() != WL_CONNECTED) {
    connectWiFi();
    discoverMQTTBroker();
    mqttClient.setServer(mqtt_server_ip, mqtt_port);
  }

  // Non-blocking MQTT reconnect (Checks every 5 seconds if disconnected)
  if (!mqttClient.connected() && WiFi.status() == WL_CONNECTED) {
    unsigned long now = millis();
    if (now - lastReconnectAttempt > 5000) {
      lastReconnectAttempt = now;
      discoverMQTTBroker();
      mqttClient.setServer(mqtt_server_ip, mqtt_port);
      connectMQTT();
    }
  }

  mqttClient.loop(); 

  // ✅ NEW: Check if the Master Controller's heartbeat flatlined (> 15 seconds)
  if (millis() - last_master_heartbeat > 15000) {
    master_alive = false; 
  }
  // ===== NON-BLOCKING SENSOR TIMER =====
  unsigned long currentMillis = millis();
  
  if (currentMillis - previousMillis >= send_interval) {
    previousMillis = currentMillis;

    // === NEW: SENSOR AUTO-RECOVERY ===
    if (!sht_ok) {
      sht_ok = sht31.begin(0x44);
    }
    if (!ina_ok) {
      if (ina226.init()) {
        ina226.setResistorRange(0.1, 1.0);
        ina226.setAverage(INA226_AVERAGE_16);
        ina226.setConversionTime(INA226_CONV_TIME_1100);
        ina226.setMeasureMode(INA226_CONTINUOUS);
        ina_ok = true;
      }
    }
    // Re-evaluate overall system health
    system_ready = (sht_ok && ina_ok);
    // ==================================
    if (!system_ready) {
      if (mqtt_available) {
        String errorMsg = "ERROR:";
        if (!sht_ok) errorMsg += " SHT31_FAIL";
        if (!ina_ok) errorMsg += " INA226_FAIL";
        mqttClient.publish(status_topic, errorMsg.c_str());
      }
    } 
    else {
      // NORMAL OPERATION
      float temp = sht31.readTemperature();
      float humid = sht31.readHumidity();
      float voltage = ina226.getBusVoltage_V();
      float power   = ina226.getBusPower();

      // Weighted average filter
      if (voltage_avg == 0) {
        voltage_avg = voltage;
      } else {
        voltage_avg = (voltage_avg * 9 + voltage) / 10;
      }

      // Publish only if MQTT AND both sensors are OK
      if (mqtt_available && sht_ok && ina_ok) {
        Serial.printf("Temp: %.2f °C | Hum: %.2f %% | V: %.2f V | P: %.2f W\n",
                    temp, humid, voltage, power);

        mqttClient.publish(temp_topic, String(temp, 2).c_str());
        mqttClient.publish(humid_topic, String(humid, 2).c_str());
        mqttClient.publish(voltage_topic, String(voltage, 2).c_str());
        mqttClient.publish(power_topic, String(power, 2).c_str());
        mqttClient.publish(status_topic, "OK");
      }
      else if (mqtt_available) {
        String errorMsg = "ERROR:";
        if (!sht_ok) errorMsg += " SHT31_FAIL";
        if (!ina_ok) errorMsg += " INA226_FAIL";
        mqttClient.publish(status_topic, errorMsg.c_str());
      }
    }
  } // End of 30-second timer
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

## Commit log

2026-06-07 Script 5 - Calibration Scoring & Model Evaluation
2026-06-07 Script 6 - Bayesian Calibration Optimization Loop
2026-06-07 Script 11 - Calibration Data Extraction
2026-06-07 Script 7 - Calibration Data Extraction
2026-06-07 Script 6 - Calibration Scoring & Model Evaluation
2026-06-07 Script 7 - Bayesian Calibration Optimization Loop
2026-06-13 Rename Screenshot 2026-05-30 002335.png to Raspberry Pi 5 Enclosure Assembly
2026-06-13 Rename Raspberry Pi 5 Enclosure Assembly to Raspberry Pi 5 Enclosure Assembly.png
